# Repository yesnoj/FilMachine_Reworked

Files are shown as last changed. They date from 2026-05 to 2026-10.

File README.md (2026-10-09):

# FilMachine — Automated Film Development Machine

FilMachine is an automated film processing machine designed for photographic film development. It handles the entire process: chemical baths, water rinses, temperature regulation, and motor-driven film agitation — all controlled through a 4.3" color touchscreen display.

The project includes a **desktop simulator** (SDL2 + LVGL) that reproduces the full touchscreen UI on macOS/Linux (a Windows build is produced by CI), enabling rapid development and testing without physical hardware, plus an **automated test suite** (19 suites). A **Flutter companion app** connects via WebSocket and provides full remote control from any mobile device on the same network.

The interface is **bilingual (English / Italiano)** — selectable from Settings, applied with an automatic reboot — and every boot writes a **diagnostic log to the SD card** (`/log/boot_NNNN.txt`), including the crash summary of the previous run when the firmware panicked.

The repository also holds the mechanical side of the project: the 3D-printed **film reel auto-loader** (bench prototype v1, for 135 and 120 film) — see [Film Reel Auto-Loader](#film-reel-auto-loader-3d-printed-prototype).

---

## Table of Contents

1. [What is FilMachine?](#what-is-filmachine)
2. [Project Architecture](#project-architecture)
3. [Directory Structure](#directory-structure)
4. [Building the Project](#building-the-project)
5. [Running the Simulator](#running-the-simulator)
6. [Running the Tests](#running-the-tests)
7. [WebSocket Server & Remote Control](#websocket-server--remote-control)
8. [Flutter Companion App](#flutter-companion-app)
9. [User Interface Guide](#user-interface-guide)
10. [Firmware Update (OTA)](#firmware-update-ota)
11. [Hardware Specifications](#hardware-specifications)
12. [Bill of Materials (Components)](#bill-of-materials-components)
13. [Film Reel Auto-Loader (3D-Printed Prototype)](#film-reel-auto-loader-3d-printed-prototype)
14. [Diagnostics & Bring-up Page](#diagnostics--bring-up-page)
15. [Build-time Switches](#build-time-switches)
16. [Configuration & Persistence](#configuration--persistence)
17. [Language / Localization](#language--localization)
18. [SD Boot & Crash Log](#sd-boot--crash-log)
19. [Typical Workflows](#typical-workflows)
20. [Developer Quick Reference](#developer-quick-reference)
21. [Authors](#authors)

---

## What is FilMachine?

FilMachine takes the guesswork out of developing photographic film at home or in a small lab. Instead of manually timing each step, pouring chemicals by hand, and constantly checking the thermometer, FilMachine automates everything. You load your film in the developing tank, select a process, and press Start. The machine takes care of the rest: filling the right chemical at the right time, keeping the temperature stable, rotating the film at the correct speed, rinsing between steps, and alerting you when the process is complete.

It supports both **color negative** (C41, E6) and **black & white** film development workflows, with full customization of every parameter.

---

## Project Architecture

The project has a **dual-target build system** that produces ESP32-P4 firmware or a native desktop application from the same codebase. The only supported hardware board is the **Guition JC4880P433** (ESP32-P4).

### Technology Stack

| Layer | Firmware (ESP32-P4) | Simulator (macOS/Linux) |
|---|---|---|
| **UI Library** | LVGL 9.5.0 | LVGL 9.5.0 (identical) |
| **Display** | ST7701S 480×800 MIPI-DSI → landscape 800×480 via PPA | SDL2 window (800×480) |
| **Touch Input** | GT911 (physical 480×800 → remapped to 800×480) | SDL2 mouse events |
| **Storage** | FatFS on MicroSD (SDMMC 4-bit, ~40 MB/s) | POSIX file I/O (sd/ directory) |
| **RTOS** | FreeRTOS (ESP-IDF) | Stub (queues work, tasks are no-ops) |
| **2D Acceleration** | PPA hardware engine (rotate, scale, blend, fill) | — |
| **Audio** | ES8311 codec via I2S + power amplifier | — |
| **Temp Sensors** | DS18B20 OneWire | Simulated (20°C ambient, heater model) |
| **Motor/Pump** | DBH-12V dual H-bridge (motor ch.A + pump ch.B) + MCP23017 solenoid driver | printf stubs |
| **OTA Updates** | esp_ota_ops + esp_http_server | Simulated (progress timer) |
| **Build Tool** | ESP-IDF (`idf.py`) | CMake + Make |
| **Sensors** | Flow meter, water level, hall effect | Simulated |
| **Compiler** | riscv32-esp-elf-gcc | Native cc/gcc/clang |

### How the Simulator Works

The simulator replaces all hardware-specific code with a **stub layer** that provides compatible implementations:

- **FatFS stubs** map firmware paths (e.g., `/FilMachine.json`) to files inside an `sd/` subdirectory of the directory the simulator is launched from, so read/write operations work transparently.
- **FreeRTOS stubs** provide working queue implementations (xQueueCreate, xQueueSend, xQueueReceive) using simple circular buffers. Task creation is a no-op since there are no real threads — instead, the main loop drains the system queue every frame.
- **Hardware stubs** (GPIO, I2C, SPI, solenoid driver, motor, temperature) are either no-ops or printf-based logging functions. Temperature readings come from a simple thermal model that simulates heating/cooling.
- **OTA stubs** simulate the firmware update flow with a progress timer (0→100%) and fake IP address, allowing full UI testing without real hardware.
- **LVGL's SDL2 driver** provides the display backend and mouse input, which simulates the capacitive touchscreen.

The key architectural principle is that **all UI code is shared 1:1** between firmware and simulator. Pages, elements, event handlers, and business logic are identical — only the hardware abstraction layer changes.

---

## Directory Structure

```
FilMachine_Reworked/
│
├── main/                          # Core source (shared with ESP32 firmware)
│   ├── include/
│   │   └── FilMachine.h           #   Main header — all structs, enums, constants, prototypes
│   ├── FilMachine.c               #   ESP32 entry point — board-conditional display/touch init
│   ├── accessories.c              #   Utilities — linked lists, deep copy, config I/O, keyboard
│   ├── lang.c                     #   EN/IT string table (generated by scripts/gen_lang.py)
│   ├── sd_log.c                   #   Boot/crash logger on SD (/log/boot_NNNN.txt, firmware only)
│   ├── mini_json.c                #   Dependency-free JSON parser for the config file
│   ├── ota_update.c               #   OTA firmware update (SD card + Wi-Fi web server)
│   ├── ws_server.c                #   WebSocket server for Flutter companion app
│   ├── film_loader.c              #   Film loading cycle (wind, stall detect, cut, tail) — Tools → Load film
│   └── ui_profile.c               #   Centralized UI layout constants (800×480)
│
├── c_pages/                       # UI pages (screens)
│   ├── page_splash.c              #   Splash screen — standard, random, and custom modes with
│   │                              #     10 palettes, 6 shape styles, 9 title fonts, PRNG engine
│   ├── page_menu.c                #   Tab bar navigation (Processes / Settings / Tools)
│   ├── page_processes.c           #   Process list with filtering
│   ├── page_processDetail.c       #   Process creation & editing
│   ├── page_stepDetail.c          #   Step creation & editing with validation
│   ├── page_settings.c            #   Machine settings, grouped in sections (process, rotation, liquids, display, system)
│   ├── page_tools.c               #   Maintenance tools, import/export, statistics, OTA
│   ├── page_checkup.c             #   Process execution — the most complex page
│   └── page_debug.c               #   Hidden diagnostics / bring-up page (live sensors, output tests)
│
├── c_elements/                    # Reusable UI components
│   ├── element_process.c          #   Process list item (drag, delete, duplicate)
│   ├── element_step.c             #   Step list item (swipe gestures, edit/delete)
│   ├── element_filterPopup.c      #   Filter dialog (name, type, preferred)
│   ├── element_messagePopup.c     #   Generic confirmation/alert popups
│   ├── element_rollerPopup.c      #   Numeric selector (roller) widget
│   ├── element_calibPopup.c       #   Dual temperature calibration popup (bath + chemistry offsets)
│   ├── element_speedPopup.c       #   Pump / motor speed tuning popup with live test
│   ├── element_fillPopup.c        #   Maintenance "Fill bath" popup (auto-stop on level, flow or timeout)
│   ├── element_loadPopup.c        #   Film loading popup (135/120, progress, Cut now, blade test)
│   ├── element_cleanPopup.c       #   Cleaning process UI with timer
│   ├── element_drainPopup.c       #   Drain process UI with animated tank bars
│   ├── element_splashPopup.c      #   Splash screen config popup with live preview
│   ├── element_selfcheckPopup.c   #   Self-check diagnostic wizard (8-phase hardware test)
│   ├── element_otaWifiPopup.c     #   Wi-Fi OTA update popup (IP + PIN + progress)
│   └── element_wifiPopup.c       #   Wi-Fi connection popup (scan, connect, status)
│
├── c_fonts/                       # Custom icon fonts (7 sizes: 15/20/30/40/50/60/100px)
│   │                              #   + 8 custom splash title fonts (48px) + Montserrat 64
├── drivers/                       # Custom peripheral drivers (ESP-IDF compatible)
│   ├── include/                   #   Driver headers (mcp23017.h, ds18b20.h, sensors.h, audio.h, servo.h)
│   ├── mcp23017.c                 #   I2C 16-bit I/O expander (Adafruit solenoid driver)
│   ├── ds18b20.c                  #   OneWire temperature sensor (shared bus)
│   ├── audio.c                    #   ES8311 codec bring-up + tone/volume (board only)
│   ├── servo.c                    #   Cutter servo, LEDC 50 Hz PWM on GPIO 28 (board only)
│   └── sensors.c                  #   Flow meter, water level, hall effect sensors (+ reel pulse counter)
│
├── components/                    # ESP32-P4 specific hardware drivers
│   ├── st7701_lcd/                #   ST7701S MIPI-DSI LCD driver (480×800)
│   ├── ppa_engine/                #   PPA hardware 2D accelerator (rotate, scale, fill, blend)
│   ├── driver/                    #   ESP-IDF driver compatibility shims
│   └── espressif__esp_lcd_touch/  #   Touch panel abstraction layer
│
├── src/
│   └── main.c                     # Simulator entry point (SDL2 display, main loop,
│                                  #   demo data generator, system queue drain)
│
├── stub/                          # Hardware abstraction for simulator
│   ├── esp_stubs.h/c              #   ESP32 GPIO, timer, heap stubs
│   ├── fatfs_stubs.h/c            #   FatFS → POSIX filesystem mapping
│   ├── freertos_stubs.h/c         #   Queue stubs (circular buffer), task stubs (no-op)
│   ├── driver/                    #   GPIO, I2C, LEDC, SDMMC driver stubs
│   └── (redirect headers)         #   Thin #include wrappers for ESP-IDF compatibility
│
├── tests/                         # Automated test suite
│   ├── test_runner.h/c            #   Test framework & entry point
│   ├── test_helpers.c             #   Touch input simulation
│   ├── test_navigation.c          #   Splash, menu, tab switching
│   ├── test_processes.c           #   Process list display & creation
│   ├── test_process_crud.c        #   Process create/read/update/delete
│   ├── test_steps.c               #   Step creation, swipe, deletion
│   ├── test_step_crud.c           #   Step lifecycle
│   ├── test_execution.c           #   Process checkup execution flow
│   ├── test_persistence.c         #   Config save/load/restore
│   ├── test_settings.c            #   Settings UI & validation
│   ├── test_filter.c              #   Filter logic
│   ├── test_tools.c               #   Maintenance tools
│   ├── test_edge_cases.c          #   Boundary conditions & error paths
│   ├── test_utilities.c           #   Helper function tests
│   ├── test_ota.c                 #   OTA update UI & Wi-Fi popup tests
│   ├── test_websocket.c           #   WebSocket command tests
│   ├── test_new_settings.c        #   Extended settings tests
│   ├── test_selfcheck.c           #   Self-check wizard tests
│   ├── test_live_sync.c           #   Live sync integration tests
│   ├── test_ui_profile.c          #   UI profile validation & sensor stubs
│   ├── test_film_loader.c         #   Film loader state machine, safety checks, popup
│   ├── test_maintenance_remote.c  #   Drain / Clean / Export driven by WebSocket commands
│   └── test_destroy_and_lifecycle.c # Memory cleanup & object destruction
│
├── lvgl/                          # LVGL 9.5.0 library (auto-cloned on first build, gitignored)
├── lvgl_config/
│   └── lv_conf.h                  # LVGL configuration (RGB565, C-library malloc as on the board, dark theme)
│
├── boards/                        # Board-specific hardware definitions
│   ├── board.h                    #   Board selector (includes correct board header)
│   ├── board_jc4880p433.h         #   JC4880P433 pin assignments, peripherals, H-bridge config
│   └── board_simulator.h          #   Simulator stubs (matching pin constants)
│
├── scripts/
│   ├── genFilMachineCFG.py        # SD config generator (FilMachine.json with realistic film recipes)
│   ├── gen_lang.py                # EN/IT string table generator (holds the Italian dictionary)
│   └── bump_version.sh            # Increments the BUILD field of version.txt
│
├── hardware/
│   └── FilMachine_Breakout_v1/    # KiCad project + BOM: breakout board for the Expand IO header
│
├── 3D_Models/
│   └── FilMachine_caricatore_v1/  # 3D-printed film reel auto-loader: STEP, STL, previews,
│                                  #   CadQuery source and its own README (in Italian)
│
├── docs/
│   └── hardware_architecture.svg  # System architecture diagram (shown under Hardware Specifications)
├── tools/
│   └── lvgl_splash_generator.jsx  # Splash-screen generator (React component that emits LVGL C code)
├── data/                          # Sample SD config files (FilMachine.json + legacy .cfg), not used by the build
├── .github/workflows/
│   └── windows-sim.yml            # CI: builds the simulator for Windows (MSYS2/MinGW)
│
├── CMakeLists.txt                 # Dual-target build (ESP-IDF P4 + simulator/tests)
├── version.txt                    # Firmware version, MAJOR.MINOR.PATCH.BUILD (single source of truth)
├── partitions.csv                 # Custom OTA partition table (16 MB flash)
├── sdkconfig.defaults             # ESP-IDF shared defaults
├── sdkconfig.defaults.esp32p4     # ESP-IDF defaults for ESP32-P4 target
├── flash_p4.sh                    # All-in-one build + flash + monitor for the ESP32-P4 board (macOS)
├── ui_debug_registry.inc          # Widget-name registry for the simulator's F2 debug overlay
├── COMMANDS.md                    # Quick command reference (in Italian)
├── AUDIT_REPORT.md                # Firmware/app audit of 6 July 2026 (firmware v0.0.0.50)
├── FilMachine_Custom_PCB_BOM.xlsx # Design worksheet for a custom PCB: BOM, pin maps, power budget (in Italian)
├── DistintaComponenti.xlsx        # Parts list with specs, quantities, prices and links (in Italian)
├── MDC_db.csv                     # Film/developer development-time table (9,142 rows; not read by the firmware yet)
├── setup.sh                       # Legacy: one-off script that built the old Simulator_v2 folder (not needed)
└── flash.sh                       # Legacy: ESP32-S3 flash through the old FilMachine_Pete repo (not for the P4)
```

---

## Building the Project

### Prerequisites

**macOS:**
```bash
brew install cmake sdl2 pkg-config
```

**Ubuntu / Debian:**
```bash
sudo apt install cmake libsdl2-dev pkg-config build-essential
```

LVGL v9.5.0 is automatically cloned from GitHub on the first build if not present (the firmware pulls the same version through the ESP-IDF component manager, `lvgl/lvgl ~9.5.0`).

**Windows:** there is no local recipe; the GitHub Actions workflow `.github/workflows/windows-sim.yml` builds `filmachine_sim.exe` with MSYS2/MinGW on every push to `main` that changes more than the documentation (or on demand from the Actions tab) and uploads it — with its runtime DLLs and a freshly generated `sd/` config — as the `filmachine-sim-windows` artifact.

### Build the Simulator

```bash
mkdir -p build800 && cd build800
cmake ..
make filmachine_sim
```

The simulator opens an 800×480 window matching the JC4880P433 physical panel in landscape orientation.

### Build the Tests

```bash
mkdir -p build800 && cd build800
cmake ..
make filmachine_test
./filmachine_test
```

### Build the Firmware

Requires the [ESP-IDF](https://docs.espressif.com/projects/esp-idf/en/latest/) toolchain (**v5.5.x** or later) installed and configured.

**Important:** run `idf.py` from the **project root**, not from `build800/`.

```bash
cd FilMachine_Reworked
. $HOME/esp/esp-idf-v5.5/export.sh     # Must be ESP-IDF 5.5.x or later

# First-time setup: set target to esp32p4 (creates sdkconfig from defaults)
idf.py set-target esp32p4

# Build — board is auto-detected from IDF_TARGET
idf.py build
```

The `main/CMakeLists.txt` automatically sets `-DBOARD_JC4880P433`. No manual `-DCMAKE_C_FLAGS` flag is needed (passing `-D CMAKE_C_FLAGS="-DBOARD_JC4880P433"` is harmless but redundant).

> **See [`COMMANDS.md`](COMMANDS.md)** for the canonical quick reference: simulator + board build, flash/monitor, generating and copying the SD config, version bumping and cleanup.

#### Flash and monitor

The firmware binary is produced at `build/FilMachine.bin`. To flash it directly to a connected board:

```bash
idf.py flash
```

Or use the all-in-one helper (written for macOS), which sets the target if needed, patches `sdkconfig` for the P4 board, increments the build number in `version.txt`, builds, looks for the serial port, flashes and opens the monitor:
```bash
./flash_p4.sh
```

> `flash.sh` and `setup.sh` are leftovers of the earlier ESP32-S3 workflow (they copy sources between the old `FilMachine_Simulator_v2` folder and the `FilMachine_Pete` repository). They are not used for the ESP32-P4 and can be ignored.

**P4 note:** the bootloader offset on ESP32-P4 is `0x2000` (different from ESP32-S3's `0x0`). This is handled automatically by `idf.py` when the target is set correctly.

To check the firmware size (useful for verifying OTA partition fit):
```bash
idf.py size
```

---

## Running the Simulator

### Simulator UI debug overlay

The simulator includes a built-in UI inspection mode to speed up layout tuning.

- Press **F2** to enable or disable the overlay.
- When enabled, moving the mouse over the UI shows:
  - the resolved component name when available (for example `gui.page.processes.newProcessButton`)
  - the object position (`x`, `y`)
  - the object size (`w`, `h`)
- While the overlay is enabled, **right click** dumps the hovered object to the terminal/console.

This is especially useful when adjusting coordinates inside `ui_profile.c`, because you can identify the exact widget and immediately see its current geometry in the simulator.

```bash
cd build800
./filmachine_sim
```

The simulator opens an 800×480 window that reproduces the exact touchscreen interface. Use the mouse to simulate touch input (click = tap, click-drag = swipe/scroll).

### What works in the simulator

- Full UI navigation (all pages, popups, dialogs)
- Splash screen with live preview popup, 10 palettes, 6 shape styles, 9 custom fonts
- Process creation, editing, duplication, deletion
- Step management with swipe gestures
- Settings with slider/switch/radio controls
- Filter and search functionality
- Configuration save/load (reads/writes `sd/FilMachine.json`)
- Export/Import (backup to `sd/FilMachine_Backup.json`)
- Drain machine with animated tank-level bars and relay management
- Clean machine with per-container rinse cycles and arc progress
- Self-check diagnostic wizard with 8-phase hardware test simulation (temp sensors, pump, heater, valves, containers, motor)
- OTA update UI (SD card check + Wi-Fi popup with simulated IP/PIN/progress)
- Simulated temperature readings with heater model and calibration offset
- Persistent alarm sound (SDL audio 880Hz beep, repeats every 10s until dismissed)
- Drain/fill overlap processing (adjusts step timing based on overlap percentage)
- Machine statistics persistence (saved in config file, survives restart)
- Temperature sensor calibration (Tune button calculates and applies offset)
- Console logging of all system actions (`[SIM] sysAction: ...`)
- WebSocket server on port 81 for Flutter companion app remote control
- Full remote process start, stop, and checkup advance via WebSocket
- Remote CRUD for processes and steps (create, edit, delete from Flutter)

### What is simulated (no real hardware)

- Temperature sensors return simulated values (20°C ambient, gradual heating/cooling)
- Motor control outputs to console only
- Relay switching outputs to console only
- OTA writes to a fake partition (progress simulated, no actual flash)
- Wi-Fi connection is simulated (fake IP 192.168.1.42, no real server)
- Reboot is a no-op (prints message)

### Generating sample data

To generate realistic film development recipes:

```bash
python3 scripts/genFilMachineCFG.py --realistic --output build800/sd/
```

This creates config files with authentic C41, E6, and B&W development processes.

---

## Running the Tests

```bash
cd build800
./filmachine_test
```

Results are displayed in the terminal and saved to `test_results/test_results_YYYYMMDD_HHMMSS.txt`.

### Test Suites

| Suite | Description |
|---|---|
| **Navigation** | Splash screen, menu display, tab switching |
| **Processes** | Process list rendering, creation UI |
| **Process CRUD** | Full create/read/update/delete lifecycle |
| **Steps** | Step creation, swipe gestures, deletion |
| **Step CRUD** | Step lifecycle with validation |
| **Execution** | Process checkup and execution flow |
| **Persistence** | Config save → reload → verify all fields, stats persistence, calibration offset |
| **Settings** | Settings UI, default values, slider/switch behavior, calibration, alarm |
| **Filter** | Filter by name, film type, preferred flag |
| **Tools** | Cleaning, draining, statistics display, timer pause/resume, alarm functions |
| **Edge Cases** | Boundary conditions, max limits, error recovery |
| **Utilities** | Helper functions, linked list operations, drain/fill overlap calculation |
| **UI Profile & Sensors** | Profile values match original, popup dimensions, font pointers, sensor stubs, board constants |
| **OTA** | OTA update UI, Wi-Fi popup PIN generation, progress popup |
| **WebSocket** | WebSocket command handling, async LVGL dispatch |
| **New Settings** | Extended settings validation |
| **Self-check** | Self-check diagnostic wizard phases |
| **LiveSync** | Live sync between WebSocket state and LVGL UI |
| **Destroy & Lifecycle** | Memory cleanup, object destruction |
| **Film loader** | Loading cycle 135/120, early stall / no spin / too long errors, Cut now, Stop, blade test, popup from the app |
| **Maintenance from the app** | Drain and Clean started, stopped and closed by WebSocket commands (popups on the display, state fields), only the selected containers cleaned, one tool at a time, no process while one runs, Export queued with its result in the state |

The persistence tests verify that every field (process name, temperature, tolerance, film type, preferred flag, step names, durations, types, sources, discard flags) survives a full save-and-reload cycle.

**Repeatable runs.** Every run starts from the same data: the runner generates three test processes with the default settings and rewrites `sd/FilMachine.json` in the run directory, so a run never depends on what the previous one saved (steps used to pile up on the first process until the 30-step limit made the step tests fail). `FM_TEST_ONLY=<suite>,<suite>` runs only some suites (names after `test_suite_`, e.g. `FM_TEST_ONLY=navigation,tools`).

**Timers run on real time.** The SDL display makes LVGL read the real clock, so `test_pump()` processes events but does not advance LVGL timers; tests that wait for a 1 s timer sleep (see `pump_real()` in `test_maintenance_remote.c`).

**Memory.** The simulator and the tests use the C-library `malloc` for LVGL, like the board. With LVGL's own 256 KB pool the heap fragmented after a few suites, an allocation failed and LVGL's malloc assert spun forever, which looked like random hangs in the step tests. To check memory errors, build the runner with `-fsanitize=address`: AddressSanitizer then sees LVGL's allocations too.

---

## WebSocket Server & Remote Control

The simulator and firmware include a built-in WebSocket server (`ws_server.c`) that enables remote control from the Flutter companion app or any WebSocket client. The server starts automatically and listens on **port 81** at path `/ws`.

### Supported Commands

All commands use JSON format: `{"cmd":"command_name", ...params}`.

| Command | Parameters | Description |
|---|---|---|
| `get_state` | — | Returns full machine state (settings, runtime, temperatures, progress, alarms, maintenance fill, film loader, drain, clean and export status) |
| `get_processes` | — | Returns complete process list with steps, indexed for remote referencing |
| `start_process` | `index` | Start a process by list index; initializes checkup and begins execution |
| `checkup_advance` | — | Advance to next checkup phase (Setup → Fill → Temp → Check → Processing) |
| `stop_now` | — | Immediately halt the running process and drain |
| `stop_after` | — | Stop after the current step completes |
| `close_process` | — | Close a finished/stopped process and free checkup resources |
| `create_process` | `name, temp, tolerance, filmType, tempControlled, preferred` | Create a new process |
| `edit_process` | `index, name, temp, tolerance, filmType, tempControlled, preferred` | Edit an existing process |
| `delete_process` | `index` | Delete a process |
| `add_step` | `processIndex, name, mins, secs, type, source, discard` | Add a step to a process |
| `edit_step` | `processIndex, stepIndex, name, mins, secs, type, source, discard` | Edit a step |
| `delete_step` | `processIndex, stepIndex` | Delete a step |
| `reorder_step` | `processIndex, from, to` | Move a step within a process |
| `set_setting` | `key, value` | Update a machine setting (see key list below) |
| `reset_defaults` | — | Restore all settings to factory defaults |
| `wifi_scan` | — | Scan for Wi-Fi networks; results arrive via a `wifi_scan_results` event |
| `fill_start` / `fill_stop` | `target` (0 = water bath, 1 = chemistry) | Maintenance fill (self-calibrates the fill time; refused with `fill_rejected` while a process runs) |
| `tune_test` / `tune_set` / `tune_cancel` | `kind` (0 pump, 1 motor, 2 volume), `percent`, `on` | Live test, store or cancel a Tune value |
| `drain_start` / `drain_stop` / `drain_close` | — | Drain machine: start (no confirm page, the app asks), Stop, Close after the end (alarm off, popup closed). Refused with `drain_rejected` while a process or another maintenance tool runs |
| `clean_start` | `mask` (bit0 C1, bit1 C2, bit2 C3), `cycles` (1–5), `drainWb` | Clean machine with these choices (shown on the display popup). Refused with `clean_rejected` (`processing`, `busy`, `no_container`) |
| `clean_stop` / `clean_close` | — | Clean: Stop (the container is pumped back first) / Close after the end |
| `export_config` | — | Export configuration and processes to the backup file on the SD card; the result arrives as `exportSeq` / `exportOk` in the state |
| `load_start` | `format` (0 = 135, 1 = 120) | Start loading the film onto the reel (refused with a `load_rejected` event while a process runs or a load is in progress) |
| `load_stop` | — | Stop the loading (motor off, blade back to rest) |
| `load_cut` | — | Cut now, without waiting for the reel to stop |
| `cutter_test` | `angle` (0–180) | Hold the cutter servo at that angle for a few seconds (setup) |
| `cutter_cycle` | — | One blade up/down cycle, motor off |

The `cleanTool*` state fields include `cleanToolProcessArc`, `cleanToolCycleArc` and `cleanToolPumpArc`: the values of the three arcs exactly as drawn on the display's Clean popup, so the app draws the same picture.

**`set_setting` keys** — `tempUnit`, `waterInlet`, `tempCalibOffset`, `chemCalibOffset`, `filmRotationSpeed`, `rotationInterval`, `random`, `persistentAlarm`, `autostart`, `drainFillOverlap`, `multiRinseTime`, `lineRinseEnabled`, `lineRinseTime`, `tankSize`, `pumpSpeed`, `chemCalibFillSecs`, `wbCalibFillSecs`, `chemistryVolume`, `invertPump`, `brightness`, `volume`, `splashDefault`, `splashRandom`, `splashPalette`, `splashShapeStyle`, `splashComplexity`, `language` (0=EN, 1=IT — applied at next boot), `screenOffMins` (5/10/30, 0=never), `wifiEnabled`, `loadSpeed` (reel motor % while loading), `cutterRestUs` / `cutterCutUs` (servo pulse in µs at rest and at the top of the cut). All of these are also included in the broadcast state JSON.

### Implementation Details

The server uses simple `strstr()` JSON parsing with no external library (no cJSON, no heap allocation for parsing). All commands that modify LVGL state are dispatched via `lv_async_call()` to ensure thread-safe UI updates. State changes are automatically broadcast to all connected clients.

---

## Flutter Companion App

The companion app is a Flutter application that provides full remote control of FilMachine from any mobile device or desktop on the same network. It lives in its own repository, [FilMachine_App](https://github.com/yesnoj/FilMachine_App) (private); see its README for detailed documentation.

**Keeping the two in step.** The app mirrors the protocol implemented in `main/ws_server.c`. Whenever a field is added to `build_state_json()` or a key to `set_setting`, the app needs the same addition in its `MachineState` model, in `MachineService._readSetting` and in its Settings screen. The app release synced with firmware v0.0.0.54 parses all 71 state fields and sends all 17 commands; the only `set_setting` keys it never sends are the fill calibrations (read-only in the app) and `wifiEnabled`.

### Key Features

- **Device Discovery**: Automatic mDNS discovery of FilMachine devices on the local network (`_filmachine._tcp`), plus manual IP/port entry
- **Process Management**: Create, edit, duplicate, and delete processes and steps — all changes sync to the machine in real-time
- **Live Execution Monitoring**: Real-time dashboard showing current step, progress bars, temperatures, tank fill status, and elapsed/remaining time
- **Process Control**: Start processes, advance through checkup phases, Stop Now / Stop After with confirmation dialogs
- **Filtering**: Client-side filtering by name, film type (B&W / Color), and preferred flag
- **Statistics**: View completed processes, stopped processes, total development time, cleaning cycles
- **Settings**: Full access to the machine settings, with the same sections as the display (Process, Film rotation, Pump and liquids, Display and sound, System) plus the app's own options
- **Tools**: A Tools tab laid out like the display's: Maintenance (Clean machine, Drain machine, Fill bath, Fill chem, Load film), Utilities (Export) and Software (Credits). Self-check, Import (it reboots the machine) and the firmware updates (the Wi-Fi one shows a PIN on the display on purpose) stay on the display; statistics, version and serial number are on the app's Dashboard
- **Theme**: Dark/light theme toggle with custom FilMachine color palette
- **Persistent Connection**: Remembers last successful connection for quick reconnect

### Architecture

The app uses **Provider** for state management. A central `MachineService` (ChangeNotifier) maintains the WebSocket connection and holds the current `MachineState` — a data class with one field per key of the JSON state broadcast. All screens rebuild reactively when state changes.

---

## User Interface Guide

### The Processes Tab

This is where you manage your film development recipes. Each process is a sequence of steps the machine executes in order. The list shows each process with its name, total time, film type icon, and a star if marked as preferred.

- **Process count:** The section header dynamically shows the number of processes (e.g., "8 Processes"). The "+" button stays positioned right after the label text regardless of the count.
- **Create:** Tap "+" to add a new process
- **Edit:** Tap a process to open its detail view
- **Duplicate:** Swipe left to reveal the duplicate button
- **Delete:** Open the detail, tap the trash icon
- **Filter:** Tap the filter icon to search by name, film type, or preferred status. The filter icon turns green when a filter is active, and returns to white when reset.

### Working with Steps

Each process contains steps. A step represents one phase: "Developer", "Stop Bath", "Fixer", "Wash", etc.

For each step you configure: name, duration (minimum 30 seconds), chemical type (Chemistry / Rinse / Multi-Rinse), source container (C1, C2, C3, or WB), and whether to discard the chemical after use.

The three step types behave differently during execution: a **Chemistry** step fills once from a container and soaks for the whole step time (liquid recovered or discarded per the flag). A **Rinse** step fills once (from any source), soaks, and always discards to waste at the end. A **Multi-Rinse** step is not a single soak: the tank is repeatedly filled with fresh water (always from the water bath), agitated for one *cycle* — the "Multi-rinse cycle time" setting — then fully drained to waste, over and over until the step's total duration elapses. If the total time isn't an exact multiple of the cycle time, the last cycle runs longer so the step still ends exactly on time. This matches the Adeo dev.a behaviour and is ideal for final washes where the water must be changed frequently.

- **Add:** Tap "+" below the step list
- **Edit:** Tap a step to modify it
- **Duplicate:** Swipe left on a step
- **Delete:** Swipe left to reveal the delete button
- **Reorder:** Long-press and drag

### Running a Process (Checkup)

Open a process and tap Play. The machine walks through pre-flight checks, then executes each step automatically.

**Pre-flight checks:** tank size selection, water bath fill, tank presence verification, motor check, and temperature stabilization (for temperature-controlled processes).

**During execution:** the screen shows the current step name and remaining time, chemical source, current/target temperature, and upcoming steps.

**Stopping:** "Stop now!" halts immediately (potentially unsafe). "Stop after!" waits for the current step to finish — the safer choice.

### Splash Screen

The splash screen appears at boot and supports three modes, configured via Settings → Splash Screen:

**Use Default** — The built-in "Deep Ocean" splash: a hand-tuned composition with a teal-to-navy gradient, geometric shapes, and the "FILMACHINE" title in Montserrat 48. This is the factory default.

**Random next boot** — Each boot generates a completely new splash from scratch using a tick-derived seed. The PRNG (xorshift32) deterministically selects a palette, shape style, complexity, title position, and title font — producing a unique visual identity every time the machine starts.

**Custom** — Fine-tune the splash parameters manually: Palette (10 options), Shape Style (6 options), and Complexity (20–100 in steps of 20). The popup shows a live preview of the current configuration as the background behind its own controls, with a dark overlay for readability. Press the Random button to regenerate all parameters at once; if you like the result, it will be applied at next boot. The preview shows only the shape background (no title or play button) so you can evaluate the pattern clearly.

**Title fonts** — In Random and Custom modes, the title "FILMACHINE" is rendered with one of 9 fonts selected by the PRNG:

| Index | Font Name | Style |
|---|---|---|
| 0 | Montserrat 48 | Default sans-serif (same as Deep Ocean) |
| 1 | Air Americana | Bold italic display |
| 2 | Decaying Felt Pen | Hand-drawn brush effect |
| 3 | DS Digital | LED/LCD digital display |
| 4 | Evanescent | Ethereal and elegant |
| 5 | Nerdropol Lattice | Geometric/tech |
| 6 | Retrolight | Retro/vintage |
| 7 | Tropical Leaves | Decorative botanical |
| 8 | Wishful Melisande | Calligraphic script |

All fonts are converted from TTF/OTF to LVGL `.c` bitmap arrays using `lv_font_conv` with `--no-compress --bpp 4 --range 0x20-0x7F` (ASCII only, ~20–40KB each in flash).

**Palettes** — Cyberpunk, Aurora, Lava, Deep Ocean, Forest, Sunset, Machinery, Arctic, Neon, Pastel. Each defines a top/bottom gradient, 3 shape accent colors, and text/accent colors for the title.

**Shape Styles** — Overlapping Rects, Circles & Arcs, Mixed Shapes, Diagonal Bands, Grid Blocks, Radial Arcs.

### The Settings Tab

The settings are grouped in sections, like the Tools tab; the whole page scrolls with its section titles. The app's Settings screen uses the same groups and the same wording.

| Section | Setting | Description | Range |
|---|---|---|---|
| Process | Process autostart | Auto-start when temperature reached | On/Off |
| Process | Persistent alarm | Alarm sounds until acknowledged | On/Off |
| Process | Temperature unit | °C or °F | — |
| Process | Temp sensor calibration | Calibrate against a reference thermometer. Short-press Tune to set ambient temp, long-press to reset. | Tune button |
| Film rotation | Rotation speed | Film agitation motor RPM | 10–100% |
| Film rotation | Inversion interval | Seconds between motor direction changes | 10–60s |
| Film rotation | Randomness | Random variation on inversion interval | 0–100% |
| Pump and liquids | Tank size | Default developing tank size | S (500ml) / M (700ml) / L (1000ml) |
| Pump and liquids | Chemistry volume | Amount of chemistry used per step | Low / High |
| Pump and liquids | Pump speed | Water pump speed percentage | 10–100% |
| Pump and liquids | Invert pump | Invert H-bridge direction to compensate for pump physical switch position | On/Off |
| Pump and liquids | Water inlet | Automatic water fill if connected | On/Off |
| Pump and liquids | Drain/fill overlap | How much of fill/drain time counts as processing time (100% recommended) | 0–100% |
| Pump and liquids | Multi-rinse cycle time | Duration of each rinse in multi-rinse steps | 60–180s |
| Pump and liquids | Line rinse | Flush the shared pump line with water after each chemistry step | On/Off |
| Pump and liquids | Line rinse time | Duration of the line-rinse flush | 5–60s |
| Display and sound | Brightness | LCD backlight brightness (auto-dim after inactivity; board only) | 10–100% |
| Display and sound | Volume | Speaker volume | 0–100% |
| Display and sound | Screen off timeout | Minutes after the last touch before the screen turns off (dims in two steps first; disabled while a process runs) | 5 / 10 / 30 min / Never |
| Display and sound | Language | Interface language — the machine saves and reboots automatically to apply it | English / Italiano |
| System | Splash Screen | Opens a popup to configure the boot splash (see above) | Default / Random / Custom |
| System | Wi-Fi | Opens the Wi-Fi popup: scan, connect, status (used for OTA updates and the app) | — |
| System | Reset to Defaults | Restores every setting to its factory value | — |

The fill times are not settings any more: they are measured by the Maintenance fills in the Tools tab. The film loader's motor speed and cutter servo pulses (`loadSpeed`, `cutterRestUs`, `cutterCutUs`) are stored with the settings but are not shown on this page; they are set from the app's Load film screen (or in `FilMachine.json`).

All settings are saved automatically to the SD card when changed. Slider values are saved only when you release the slider (not during dragging) to reduce SD card wear.

### The Tools Tab

- **Clean machine** — Automated cleaning cycle: select which containers to clean (C1, C2, C3), set the number of rinse cycles (1–5), and optionally drain the water bath when done. Only the selected containers are cleaned, in order: each cycle fills the container with water from the water bath and then pumps it back, with real-time progress shown via arc animations and remaining-time countdown. Stop pumps the water still in the current container back to the bath before ending. It can also be started, stopped and closed from the app (the popup shows the app's choices).
- **Drain machine** — Drains all containers (C1, C2, C3, WB) to waste sequentially. A confirmation screen lists the affected containers; once started, four colored tank bars animate from full to empty in real time, showing which container is currently draining, a ">> WASTE <<" indicator, and a countdown timer. The drain can be stopped at any time via the Stop button. It can also be started, stopped and closed from the app.
- **Self-check** — Guided hardware diagnostic wizard that tests all machine components in 8 phases: temperature sensors (5s), water pump (10s), heater (30s), valves (10s), the three containers C1/C2/C3 (10s each), and agitation motor (10s). The UI is split in two panels: a task list on the left showing icons per phase (check for done, dot for pending/skipped/stopped) and a detail panel on the right with phase description, real-time sensor data, countdown timer, and a progress bar. Three buttons control the flow: Stop (halts current phase), Start/Re-run (begins or repeats a phase), and Next (skips to the next phase). Each phase's state (done, skipped, stopped) is saved and visible when revisiting. When all phases complete successfully the title shows "Self-check complete!" in green; if any were skipped or stopped it shows "Self-check finished" in orange.
- **Load film** — Loads the film onto the reel with the built-in loader: choose 135 or 120 and press Start. The reel motor winds the film while the Hall sensor counts the turns; when the reel stops at the end of the film, the servo raises the blade and cuts, then half a turn pulls the tail inside and a beep says the tank is ready. *Cut now* cuts at once (e.g. when the 120 tape shows), *Stop* halts everything, and with the machine idle a *Test blade* button runs one blade cycle. The cut is refused if the reel stops too early (clip not hooked) or turns too long, and the motor is checked for rotation right after the start. The same cycle can be started from the app; a process cannot start while a film is loading.
- **Import/Export** — Backup and restore configuration to SD card (Export can also be run from the app; Import reboots the machine and stays on the display)
- **Statistics** — Completed processes, total time, cleaning cycles, stopped processes
- **Software info** — Firmware version (read from the running binary, also shown on the splash screen) and serial number
- **Update from SD** — Firmware OTA update from a `.bin` file on the SD card. The system reads the firmware version from the binary header, asks for confirmation, then writes it to the secondary OTA partition. After completion, a reboot applies the new firmware. If the update fails, the bootloader automatically rolls back to the previous version.
- **Wi-Fi update** — Starts a local web server on the board. A popup shows the board's IP address (e.g. `http://192.168.1.42`) and a randomly generated 8-digit PIN for security. The user opens the URL in any browser on the same network and sees a drag-and-drop upload page styled with the FilMachine branding. After uploading the `.bin` firmware file, it is streamed directly to the OTA partition. The board reboots automatically when complete. Wi-Fi credentials (SSID/password) are configured in the Settings tab.

---

## Firmware Update (OTA)

The board supports two methods for over-the-air firmware updates. Both use the ESP-IDF dual-partition OTA mechanism: the new firmware is written to a secondary partition while the current one keeps running, and the bootloader swaps at reboot. If the new firmware fails to boot, automatic rollback restores the previous version.

### Method 1: SD Card

1. Build the firmware: `idf.py build`
2. Copy `build/FilMachine.bin` to the SD card root, renamed as `FilMachine_fw.bin`
3. Insert the SD card into the machine
4. Go to Tools → "Update from SD" and press the play button
5. Confirm the version shown in the popup
6. Wait for the progress to reach 100%, then reboot

### Method 2: Wi-Fi (Web Upload)

1. Configure Wi-Fi SSID and password in Settings
2. Go to Tools → "Wi-Fi update" and press the play button
3. The popup shows the board's local IP and a 8-digit PIN
4. On any device on the same network, open `http://<board-ip>` in a browser
5. You'll see a drag-and-drop page — drop the `.bin` file or click to select it
6. The firmware uploads in streaming and the board reboots automatically

### Firmware File Format

The `.bin` file is produced by `idf.py build` at `build/FilMachine.bin`. It contains an ESP32 application image with an `esp_app_desc_t` header that stores the firmware version, build date, and SHA-256 hash for integrity verification.

### Partition Table

The project uses a custom partition table (`partitions.csv`) optimized for the 16MB flash chip. Each OTA slot is 6MB, giving ~59% free space with the current firmware size (~2.5MB, measured on a clean build of v0.0.0.54 with the repository defaults).

```
# Name      Type  SubType   Offset      Size
nvs         data  nvs       0x9000      24KB     NVS key-value storage
otadata     data  ota       0xF000       8KB     OTA boot flag (which slot to boot)
phy_init    data  phy       0x11000      4KB     Wi-Fi PHY calibration data
ota_0       app   ota_0     0x20000      6MB     Firmware slot A (active)
ota_1       app   ota_1     0x620000     6MB     Firmware slot B (updated via OTA)
coredump    data  coredump  0xC20000    64KB     Crash snapshot (read into the SD boot log)
(free)      —     —         0xC30000    ~4MB     Unallocated
```

> Note: after adding the `coredump` partition, regenerate the sdkconfig once
> (`rm sdkconfig && idf.py build`) so the `CONFIG_ESP_COREDUMP_*` defaults are
> picked up, then flash normally (`idf.py flash` also rewrites the partition table).

The bootloader alternates between `ota_0` and `ota_1`: the new firmware is written to the inactive slot, and at reboot the bootloader swaps. If the new firmware crashes at startup, automatic rollback restores the previous working version.

### Setting the Firmware Version

The single source of truth is **`version.txt`** in the project root, in the form `MAJOR.MINOR.PATCH.BUILD` (e.g. `0.0.0.54`). ESP-IDF uses it as the application version, so the value shown on the splash and in Tools → Software version is read at runtime from the running binary via `esp_app_get_description()->version`; the simulator gets the same string from `CMakeLists.txt`, which injects it as `FW_VERSION_STR`.

`./flash_p4.sh` increments the BUILD field before every build. To do it by hand:

```bash
./scripts/bump_version.sh          # 0.0.0.54 -> 0.0.0.55
./scripts/bump_version.sh --show   # print the current version without changing it
```

For a real release, edit `version.txt` directly (e.g. `0.1.0.0`).

---

## Hardware Specifications

### System Architecture

<p align="center">
  FilMachine Hardware Architecture
</p>

### Target Board

**Guition JC4880P433** (`-DBOARD_JC4880P433`) — the only supported hardware board.

| Spec | Detail |
|---|---|
| **MCU** | ESP32-P4 (RISC-V dual-core @ 400 MHz) |
| **Flash / PSRAM** | 16 MB / 32 MB |
| **Display** | ST7701S 4.3" IPS, 480×800, MIPI-DSI (2-lane) |
| **LVGL resolution** | 800×480 (landscape, PPA-rotated) |
| **Touch** | GT911 capacitive (I2C) |
| **SD card** | SDMMC 4-bit (~40 MB/s) |
| **Audio** | ES8311 codec + power amplifier |
| **2D accelerator** | PPA (rotate, scale, blend, fill) |
| **Sensors** | Flow meter, water-bath level (min/max), 6× chemical level (3 containers × min/max), Hall effect, 2× DS18B20, chip internal temp |
| **Wi-Fi / BLE** | ESP32-C6 companion chip over SDIO (ESP-Hosted) |
| **ESP-IDF version** | 5.5.x+ |

### Landscape Mode

The JC4880P433's physical display is 480×800 in portrait orientation. FilMachine uses it in **landscape mode at 800×480**. The display pipeline works as follows:

1. LVGL renders the UI into an 800×480 framebuffer
2. The PPA hardware engine rotates the buffer 90° to fill the 480×800 physical panel

Touch coordinates from the GT911 (which reports in 480×800 portrait) are inverse-mapped back to 800×480 LVGL coordinates. All of this is transparent to the UI code.

### Expand IO Header (JP1) — JC4880P433 Pin Assignments

All external peripherals connect through the board's 2×13 Expand IO header (JP1):

| JP1 Pin | GPIO | Function |
|---|---|---|
| 1, 3 | — | VCC 3.3V output (2 pins) — (power) |
| 2, 4 | — | VCC 5V output (2 pins) — (power) |
| 5, 6, 16 | — | GND (3 pins) — (power) |
| 7 | 52 | Flow meter (YF-S201) — (used in code) |
| 8 | 33 | Motor IN1, H-bridge ch.A direction A — (used in code) |
| 9 | 51 | Pump ENA, LEDC PWM speed — (used in code) |
| 10 | 31 | Hall sensor (KY-003), reel turn counter for Load film — (used in code) |
| 11 | 50 | Pump IN2, H-bridge ch.B direction B — (used in code) |
| 12 | 30 | Water level max — (used in code) |
| 13 | 49 | Pump IN1, H-bridge ch.B direction A — (used in code) |
| 14 | 29 | Water level min (XKC-Y21) — (used in code) |
| 15 | 35 | DS18B20 OneWire, 2 sensors on shared bus — (used in code) |
| 17 | 34 | Motor IN2, H-bridge ch.A direction B — (used in code) |
| 18 | — | ESP_3V3 — (power, not used in code) |
| 19 | 32 | Motor ENA, LEDC PWM speed — (used in code) |
| 20 | — | C6_U0RXD (ESP32-C6) — (not used in code) |
| 21 | 28 | Cutter servo (MG90S), 50 Hz PWM — (used in code) |
| 22 | — | C6_U0TXD (ESP32-C6) — (not used in code) |
| 23 | 7 | I2C SDA, shared bus: touch + MCP23017 — (used in code) |
| 24 | — | C6_IO9 (ESP32-C6) — (not used in code) |
| 25 | 8 | I2C SCL, shared bus: touch + MCP23017 — (used in code) |
| 26 | — | C6_CHIP_PU (ESP32-C6) — (not used in code) |

All 12 P4 GPIO pins on JP1 are allocated — GPIO 28, the last spare, now drives the film loader's cutter servo.

### Breakout Board (KiCad)

`hardware/FilMachine_Breakout_v1/` holds a KiCad project (schematic, PCB, the Python script that generates them, an HTML preview) and a BOM for a 70×50 mm two-layer breakout board. It plugs onto the Expand IO header (called J9 in its files) and brings the signals out to 5.08 mm screw terminals — motor, OneWire temperature, flow meter, I2C, water level, Hall sensor and power — plus a 1×8 header for the remaining GPIOs, and it carries the 4.7 kΩ pull-ups for I2C and OneWire. As its `BOM.txt` warns, check the header's power-pin mapping against the actual board with a multimeter before the first power-on.

### Peripheral Drivers

| Component | Detail |
|---|---|
| **Solenoid / IO expander** | Adafruit I2C 8-Ch Solenoid Driver (#6318) — MCP23017 @ 0x20 on the shared I2C bus (GPIO 7/8). Port A drives the valves via on-board MOSFETs; Port B is broken out as raw GPIO and repurposed for level sensors + heater MOSFETs. |
| **Motor Driver** | DBH-12V dual DC motor driver — channel A: agitation motor, channel B: pump |
| **Temperature** | 2× DS18B20 OneWire sensors (water bath + chemical) on one bus (GPIO 35, 4.7 kΩ pull-up) |
| **Pump** | DC pump on DBH-12V ch.B — direction reversal for fill/drain (no pump valves) |
| **Board power** | USB Type-C 5 V (logic) + external 12 V rail for solenoids/motor/pump/heaters (common ground) |

**MCP23017 pin map (I2C `0x20`):**

| Pin | Port | Function |
|-----|---|---|
| 0 | A0 | Valve **C1** |
| 1 | A1 | Valve **C2** |
| 2 | A2 | Valve **C3** |
| 3 | A3 | Valve **WB** (water bath) |
| 4 | A4 | Valve **WASTE** |
| 5–6 | A5–A6 | Spare |
| 7 | A7 | Heater relay (legacy / external relay) |
| 8 | B0 | Chem **C1** level MIN (XKC-Y21) |
| 9 | B1 | Chem **C1** level MAX |
| 10 | B2 | Chem **C2** level MIN |
| 11 | B3 | Chem **C2** level MAX |
| 12 | B4 | Chem **C3** level MIN |
| 13 | B5 | Chem **C3** level MAX |
| 14 | B6 | Heater MOSFET **1** |
| 15 | B7 | Heater MOSFET **2** |

> Port A pins sit behind the #6318 MOSFET drivers (valves). Port B pins are raw push-pull GPIO on the board's bottom edge: **B0–B5** are inputs (pull-up, LOW = water present), **B6–B7** are heater outputs (HIGH = on).

### Chemical Container Layout

| Label | Purpose | Typical Use |
|---|---|---|
| **C1** | Chemical container 1 | Developer |
| **C2** | Chemical container 2 | Bleach / Stop bath |
| **C3** | Chemical container 3 | Fixer |
| **WB** | Water bath | Rinse water (temperature-controlled) |
| **WASTE** | Waste drain | Discarded chemicals |

### Constraints

| Parameter | Limit |
|---|---|
| Max processes | 50 |
| Max steps per process | 30 |
| Process/step name length | 20 characters |
| Minimum step duration | 30 seconds |

---

## Bill of Materials (Components)

Everything the firmware currently expects, for costing a build or a custom board. Quantities are for the standard 3-chemistry layout; prices are intentionally omitted (they move — estimate locally).

Two spreadsheets in the repository root complement this list (both in Italian): `DistintaComponenti.xlsx`, a parts list with specs, quantities, prices and links, and `FilMachine_Custom_PCB_BOM.xlsx`, the design worksheet for a future custom PCB (BOM, JP1 pin map, MCP23017 map, power budget). The MCP23017 map in that worksheet belongs to the custom-board design; the mapping the firmware uses today is the one in [Peripheral Drivers](#peripheral-drivers).

**Controller & storage**

| # | Component | Qty | Role / notes |
|---|---|-----|---|
| 1 | Guition **JC4880P433** board | 1 | ESP32-P4 + 4.3" ST7701S 480×800 display + GT911 touch + ES8311 audio + SDMMC + ESP32-C6 (Wi-Fi/BLE). Main controller + UI. |
| 2 | microSD card | 1 | Config/process storage (`FilMachine.json`). Any small card. |

**Actuation & power drivers**

| # | Component | Qty | Role / notes |
|---|---|-----|---|
| 3 | Adafruit **#6318** I2C 8-ch solenoid driver (MCP23017 @0x20) | 1 | Port A → valves (MOSFET); Port B → level sensors + heater MOSFETs. |
| 4 | Solenoid valve, 12 V | 5 | C1, C2, C3, WB, WASTE. |
| 5 | **DBH-12V** dual DC motor driver (H-bridge) | 1 | Ch. A = agitation motor, ch. B = pump. |
| 6 | DC gear motor, 12 V | 1 | Tank agitation / rotation. |
| 7 | DC pump, 12 V (diaphragm/peristaltic, reversible) | 1 | Fill/drain by direction reversal. |
| 8 | Heater MOSFET module | 2 | Driven from MCP Port B (B6/B7). |
| 9 | Heating element / immersion heater, 12 V | 1–2 | Water-bath heating (thermostat control). |

**Sensors**

| # | Component | Qty | Role / notes |
|---|---|-----|---|
| 10 | **DS18B20** waterproof probe (+ 4.7 kΩ pull-up) | 2 | Water bath + chemical temperature (one OneWire bus). |
| 11 | **XKC-Y21** non-contact level sensor | 8 | WB min+max (2) + 3 chem containers × min/max (6). Need 5 V + signal pulled to 3.3 V. |
| 12 | **Hall** sensor (KY-003 / A3144) | 1 | Tank in-position / rotation; counts the reel turns while loading film. |
| 13 | **YF-S201** flow meter | 1 | Water-bath inlet flow. |

**Power & misc**

| # | Component | Qty | Role / notes |
|---|---|-----|---|
| 14 | 12 V PSU | 1 | Sized for valves + motor + pump + heaters (shared 12 V rail, common GND). |
| 15 | USB-C 5 V | 1 | Board logic power. |
| 16 | Resistors / level-shift, wiring, connectors | — | 4.7 kΩ (DS18B20), pull-ups for XKC-Y21, common ground. |
| 17 | Chemical containers + water bath + waste, tubing, enclosure | — | Mechanical build. |

**Future / diagnostics-ready (optional)**

| # | Component | Qty | Role / notes |
|---|---|-----|---|
| 18 | Resistor dividers 12V/5V/3.3V → ADC1 | 3 | Enables live rail voltages in the diagnostics page (`HAS_RAIL_MONITOR`). |
| 19 | INA219 current sensor (I2C) | 1+ | Current draw per rail/load (not yet wired in firmware). |

---

## Film Reel Auto-Loader (3D-Printed Prototype)

*Bench prototype v1 — files in [`3D_Models/FilMachine_caricatore_v1/`](3D_Models/FilMachine_caricatore_v1/). The original notes, in Italian, are in that folder's [README](3D_Models/FilMachine_caricatore_v1/README.md).*

The loader winds the film onto the reel **from the centre outwards**, like the Rondinax: a motor turns the reel, a leader strip with a clip pulls the film out of the cassette, a guide arm bows it and lays it onto the ribs, and a cutter trims it when the winding is done. Formats: **135 and 120** on the same reel.

<p align="center">
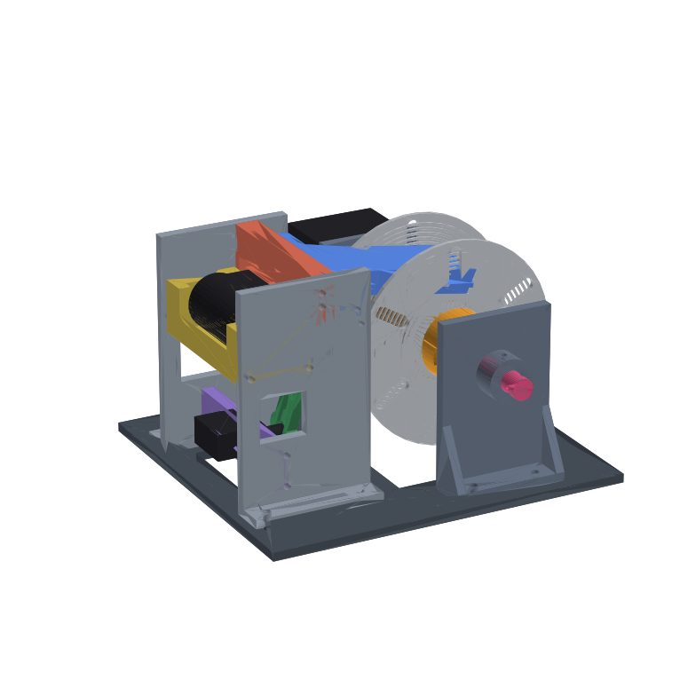
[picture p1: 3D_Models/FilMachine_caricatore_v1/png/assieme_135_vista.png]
Reel auto-loader, assembly for 135 film
  
</p>

> **What it is and what it is not.** It is an *open* test bench for validating the mechanics in daylight with scrap film. It is not yet light-tight or liquid-tight: that is the next phase, to be designed around mechanics that work.

> **Firmware status.** This v1 bench (stepper + pendulum cutter) is not driven by the firmware. The firmware drives the loader built into the machine (v5): Tools → **Load film** (`main/film_loader.c`) winds with the agitation motor, counts the reel turns with the Hall sensor, and cuts with a servo on GPIO 28 — see [The Tools Tab](#the-tools-tab). The sequence in [Planned firmware sequence](#planned-firmware-sequence-starting-values) is kept as the reference for the bench.

### Contents

| Folder | What's inside |
|---|---|
| `step/` | 21 parts as STEP, already in print orientation, plus the assemblies `ASSIEME_135.step` and `ASSIEME_120.step` |
| `stl/` | the same 21 parts as STL |
| `png/` | previews and section views |
| `src/` | parametric model (Python + CadQuery): `python3 build_all.py` regenerates everything |
| `verifiche.txt` | outcome of the geometric checks from the last generation |

Each assembly contains 23 named, coloured bodies: the 19 parts used for that format plus the `REF_` reference shapes (NEMA17 motor, servo, blade, 135 cassette or 120 spool). In Shapr3D every body can be hidden. All part faces are planes, cylinders and cones, so they can be edited directly.

### How It Works

1. **Adjustable reel (parts 01–04).** Same principle as the OpenReel/Paterson reel, adapted to centre-out loading: a central tube with bayonet tracks, two flanges that slide on and lock with a 30° twist in **two positions (35 mm and 120)**, and a central drum with the leader-strip anchor and the clip pocket. The flanges move symmetrically, so the film stays centred in both formats. Outer Ø 93.5 mm and tube bore Ø 26.3 mm, as measured on the OpenReel STEP files. The ribs have no outer lead-in and no ratchet: the film, under tension, rests with its edges on the back of the ribs (0.9 mm per side) and the emulsion touches nothing.
2. **Guide arm (05 for 135, 06 for 120).** It pivots on two screws. Its converging walls squeeze the edges and bow the film into an arc (6.5 mm deep on 135, 8.7 mm on 120): that way it passes between the rib tips and, as soon as it leaves the tip of the arm, it flattens out again and settles on the right turn. The sole rests on the previous turn, so the arm rises by itself as the reel fills. With the reel empty, a stop screw on the cheek plate holds it.
3. **Turret (07–14).** Two cheek plates, the bridge with the film slot and the blade slot, and the cradle for the 135 cassette or the one for the 120 roll (same four screws).
4. **Pendulum cutter (10–12).** A micro servo swings an arm that carries an ordinary **9 mm snap-off cutter blade**: the tip crosses the slot from one side to the other and cuts the film against the ceiling of the bridge, like a sliding trimmer. It cuts the full width, 120 included.
5. **Drive (15–19).** NEMA17 on one upright, a single drive coupling for both formats (a spigot in the tube bore plus two teeth), a plug-type idler pin on the other upright, and the base.
6. **Clip (20–21).** A wedge jaw with a tooth, closed by a slider; it stays in the drum pocket.

<p align="center">
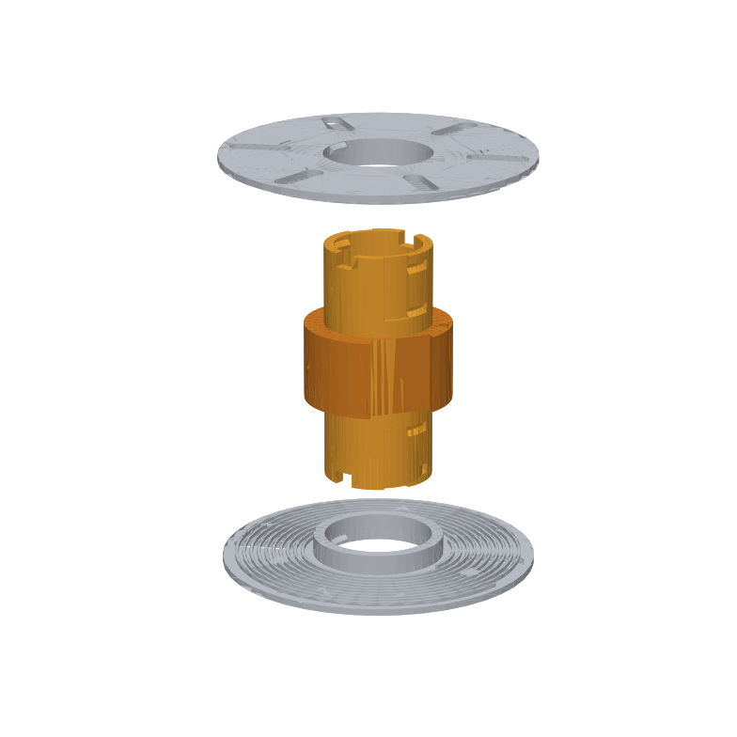
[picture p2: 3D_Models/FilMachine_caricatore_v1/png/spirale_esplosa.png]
Adjustable reel, exploded view
  
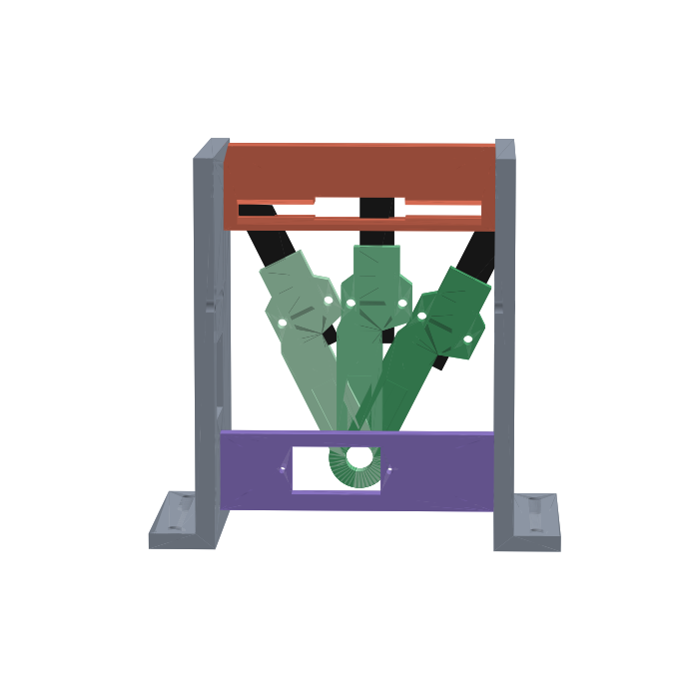
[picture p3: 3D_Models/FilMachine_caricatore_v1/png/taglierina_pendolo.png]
Pendulum cutter at three positions of its sweep
  
</p>

*Left: the adjustable reel, exploded (flanges, bayonet tube with the drum). Right: the pendulum cutter at three positions of its sweep.*

### Printing

PETG, 0.4 mm nozzle. No supports: every part is already oriented.

| Parts | Notes |
|---|---|
| 01, 02 flanges | 0.12–0.16 mm layers; the ribs bridge across the windows (6 mm) |
| 03 tube | upright; the bayonet V-grooves are at 45°, 0.12–0.16 mm layers |
| 05, 06 guide arms | upside down (roof on the bed); 0.6 mm walls at the tip: enable thin walls / Arachne |
| 09 bridge | standing on its short side, with a brim |
| 20 clip jaw | on its side, 0.12 mm layers; it is the finest part |
| all the others | 0.2 mm layers, 3 perimeters, 15–20 % infill |

Fit clearance used everywhere: 0.15 mm (`FIT` in `src/common.py`). If your printer prints tight or loose, change that value and regenerate.

### Parts to Source

- **NEMA17** stepper motor (Ø5 × 24 mm shaft) + **TMC2209** driver
- **MG90S** micro servo (or SG90) with the single-arm horn
- **9 mm snap-off cutter blade** (0.4 mm), a piece at least 45 mm long
- M3 screws: 12 × M3×12 (bridge, cradle, servo mount), 9 × M3×10 (turret feet, upright feet, idler-pin retainer), 10 × M3×8 (motor, guide-arm pivot and stop, blade clamp), 1 × M3×6 grub screw + 1 M3 nut
- 1.75 mm filament: it serves as the leader-strip pin (drum and clip) and as the drum-to-tube dowel (2 pieces of 6 mm)
- **Leader strip**: a 16 × ~135 mm strip of scrap film or 0.15–0.2 mm PET (115 mm usable)

The holes marked "self-tapping" are Ø2.6: the M3 screw cuts its own thread in the PETG.

### Assembly

1. Tube + drum: slide the drum to the middle of the tube and fix it with the two filament dowels.
2. Leader strip: one end around a piece of filament pushed into the hole of the drum, the other end in the head of the clip.
3. Flanges: slide them onto the tube with the teeth in the channels, push to the wanted position (35 or 120), then twist 30° up to the stop. Flange A goes on the motor side.
4. Turret: screw the bridge, the cradle and the servo mount between the two cheek plates, then fit the guide arm with its two pivot screws (they must leave it free to swing) and the stop screw.
5. Cutter: glue the servo horn into its seat in the blade arm, then mount the blade with the edge towards the cutting side and the tip **75 mm from the servo axis** (19 mm beyond the head of the arm).
6. Uprights and base; drive coupling on the motor shaft, held by the grub screw.

### Use

**135** — Cassette in the cradle with the lips up, towards the bridge; leader trimmed square. Arm raised. Bring the clip to the cassette, passing under the arm and through the central passage of the bridge, clip it onto the film (1 cm sticking out is enough), lower the arm. Start: the motor winds, stops at the end of the film, the blade cuts, and the motor takes up the tail.

**120** — Flanges in the 120 position, arm 06, cradle 14. Roll in the cradle; unroll the backing paper until the film appears, then clip onto the film. While the motor winds, guide the paper up and back (as on the Rondinax 60). When the adhesive tape arrives: stop, advance 20 mm, cut.

### Planned Firmware Sequence (Starting Values)

Reel turns: 0.83 of leader strip, then **8.2 turns for a 36-exposure 135** (5.9 for 24 exposures) and **4.6 turns for a 120**. Length wound after θ radians: `L = 23·θ + 0.175·θ²` mm.

1. Servo parked (−26.8° from vertical).
2. Wind at 15–20 rpm, clockwise as seen from the idler-pin side.
3. End of film on 135: motor stall (StallGuard) at low current, or a maximum number of turns.
4. Cut: servo from −26.8° to +26.5° and back.
5. Take up the tail: another 0.6 turns.

Motor current, stall threshold and servo pulse widths have to be tuned on the bench: they have not been measured.

### Checks Done on the Model

See `verifiche.txt` for the full output.

- All 21 parts are valid, single solids; neither assembly has any pair of interfering bodies.
- Bayonet: free insertion along the channel, free rotation up to the stop, locked beyond the stop and against pull-out, in both positions.
- Guide arm: no interference with the reel at three winding radii, 0.2 mm clearance per side.
- Cutter: sweep free of interference in 7 positions; the tip passes the ceiling of the slot by 1.1 mm at the edges of the 120; when parked, the blade stays 0.9 mm from the 120 film zone and 12.8 mm from the 135 one.
- Reel capacity: 1.83 m of film.

### To Be Validated on the Bench

These are not guaranteed by CAD alone.

1. **Forming the arc and laying the film on the ribs**: this is the heart of the system. Parameters to retouch if needed: `RIB_H`, `TIP_CLEAR`, `WALL_TIP`, `H_EDGE`.
2. **Clip grip** under tension. For the first trials a piece of adhesive tape works too.
3. **Bayonet without a detent**: while winding, friction keeps it against the stop; for agitation with reversals a positive lock will be needed (a key in the channel).
4. **Cutting force**: estimated, not measured. If the MG90S is not enough, the mount has to be adapted to a larger servo.
5. **End of film**: stall detection to be tuned on 135; on 120 it is manual in this version, like pulling out the backing paper.
6. **Fit in the developing tank**: the tube is 71 mm long even in the 35 mm configuration.

### Modifying the Model

All dimensions are in `src/common.py`. After a change, run `cd src && python3 build_all.py` (needs `pip install cadquery`): it re-exports parts and assemblies and re-runs all the checks.

---

## Diagnostics & Bring-up Page

A hidden factory/bring-up screen for validating hardware (especially a custom board).

**How to open:**
- **Board:** on the splash, hold **2 fingers** still for **3 seconds**. Touch *after* the splash appears — a capacitive GT911 calibrates out fingers already on the panel at power-on.
- **Simulator:** press the small **DBG** button (top-left of the splash) — the mouse can't do multi-touch.

**Live monitor (grouped panels, refresh ~3×/s):** bath/chem temperatures, water-bath level (min/max), 3× chemical level (min/max), Hall magnet, flow (L/min + pulses), MCP23017 / SD / Wi-Fi status, and a **System** panel with ESP32-P4 **internal chip temperature**, free PSRAM, **last reset reason**, and uptime. A **Power rails** panel shows 12V/5V/3.3V (`n/a` until dividers + `HAS_RAIL_MONITOR` are provided).

**Output controls (to test the board):** toggle each valve (C1/C2/C3/WB/Waste), run pump FW/RV/Stop, motor FW/RV/Stop, toggle heaters H1/H2, play an audio test tone. **Close** turns every output off and returns to the splash.

---

## Build-time Switches

Compile-time flags (in `main/include/FilMachine.h` and the board header) that change behaviour without touching logic:

| Flag | Default | Effect |
|---|---|---|
| `ENABLE_BOOT_ERRORS` | 0 | 1 → show a blocking SD/I2C error screen at boot (tap to reboot). At 0 the errors are still detected + logged. |
| `VALVE_SELFTEST_ON_BOOT` | 1 | Cycle the valves once at boot (runs in the background so the display isn't delayed). |
| `HAS_DUAL_HEATER` | 1 | Two heater MOSFETs on MCP B6/B7 (vs a single Port-A relay). |
| `HAS_CHEM_LEVEL_SENSORS` | 1 | 6 chemical-level sensors on MCP Port B (B0–B5). |
| `HAS_RAIL_MONITOR` | 0 | 1 → read 12V/5V/3.3V rails via ADC in the diagnostics page (needs dividers + channel/ratio defines). |
| `MOTOR_MIN_ANALOG_VAL` / `PUMP_MIN_ANALOG_VAL` | 90 / 150 | Duty at the 10% slider position — raise if the motor/pump stalls at low speed. |

---

## Configuration & Persistence

All data is stored on the SD card as a single **JSON** file, `FilMachine.json` (the old binary `.cfg` was replaced — JSON is human-readable, hand-editable and version-tolerant). Parsing/serialisation uses a small dependency-free parser (`main/mini_json.c`) that builds on both the board and the simulator (no cJSON). Writes are crash-safe (`.tmp` + atomic rename).

**Schema:**

```json
{
  "settingsParams": {
    "tempUnit": 0, "waterInlet": 1,
    "filmRotationSpeedSetpoint": 50, "rotationIntervalSetpoint": 10, "randomSetpoint": 20,
    "isPersistentAlarm": 1, "isProcessAutostart": 0, "drainFillOverlapSetpoint": 100,
    "multiRinseTime": 60, "lineRinseEnabled": 0, "lineRinseTime": 10,
    "tankSize": 2, "pumpSpeed": 30,
    "chemCalibFillSecs": 0, "wbCalibFillSecs": 0, "chemistryVolume": 2,
    "tempCalibOffset": 0, "chemCalibOffset": 0,
    "splashRandom": 0, "splashPalette": 3, "splashShapeStyle": 0,
    "splashComplexity": 40, "splashSeed": 0, "splashDefault": 1,
    "wifiEnabled": 0, "wifiSSID": "", "wifiPassword": "",
    "brightness": 100, "volume": 60, "invertPump": 0,
    "language": 0, "screenOffMins": 10
  },
  "processes": [
    { "name": "C41 Color Std", "temp": 38, "tempTolerance": 0.3,
      "isTempControlled": 1, "isPreferred": 1, "filmType": 1,
      "timeMins": 23, "timeSecs": 15,
      "steps": [
        { "stepNameString": "Developer", "timeMins": 3, "timeSecs": 15,
          "type": 0, "source": 0, "discardAfterProc": 0 }
      ] }
  ],
  "machineStats": { "completed": 0, "totalMins": 0, "totalSecs": 0, "stopped": 0, "clean": 0 }
}
```

Notes on a few fields: `tempCalibOffset`/`chemCalibOffset` are in **tenths of a degree** (int16, clamped ±30 °C); `chemCalibFillSecs`/`wbCalibFillSecs` are the **measured** MIN→MAX fill times in seconds (0 = uncalibrated, capacity used as fallback); step `type` 0=Chemistry/1=Rinse/2=MultiRinse; step `source` 0=C1,1=C2,2=C3,3=WB. `lineRinseEnabled` (0/1) turns on a **line rinse after each chemistry step**: after draining a chemistry step, the shared pump line is flushed with clean water from the water bath, discarded to waste, for `lineRinseTime` seconds (5–60 s) before the next liquid is drawn — clearing chemistry residue from the common tubing to avoid cross-contamination. Opt-in (default off); uses extra water, so watch the bath level when the water inlet isn't connected.

**Auto-save triggers:** creating/editing/deleting a process, changing any setting, toggling preferred, duplicating processes or steps, and recording a fill calibration.

**Export** writes a backup copy (`FilMachine_Backup.json`); **Import** restores from it and reboots. Generate a fresh SD file with `scripts/genFilMachineCFG.py --realistic --output sd/` (see COMMANDS.md).

In the simulator these files live in an `sd/` subdirectory of the directory the simulator is launched from (e.g. `sd/FilMachine.json`); the folder is created on first run if missing.

---

## Language / Localization

The UI is fully bilingual: **English** (default) and **Italiano**. The language is selected in Settings → Language via a roller; on confirmation the machine saves the config and **reboots automatically** to rebuild the UI in the new language (the on-device UI is built once at boot).

Implementation: all ~350 UI strings live in a runtime lookup table (`main/lang.c` + `main/include/lang.h`) resolved through `tr()`. The `xxx_text` macros in `FilMachine.h` are untouched at call sites — they now expand to `tr(STR_xxx)`. The table is generated/maintained by `scripts/gen_lang.py`, which holds the Italian dictionary; translations use ASCII apostrophes (`Velocita'`) because the LVGL fonts are converted with `--range 0x20-0x7F`. The setting is persisted as `"language"` (0=EN, 1=IT) in `FilMachine.json`, exposed over WebSocket (`set_setting`, applied at next boot), and included in `genFilMachineCFG.py`.

To add or fix translations, edit the `IT` dict in `scripts/gen_lang.py` and mirror the change in `main/lang.c` (or regenerate). Adding a third language means extending `lang_pair_t` and the `languageList` roller options.

---

## SD Boot & Crash Log

Every boot the firmware creates **`/log/boot_NNNN.txt`** on the SD card (the 20 most recent files are kept, older ones are pruned automatically). The file starts with a header — firmware version, build date, **reset reason** — and then captures in background all `ESP_LOGx` and `LV_LOG` lines (RAM-buffered, flushed to the card every 2 s so the UI is never blocked).

If the previous run **crashed** (panic or watchdog), the header also contains a `PREVIOUS RUN CRASHED` block with the offending task and program counter, read back from the **core dump** that the ESP32 saves to the dedicated 64KB `coredump` flash partition at panic time. The full dump stays in flash and can be decoded with `idf.py coredump-info`. This is the "black box": if the machine reboots on its own while no serial console is attached, pull the SD card and read the latest `boot_NNNN.txt`.

Not captured by design: bootloader output, the very first lines before the SD is mounted, raw `printf` calls, and the last ≲2 s before a hard crash (covered by the core dump summary instead). Module: `main/sd_log.c` (firmware only; the simulator links weak no-op stubs).

---

## Typical Workflows

### C41 Color Negative (38°C)

A standard C41 process: Pre-wash with water (1:00), Developer from C1 (3:15), Bleach from C2 (6:30), Wash (3:00), Fixer from C3 (6:30), Final Wash (3:00). Temperature control is critical — the machine maintains 38°C ± 0.3°C throughout.

### Black & White (20°C)

B&W processes are more flexible: Developer from C1 (8:00), Stop Bath from C2 (1:00), Fixer from C3 (5:00), Wash (5:00). Temperature control can be disabled for ambient-temperature development, or set to 20°C ± 0.5°C for consistency.

### E6 Slide Film (38°C)

E6 requires precise timing and temperature: First Developer (6:00), Wash (2:00), Color Developer (6:00), Wash (2:00), Bleach (6:00), Fixer (4:00), Final Wash (4:00). All at 38°C with tight ±0.3°C tolerance.

---

## Developer Quick Reference

### Build Commands

```bash
# ── Simulator (macOS/Linux) ──────────────────────────────
mkdir -p build800 && cd build800
cmake ..                                   # Configure (first time only)
make -j$(sysctl -n hw.ncpu) filmachine_sim # Build simulator (parallel)
./filmachine_sim                           # Run simulator (800×480 window)

# ── Tests ────────────────────────────────────────────────
make -j$(sysctl -n hw.ncpu) filmachine_test  # Build tests (parallel)
./filmachine_test                            # Run all 19 test suites

# ── Firmware (ESP32-P4) ──────────────────────────────────
cd ~/Documents/GitHub/FilMachine_Reworked       # Must be in project root!
. $HOME/esp/esp-idf-v5.5/export.sh        # Load ESP-IDF environment
idf.py set-target esp32p4                  # First time: set RISC-V target
idf.py build                               # Build firmware
idf.py flash monitor                       # Flash + open serial monitor
idf.py flash                               # Flash only (no monitor)
idf.py monitor                             # Serial monitor only (Ctrl+] to exit)
idf.py size                                # Show firmware size breakdown
```

### Rebuilding After Code Changes

```bash
# Simulator: just run make again (incremental, from build800/)
cd build800 && make -j$(sysctl -n hw.ncpu) filmachine_sim

# If you added new .c files to CMakeLists.txt, re-run cmake first:
cd build800 && cmake .. && make -j$(sysctl -n hw.ncpu) filmachine_sim

# Build + run tests in one shot:
cd build800 && cmake .. && make -j$(sysctl -n hw.ncpu) filmachine_test && ./filmachine_test

# Firmware: idf.py handles incremental builds automatically
idf.py build

# Flash immediately after build:
idf.py build && idf.py flash monitor
```

### Clean Rebuild

```bash
# Simulator: wipe build directory and reconfigure
rm -rf build800 && mkdir build800 && cd build800 && cmake ..
make -j$(sysctl -n hw.ncpu) filmachine_sim

# Firmware: full clean (also needed if sdkconfig changes)
idf.py fullclean
idf.py build
```

### Generating a Firmware Update File

```bash
idf.py build
# The .bin file is at: build/FilMachine.bin
# For SD card update, rename and copy:
cp build/FilMachine.bin /Volumes/SDCARD/FilMachine_fw.bin
```

### Generating Sample Data

```bash
python3 scripts/genFilMachineCFG.py --realistic --output build800/sd/
```

### Common Troubleshooting

```bash
# "CMakeLists.txt not found" when running idf.py
# → You're in the wrong directory. Run from the project root, not build800/

# Simulator won't compile after adding a new .c file
# → Re-run cmake: cd build800 && cmake ..

# LVGL not found
# → CMake clones it on the first configure. To do it by hand, from the project root:
#   git clone --depth 1 --branch v9.5.0 https://github.com/lvgl/lvgl.git

# Serial monitor garbled output
# → Check baud rate: idf.py monitor -b 115200

# ESP-IDF not found / idf.py command not found
# → Source the environment: . $HOME/esp/esp-idf-v5.5/export.sh

# CMake: 'The "path" field in the manifest file ".../components/espressif__esp_lcd_touch/idf_component.yml"
#         does not point to a directory'
# → dependencies.lock stores the absolute path of that local component on the machine that
#   generated it. After moving or renaming the project folder (or on another computer), edit the
#   "path:" under espressif/esp_lcd_touch in dependencies.lock to the new location. Deleting the
#   lock file makes the component manager regenerate it, but with newer versions of the unpinned
#   dependencies (mdns, esp_lcd_touch_gt911 and two transitive ones), which are untested here.

# CMake generator mismatch (Unix Makefiles vs Ninja)
# → idf.py uses Ninja, simulator uses Make. If switching, do a clean rebuild:
#   rm -rf build800 && mkdir build800 && cd build800 && cmake ..

# Display doesn't turn on after flashing
# → Check that IDF_TARGET is esp32p4: idf.py set-target esp32p4
# → If you deleted the build/ folder, re-run: idf.py set-target esp32p4 && idf.py build
```

---

## License

Private project. All rights reserved.

## Authors

**PeterB** — Hardware design & firmware
**FrankP** — Software development & testing

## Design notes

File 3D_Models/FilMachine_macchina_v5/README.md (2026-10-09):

# FilMachine – macchina completa (rilascio 5)

Progetto meccanico di tutta la macchina: tank a tenuta di luce con caricatore integrato per **135 e 120**, bagno
termostatico con tre vaschette estraibili, idraulica, cavalletto con pompa, vano elettronica con display.
Usa i componenti già acquistati e i collegamenti già previsti dal firmware `FilMachine_Reworked`.

**È un progetto, non una macchina provata.** Tutto quello che segue è verificato sul modello 3D (interferenze, movimenti,
volumi); niente è stato stampato né misurato. I punti da provare a banco sono elencati in fondo.

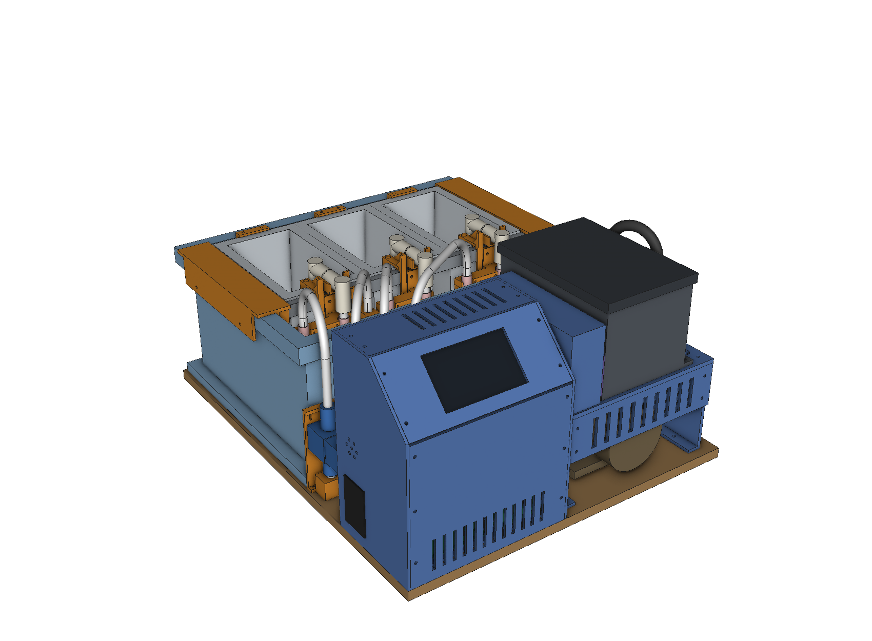
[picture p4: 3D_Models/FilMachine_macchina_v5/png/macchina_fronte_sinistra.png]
vista


## Cosa c'è nel pacchetto

| Cartella / file | Contenuto |
|---|---|
| `docs/FilMachine_3D.pdf` | **Assieme 3D navigabile** (Adobe Acrobat Reader): 164 corpi con nome, da accendere e spegnere uno a uno o a gruppi, 10 viste pronte. `docs/FilMachine.u3d` è lo stesso modello da solo |
| `step/ASSIEME_FilMachine.step` | Lo stesso assieme per il CAD (un solo assieme: 135 e 120 usano gli stessi pezzi) |
| `step/`, `stl/` | 62 pezzi diversi, **già nell'orientamento di stampa** (94 da stampare contando le quantità; A06 è una variante facoltativa) |
| `docs/NuovaDistinta.xlsx` | Nuova distinta: da acquistare, già acquistati e loro uso, pezzi stampati, viteria |
| `docs/schema_idraulico.pdf`, `docs/schema_elettrico.pdf` | Schemi |
| `docs/dima_base.pdf` (+ `_fori.csv`) | Dima 1:1 della base con i 32 fori |
| `docs/note_firmware.md` | Cosa funziona col firmware di oggi, cosa no, modifica minima |
| `verifiche.txt` | Tutti i controlli eseguiti sul modello: stampabilità, movimenti, volumi, viti, tagli dei tubi |
| `png/` | Viste e sezioni |
| `src/` | Sorgenti parametrici (CadQuery): le misure stanno in `common.py` e `machine.py` |

## La macchina in breve

Ingombro circa **42 × 51 × 26 cm**: 420 × 505 mm in pianta, 246 mm sopra la tavola di multistrato da 12 mm che fa da base
(il punto più alto è la curva del tubo in silicone della tank; il vano elettronica arriva a 226 mm).

- **Davanti a sinistra**: vano elettronica con il display su plancia a 45°.
- **Davanti a destra**: tank con caricatore, su un cavalletto; sotto c'è la pompa.
- **Tra elettronica e bagno**: le cinque elettrovalvole in fila sul collettore (da sinistra: C1, WB, C2, C3, scarico).
- **Dietro**: il bagno (contenitore Euro 400 × 300 × 170) con le tre vaschette GN 1/9 da 1 litro e, davanti a loro,
  una fascia libera per innesti, riscaldatori, sonde e per versare l'acqua.

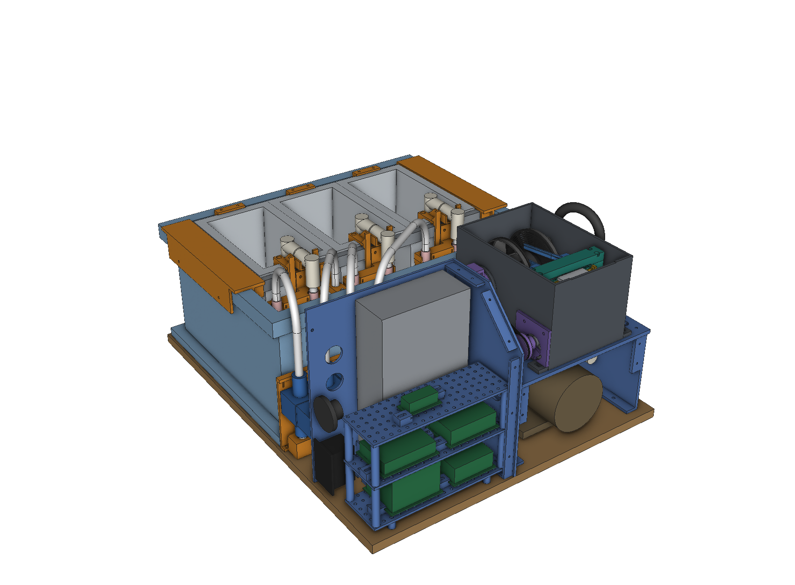
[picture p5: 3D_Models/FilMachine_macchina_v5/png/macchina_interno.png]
interno


## Cosa cambia rispetto al caricatore v4

- **Culla unica per 135 e 120** (B12). Il rullo 120 appoggia nella sede larga sulle flange del rocchetto; il caricatore
  135 scende nella sede centrale, 4 mm più profonda. Tra i due formati non si cambia nessun pezzo.
- **Guida a due slitte tipo Lab-Box** (B13–B15). Le stesse due slitte servono per 135 e 120: scorrono su una barra
  quadra e scattano in due posizioni. Tengono la pellicola per i bordi, con la gobba verso l'alto: il centro non tocca nulla.
- **Taglierina dal basso** (B07–B11) al posto del «tergicristallo»: due spezzoni di lama da cutter a Λ su un portalama
  che sale di 12,8 mm, mosso da un micro-servo con biella e manovella. Taglia tutta la larghezza, anche il 120.
- **Flange che si chiudono in versi opposti**: una in senso orario, l'altra antiorario, con un solo gesto.
- **Baionetta a tre denti** invece di due, con un dente più largo che fa da chiave (la flangia entra in una sola
  posizione) e una linguetta che scatta a fine corsa.
- **Tutto il resto della macchina**: bagno, vaschette, idraulica, struttura, elettronica, schemi, distinta.

## Come funziona

### Spirale (serie A)

Carico dal centro verso l'esterno: una fascetta con clip tira la pellicola sul tamburo. Le due flange si infilano
sul tubo a baionetta e si bloccano con 30° di rotazione; due anelli con alette muovono il liquido. Prima di tutto
stampare il **provino A09**: ha tre giochi (0,10 / 0,06 / 0,02 mm) per scegliere quello giusto per la propria stampante.

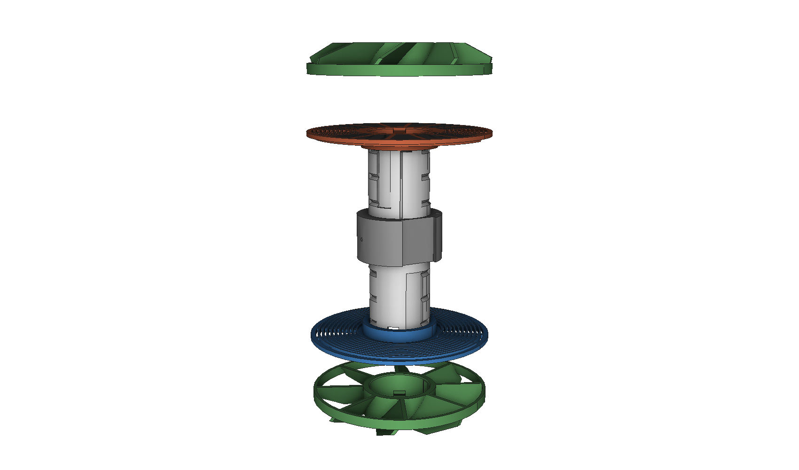
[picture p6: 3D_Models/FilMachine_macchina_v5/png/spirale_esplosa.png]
spirale


### Tank con caricatore (serie B)

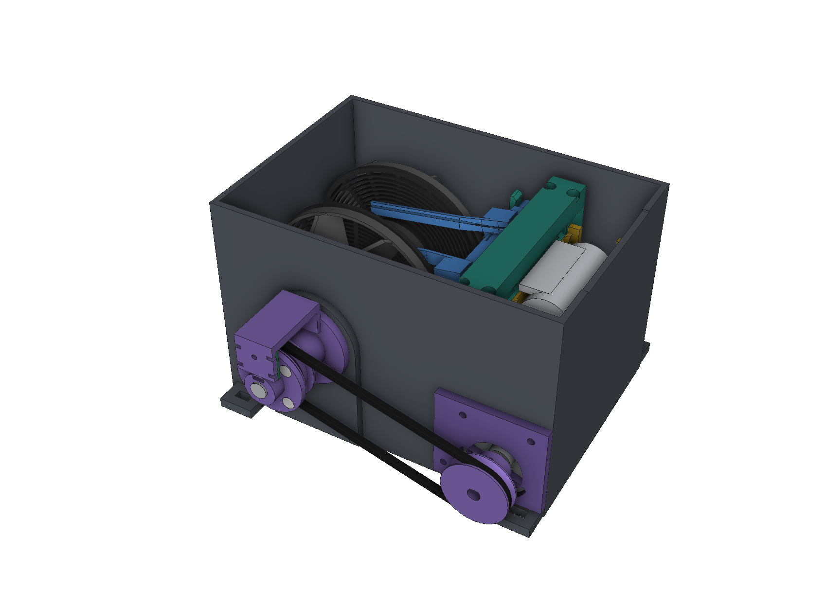
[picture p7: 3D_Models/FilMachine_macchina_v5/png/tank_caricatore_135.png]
tank


Corpo in un pezzo solo, stampato in piedi senza supporti. Dentro: la vasca della spirale e, separato da un divisorio,
il ripiano asciutto con culla, ponte, taglierina e guida. Sotto il ripiano la galleria del motoriduttore e il vano del servo.

- **Trasmissione**: motoriduttore 20 giri/min → cinghia tonda (un O-ring 80 × 3) → albero inox Ø8 su due cuscinetti con
  paraolio. La cinghia fa anche da limitatore di coppia: quando la pellicola finisce slitta. Si tende ruotando il motore
  nella sua piastra (l'albero è eccentrico).
- **Sensore Hall**: quattro magneti sulla puleggia della spirale.
- **Spirale**: da un lato il trascinatore a tre denti, dall'altro un perno folle a molla. Per toglierla si spinge di
  5,5 mm contro la molla e si solleva; prima va sganciata la barra della guida dalle sue due selle.
- **Liquido**: entra ed esce da un pescante che sale fino a sopra il livello, quindi non c'è nessun foro sotto il
  liquido. Con 250 ml il livello è a 34 mm dal fondo, con 350 ml a 46 mm; l'asse è a 50 mm. Oltre circa 500 ml il liquido
  esce dal troppopieno.
- **Il troppopieno è piccolo**: con il livello al bordo del divisorio smaltisce circa 0,4 l/min, un quinto della portata
  di riempimento del firmware (250 ml in 8 s). Assorbe un piccolo eccesso, non un riempimento sbagliato: con 550 ml o
  più il liquido passa nel vano del caricatore. Per questo si usano solo 250 e 350 ml.
- **Luce**: coperchio a labirinto; sul lato del caricatore una feritoia lascia uscire la carta del 120.

### Bagno e vaschette (serie C)

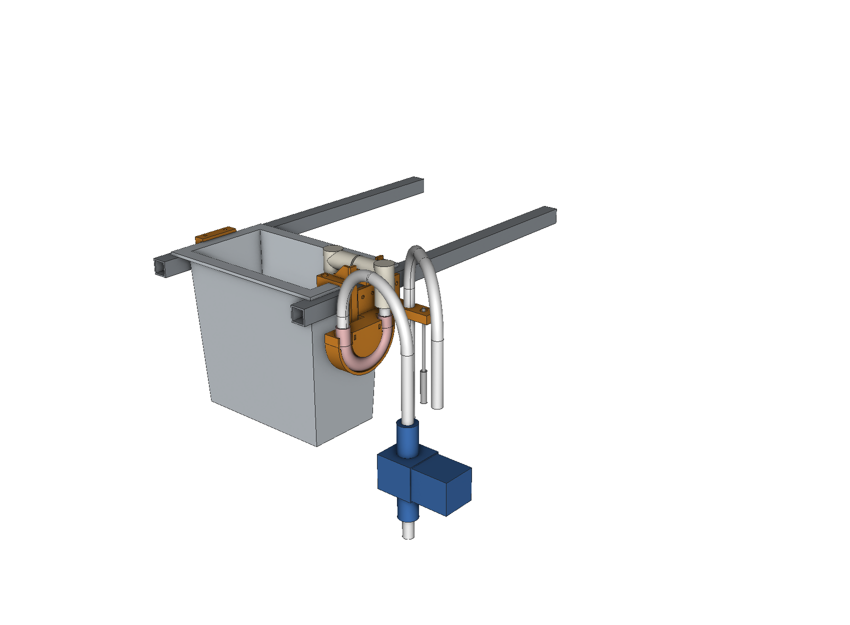
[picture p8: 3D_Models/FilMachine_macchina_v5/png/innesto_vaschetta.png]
innesto


Le vaschette sono normali bacinelle Gastronorm GN 1/9 alte 150 mm, senza fori: si lavano come una pentola. Stanno
appese a due longheroni di alluminio 15 × 15 dentro il bagno.

Ogni vaschetta porta sul bordo anteriore una **testina**: due gomiti a innesto e tre spezzoni di tubo, tenuti da una
sella stampata. Il pescante scende nella vaschetta; il codolo esterno entra nella bocca di un **sifone**, cioè uno
spezzone di tubo in silicone piegato a U nella sua culla. Nessun pezzo stampato tocca la chimica.

- **Mettere una vaschetta**: infilare il bordo posteriore sotto il labbro fisso, abbassare il davanti e premere finché i
  due ganci scattano.
- **Toglierla**: tirare verso di sé le due linguette, alzare il davanti di un paio di centimetri, tirare avanti di 4 mm e
  sollevare. La testina resta sulla vaschetta e si sfila al lavandino.
- **Sonda della chimica**: è infilata in uno dei due fori della sella di C1 e pesca nella vaschetta (una fascetta
  stretta sul cavo fa da fermo); va sfilata prima di togliere C1. La sonda del bagno sta nel portasonde C06, insieme al pescante dell'acqua.
- **Perché i ganci**: una vaschetta vuota immersa galleggia con circa 8 N. Labbro e ganci la tengono giù.

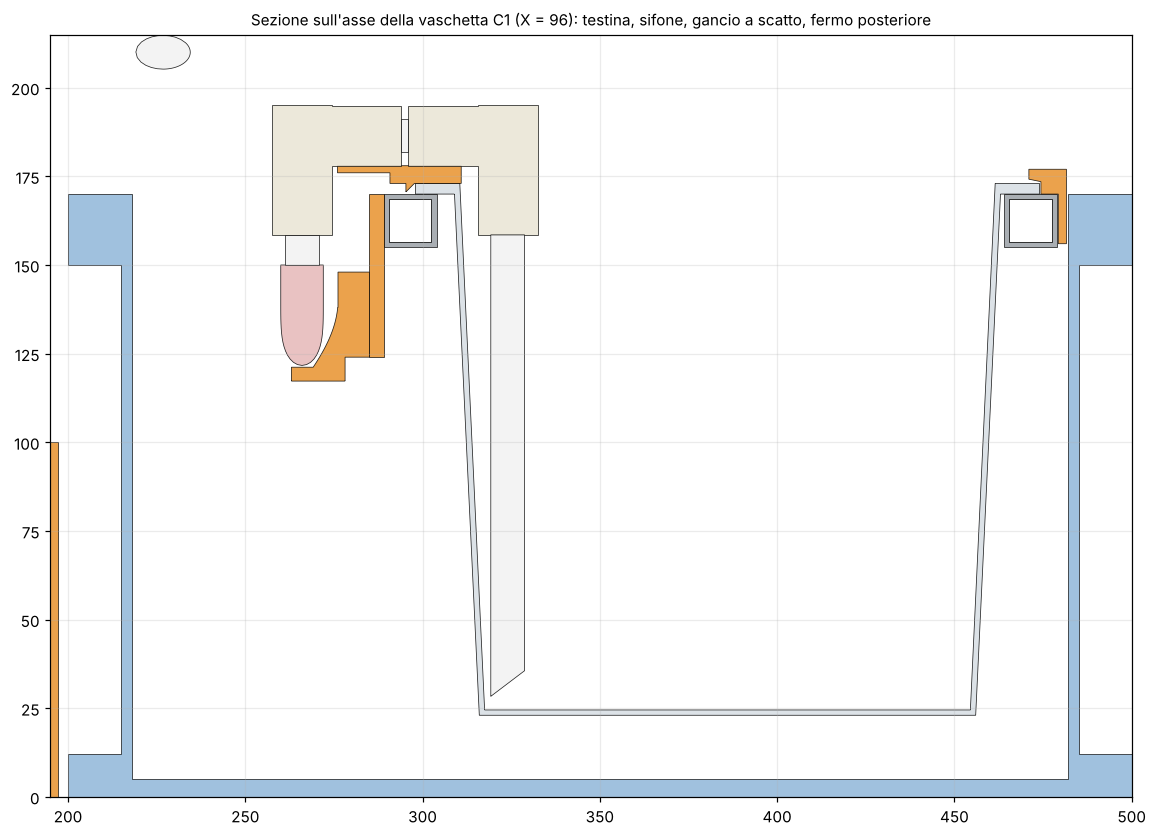
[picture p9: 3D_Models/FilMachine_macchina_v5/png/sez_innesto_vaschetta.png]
sezione


Il bagno contiene circa 7,4 litri al livello di lavoro. Fornisce anche l'acqua dei risciacqui: ogni litro prelevato
abbassa il livello di 17 mm e tra il livello di lavoro e il sensore di minimo ci sono 3,2 litri, cioè 9 riempimenti da
350 ml. Il pescante dell'acqua pesca più in alto dei riscaldatori, quindi la pompa non può scoprirli.

### Idraulica

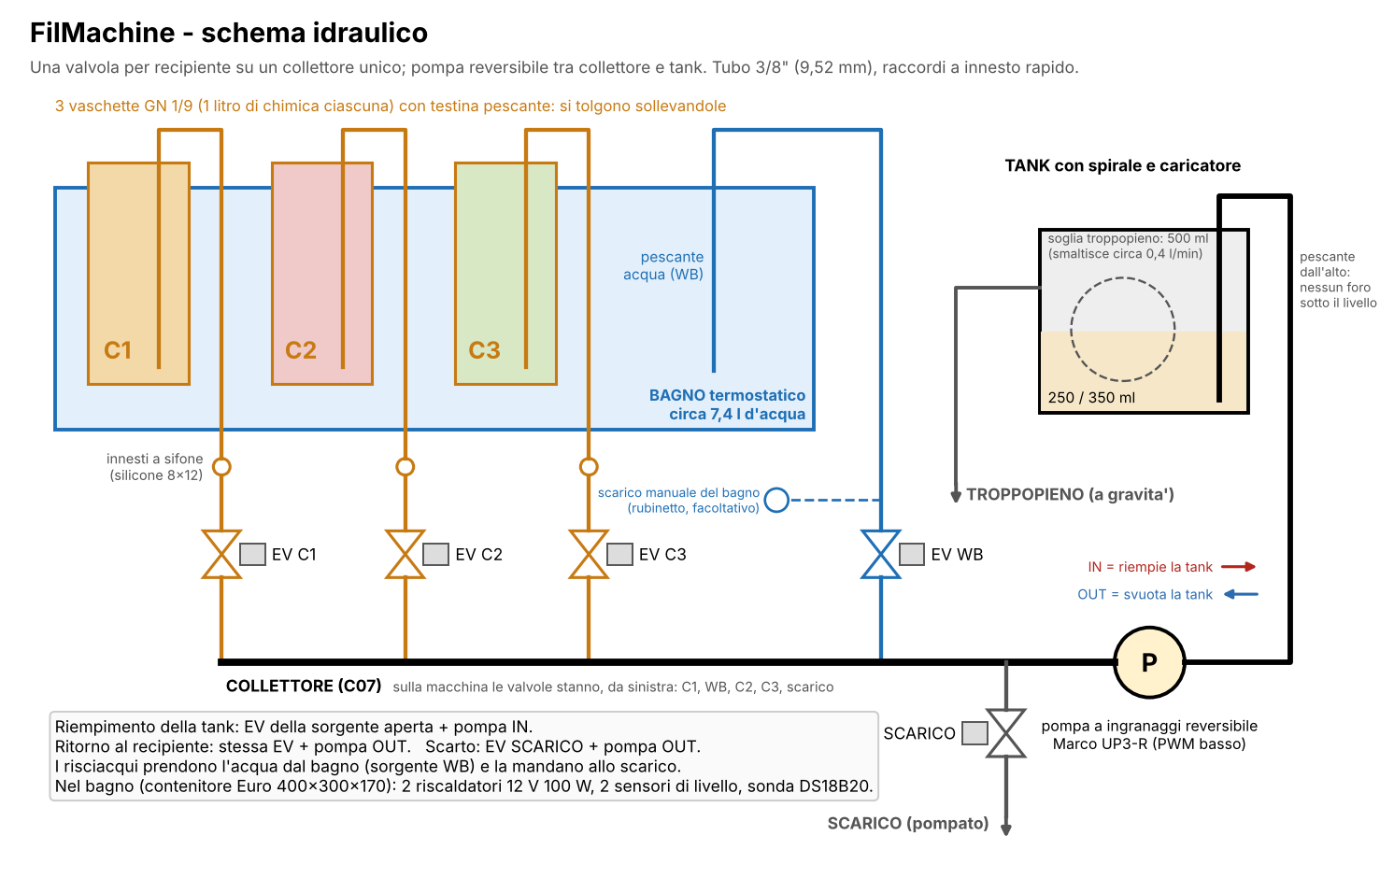
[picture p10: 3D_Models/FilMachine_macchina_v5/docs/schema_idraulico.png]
schema


Una valvola per recipiente, tutte su un collettore; la pompa reversibile sta tra il collettore e la tank. È lo schema
che il firmware usa già per il processo. Due uscite separate sul fianco destro: **SCARICO** (pompato) e **TROPPOPIENO**
(a gravità: la tanica deve stare più in basso della macchina).

Il collettore (C07) è stampato: sei sedi verticali con O-ring 9 × 2 in cui entrano spezzoni di tubo da 3/8". Tutto il
resto è tubo da osmosi con raccordi a innesto, più il silicone 8 × 12.

Come sono posati i tubi (tagli e raccordi in `verifiche.txt`):

- **Dalle valvole al bagno** (C1, C2, C3 e WB): un pezzo solo ciascuno, senza raccordi. Sale dalla valvola, fa un
  ponte sopra il bordo del contenitore con curve di raggio 45 mm e scende nel sifone (o nel bagno, per WB). Il tubo da
  3/8" non va piegato più stretto di 40 mm: si schiaccia. Le valvole sono in quest'ordine proprio perché i quattro
  ponti non si incrocino.
- **Scarico**: un gomito sopra la valvola, girato un po' verso il retro; il tubo corre nella rientranza del
  contenitore fino al passaparete SCARICO sul fianco destro.
- **Collettore → pompa → tank**: tra collettore e pompa non c'è l'altezza per una curva, quindi lì c'è un gomito a
  codolo che entra direttamente nella sede del collettore. Un altro gomito a codolo esce dalla pompa, poi un gomito
  normale e la salita verso la tank, che finisce con una curva larga di silicone nero sul portagomma.
- **Troppopieno**: sotto il piano del cavalletto c'è un innesto orizzontale in cui il silicone entra a pressione; da lì
  il tubo va diritto alla staffa degli scarichi, sempre in discesa, senza curve che possano strozzarlo.

### Elettronica (serie D)

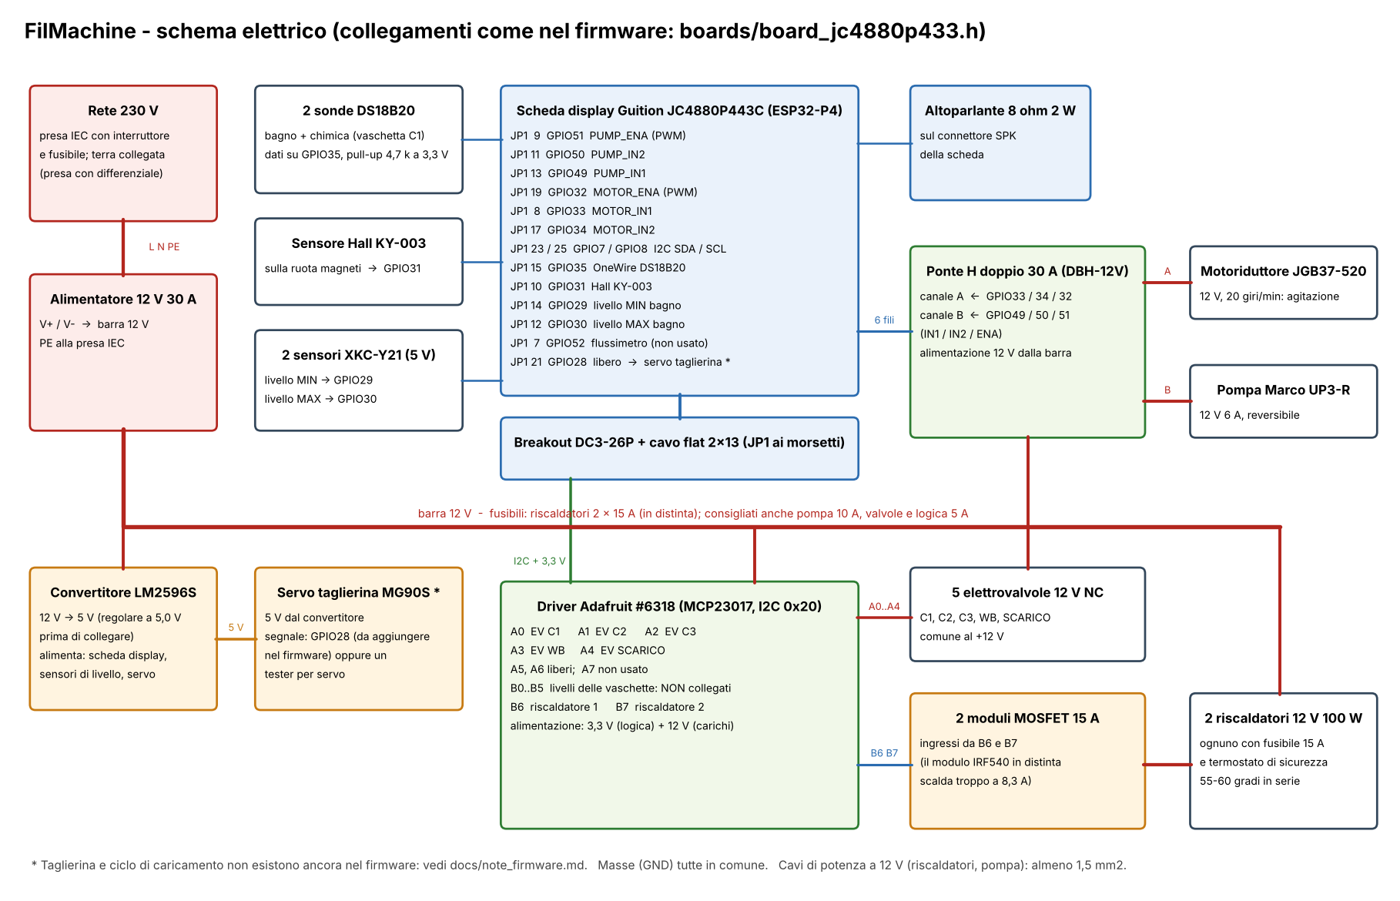
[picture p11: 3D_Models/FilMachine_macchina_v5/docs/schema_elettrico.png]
schema


Alimentatore in piedi contro la paratia, tre ripiani a griglia con le schede tenute da morsetti universali, display
sulla plancia: la scheda entra nella cornice sul retro ed è trattenuta da quattro linguette girevoli (D17), da orientare
dove non ci sono connettori. La paratia separa l'elettronica dalle valvole. I collegamenti sono quelli del firmware:
vedi lo schema.

## Uso

**Caricare un 135**
1. Aprire il coperchio. Slitte nella posizione stretta, appoggiate sul tamburo.
2. Caricatore nella culla; tirare fuori 10 cm di coda, passarla nella fessura del ponte e tra le slitte, agganciarla alla clip.
3. Chiudere il coperchio e avviare il caricamento. A fine rullino la spirale si ferma, la cinghia slitta, la lama taglia.

Il ciclo di caricamento è una funzione da aggiungere al firmware (`docs/note_firmware.md`, punto 5); per le prime prove
bastano la pagina di diagnostica per il motore e un tester per servo per la lama.

**Caricare un 120**
1. Slitte nella posizione larga. Rullo nella culla.
2. Svolgere la carta finché compare la pellicola; agganciare la pellicola alla clip e far uscire la carta dalla feritoia
   tra coperchio e corpo, sul lato del caricatore.
3. Chiudere e avviare, accompagnando la carta con la mano mentre esce. Alla fine la lama taglia la pellicola prima del nastro.

**Sviluppo**: come oggi nel firmware. Usare *Volume chimica = Basso* e tank *Piccola* (250 ml) o *Media* (350 ml).

**Bagno**: versare l'acqua nella fascia libera fino al sensore MAX, meglio già calda. Da 20 a 38 °C i due riscaldatori
impiegano circa un'ora; da 33 °C meno di 20 minuti.

**Fine lavoro**: togliere le vaschette e lavarle; far girare un processo di sola acqua per sciacquare tubi, pompa e tank.

## Stampa

- **Materiale**: PETG. Spirale, tank e coperchio in **nero** (tenuta alla luce); il resto come si vuole.
- Ugello 0,4, strato 0,2, 3–4 perimetri, riempimento 25 %. Il collettore C07 a 4 perimetri e 100 %.
- Tutti i pezzi sono già orientati. **Solo B17** (cartuccia dei cuscinetti) vuole i supporti, sotto la flangia; negli
  altri ci sono solo ponti corti, fino a 20 mm (elenco in `verifiche.txt`).
- Elenco, quantità, ingombri e note pezzo per pezzo: foglio *Pezzi stampati* della distinta. In tutto circa 1,6 kg di filamento.
- **Piatto**: tre pannelli del vano elettronica (D06, D07, D11) sono lunghi 226 mm. Su un piatto da 220 mm non entrano:
  ridurre `EL_Z1` in `machine.py` non basta (l'alimentatore è alto 215 mm), bisogna tagliarli in due nello slicer.
  Il corpo della tank è 183 × 144 × 109 mm.

## Montaggio, in ordine

1. **Base**: tagliare il multistrato 420 × 505, incollare sopra la dima stampata 1:1 (controllare il segmento da
   100 mm) e segnare i fori: preforo Ø2,5 non passante, viti da legno 3,5 × 12. I quattro fori del piede della pompa si
   segnano dalla pompa stessa.
2. **Bagno**: forare il contenitore per i due riscaldatori (Ø16,5, a 20 mm dal fondo interno, a 38 e 64 mm dalla parete
   lunga anteriore, sulla parete corta destra). Montare i riscaldatori con guarnizione dentro e fuori e il dado
   all'interno. Incollare i due sensori di livello all'esterno della parete anteriore.
3. **Telaio delle vaschette**: tagliare due longheroni da 356 mm, infilarli nelle tasche delle due testate C05,
   appoggiare il telaio sul contenitore e stringere le quattro viti M4 sotto la fascia. Avvitare sui longheroni le
   staffe C03 (con la culla C02 già montata), i fermi C04 e il portasonde C06: le posizioni sono in `verifiche.txt`.
   Viti per lamiera 2,9 con preforo da 2,4: lunghe 9,5 per C03 e C06, lunghe 13 per C04.
4. **Valvole**: collettore sulla base, O-ring ingrassati, cinque spezzoni da 33 mm, valvole, pettine C08 e una fascetta
   per valvola. Ordine da sinistra: **C1, WB, C2, C3, scarico** (le uscite del driver restano quelle dello schema:
   conta quale valvola si collega a quale uscita, non la posizione).
5. **Pompa e cavalletto**: pompa con i due raccordi filettati; fianchi, piano e frontale del cavalletto.
6. **Tank**: montare trasmissione, perno folle, servo, ponte, culla e guida; poi la tank sul cavalletto con quattro
   viti. Il coperchietto del vano servo entra nella finestra del piano: chiudere con mastice nero la tacca del cavo.
   Cavi: quello del motore esce dal lato destro della galleria e scende nel foro del piano lì accanto; quello del
   sensore Hall scende nel foro sotto il carter; quello del servo passa dalla finestra del vano servo. Tutti e tre
   arrivano all'elettronica dal passacavo Ø22 nel fianco sinistro del cavalletto.
   La fascetta della clip è una striscia di pellicola o di poliestere da 16 × 115 mm, fermata nel tamburo con uno
   spezzone di filamento da 1,75.
7. **Tubi**: tagliarli secondo la tabella in `verifiche.txt`; i quattro tubi a ponte un po' abbondanti, da rifilare
   sul posto. I due tubi in silicone che arrivano alla tank devono essere **neri**. Appuntire i tre codoli delle
   testine (Ø7,5 in punta, cono lungo 8 mm). Accorciare a 27 mm il codolo del gomito che entra nella pompa.
8. **Elettronica**: zoccolo e alimentatore, colonna dei ripiani, fianchi, paratia, frontale, plancia con il display
   (quattro linguette D17), tetto. Cablare secondo lo schema. Le viti, una per una, sono nel foglio *Viteria* della distinta.

## Misure da controllare sui componenti veri

Alcuni componenti non li ho potuti misurare. Le quote usate sono in `src/machine.py`; se le tue sono diverse basta
cambiarle e rigenerare.

| Componente | Quota assunta | Dove pesa |
|---|---|---|
| Vaschetta GN 1/9 | bordo piano largo 11 mm e spesso 3 mm, parete 1,5 mm, sformo 7 mm | sella C01, labbro C04, altezza dei ganci C03 |
| Contenitore Euro | interno 364 × 264 × 165 mm, fascia di rinforzo alta 20 mm | testate C05, lunghezza dei longheroni |
| Elettrovalvola | 82 mm tra gli attacchi, corpo 33 mm, bobina di lato | passo del collettore (35 mm), pettine C08 |
| Pompa UP3-R | attacchi sui due fianchi della testa, a 41 mm dal piano | altezza del tubo verso il collettore |
| Riscaldatore | filetto M16, esagono 22 | fori nel contenitore, carter C10 |
| Scheda display | 114,4 × 66,8 × 3,2 mm; finestra 96 × 58 centrata sulla scheda (area attiva circa 93,6 × 56,2) | plancia D09, linguette D17 |
| Schede | ingombri indicativi | solo la disposizione sui ripiani |

## Verifiche fatte sul modello

Dettagli e numeri in `verifiche.txt`.

- **Assieme**: 164 corpi, tutti solidi validi, **nessuna interferenza** tra nessuna coppia. Tutti gli STL sono chiusi.
- **Viti** (non sono modellate, quindi hanno un controllo a parte): ogni foro passante ha di fronte, sullo stesso asse,
  il suo foro filettato; attorno ai fori filettati la parete è piena; la lunghezza di ogni vite è confrontata con la
  profondità del foro e con quello che c'è dietro.
- **Spirale**: inserimento, rotazione, battuta e blocco assiale sui due lati e nelle stazioni 135 e 120; una flangia
  ruotata di 120° non entra; il verso sbagliato non si chiude; le due spirali sono in fase.
- **Taglierina**: corsa completa senza urti; a fine corsa il filo supera il cielo della fessura di 3,5 mm sui bordi
  del 135 e di 0,7 mm su quelli del 120.
- **Guida**: nessun urto da spirale vuota a piena, nei due formati; a spirale piena restano 2 mm sotto il coperchio.
- **Culla**: 135 e 120 non interferiscono, sono fermati di lato e verso il ponte, escono liberi verso l'alto.
- **Vaschette**: inserimento a bascula senza urti fino a 6° e percorso di estrazione libero, per tutte e tre.
- **Volumi**: tank, vaschette e bagno come indicato sopra.

## Cosa non è verificato e va provato

1. **Niente è stato costruito.** Forze, attriti e tenute sono stimati.
2. **Tenuta alla luce della tank**: labirinto del coperchio, feritoia della carta, tubi. Da provare con uno spezzone
   di pellicola prima di un rullino vero.
3. **Formazione dell'arco della pellicola** nelle slitte e ingresso tra le costole: è il punto più delicato del caricatore.
4. **Coppia di slittamento della cinghia** e **forza di taglio** (il servo dà circa 28 N sul portalama).
5. **Innesto a sifone**: la tenuta del codolo conico nel silicone e l'eventuale goccia quando si toglie la vaschetta.
   **Collettore stampato**: tenuta degli O-ring e porosità della stampa; l'alternativa è una fila di quattro raccordi a T, lunga 270 mm.
6. **Ganci a scatto**: forza di sgancio calcolata in circa 5 N per braccio, deformazione 1,2 %.
7. **Elettrovalvole**: sono a membrana e qui il liquido le attraversa nei due versi; la tenuta in senso contrario va provata.
   **Curve dei tubi**: il raggio di 45 mm per il tubo da 3/8" e di 30 mm per il silicone libero sono valori prudenti ma
   non provati su questi tubi; se un tubo si schiaccia, allargare la curva.
8. **Pompa**: è circa sette volte più grande del necessario e ha il corpo in ottone nichelato. Usarla a velocità bassa
   e sciacquarla dopo candeggio e fissaggio. Una peristaltica resta l'alternativa.
9. **Firmware**: il processo funziona com'è. Pulizia, svuotamento, autotest dei flussi e risciacquo linea no; il
   caricamento e la taglierina sono da scrivere. Tutto in `docs/note_firmware.md`.
10. **Riscaldatori**: non devono mai lavorare a secco; il modulo IRF540 in distinta va sostituito (vedi distinta).
11. **Il 120 resta semi-manuale**: la carta va accompagnata a mano.
12. **Sensori di livello delle vaschette**: non usati; sei XKC-Y21 e il flussimetro avanzano.
13. **PDF 3D**: si naviga solo con Adobe Acrobat Reader su computer.

## Sicurezza elettrica

La rete a 230 V entra solo nell'alimentatore, dentro il vano chiuso. Collegare la terra, usare una presa protetta da
differenziale e tenere chiuso il vano quando la macchina è alimentata: accanto ci sono acqua e chimica. Tutto il
resto lavora a 12 V. È un progetto amatoriale, non certificato.

## Rigenerare i file

```
cd src
sh all.sh /percorso/IDTFConverter   # tutto in una volta (circa 20 minuti); oppure, un passo alla volta:
python3 build_all.py            # pezzi STEP/STL, verifiche, assieme STEP (circa 12 minuti)
python3 previews.py             # viste e sezioni
python3 schemi.py && python3 dima.py && python3 make_bom.py
python3 make_pdf3d.py /percorso/IDTFConverter
```

Servono Python con CadQuery 2, VTK, matplotlib, openpyxl; per il PDF 3D anche `IDTFConverter`
(github.com/ningfei/u3d) e LaTeX con il pacchetto `media9`.

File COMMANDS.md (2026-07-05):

# FilMachine_Reworked — Comandi utili

Riferimento rapido per build, flash e gestione config.
Tutti i comandi si lanciano dalla root del repo salvo diversa indicazione:

```bash
cd ~/Documents/GitHub/FilMachine_Reworked
```

---

## 1. Simulatore (PC, macOS — SDL2 + LVGL)

Prerequisiti (una tantum):

```bash
brew install sdl2 pkg-config
```

Build ed esecuzione (uso una build dir dedicata per non collidere con la cache ESP-IDF):

```bash
cmake -B build_sim -S .
cmake --build build_sim -j
./build_sim/filmachine_sim
```

- Stop simulatore: **Ctrl+C** nel terminale (oppure chiudi la finestra SDL / `pkill filmachine_sim`).
- `F2` = overlay di debug UI, click destro = dump widget.
- LVGL v9.5 viene clonato in automatico se manca.

---

## 2. Build per la board (ESP32-P4 / JC4880P433)

```bash
source ~/esp/esp-idf-v5.5/export.sh
idf.py set-target esp32p4        # solo la 1ª volta o se cambi target (fa fullclean)
idf.py -D CMAKE_C_FLAGS="-DBOARD_JC4880P433" reconfigure
idf.py -D CMAKE_C_FLAGS="-DBOARD_JC4880P433" build
```

Note:
- Richiede **ESP-IDF 5.5.x** (l'ESP32-P4 non è supportato da versioni precedenti).
- `set-target` serve solo la prima volta o dopo aver cambiato target; le volte successive bastano `reconfigure` + `build`.

---

## 3. Flash e monitor

```bash
idf.py -p /dev/cu.usbmodem101 flash monitor      # flash + seriale (Ctrl+] per uscire dal monitor)
idf.py -p /dev/cu.usbmodem101 flash              # solo flash
idf.py -p /dev/cu.usbmodem101 monitor            # solo monitor
```

Se non conosci la porta:

```bash
ls /dev/cu.usb*
```

### Script all-in-one

`./flash_p4.sh` esegue tutto: set-target (se serve), patch sdkconfig per P4 (flash 16MB, PSRAM 32MB HEX, WebSocket…), build, detect porta, flash e monitor.

```bash
./flash_p4.sh
```

---

## 4. Config / processi (genFilMachineCFG.py)

Genera i file `FilMachine.cfg` + `_Backup.cfg` + `.json` nel formato letto da `readConfigFile`.

```bash
# 8 processi realistici di sviluppo pellicola (C41, D-76, Rodinal, E6, HC110…)
python3 scripts/genFilMachineCFG.py --realistic --output sd/

# realistici + extra per arrivare a N processi
python3 scripts/genFilMachineCFG.py --realistic --processes 12 --output sd/

# dati random (nomi a caratteri casuali)
python3 scripts/genFilMachineCFG.py --output sd/

# import da un JSON esistente
python3 scripts/genFilMachineCFG.py --from-json scripts/FilMachine.json --output sd/
```

Il simulatore legge `sd/FilMachine.cfg` relativo alla dir da cui lo lanci.
Se all'avvio compaiono warning "File may be corrupt", il `.cfg` in `sd/` è di un formato struct vecchio: rigeneralo con lo script.

### Copiare il config sulla microSD della board

Dopo aver rigenerato `sd/FilMachine.json` (config JSON-only), copialo sulla microSD (il nome del volume di default è `NO NAME` — adatta se diverso). **Il `sync` + `eject` sono obbligatori**, altrimenti macOS non flusha la scrittura e la board rilegge il file vecchio:

```bash
cp ~/Documents/GitHub/FilMachine_Reworked/sd/FilMachine.json        "/Volumes/NO NAME/FilMachine.json"
cp ~/Documents/GitHub/FilMachine_Reworked/sd/FilMachine_Backup.json "/Volumes/NO NAME/FilMachine_Backup.json"
sync && diskutil eject "/Volumes/NO NAME"
```

Verifica all'avvio nel monitor: `Config JSON loaded: <N> processes`.
`settingsSize` deve combaciare col firmware e `rawProcessCount` col numero di processi nel file (se leggi un numero enorme, firmware e config non sono allineati → rigenera + rebuild pulito).

---

## 5. Pulizia

```bash
rm -rf build_sim          # cache simulatore
idf.py fullclean          # cache build ESP-IDF
rm -rf build800           # cache vecchia ereditata da Simulator_v2 (rigenerabile)
```

---

## 6. Git

```bash
git status
git add -A && git commit -m "messaggio"
git log --oneline -10
```

---

## Versione firmware

Fonte unica di verità: **`version.txt`** nella root (formato `MAJOR.MINOR.PATCH.BUILD`).
Lo stesso valore viene mostrato identico su **Splash** e su **Tools → Software version**, sia sul board che nel simulatore.

- Sul board: ESP-IDF usa `version.txt` come versione dell'app (`ota_get_running_version()`).
- Nel simulatore: iniettata via `-DFW_VERSION_STR` dal CMakeLists.
- **Auto-incremento**: `./flash_p4.sh` incrementa il campo BUILD a ogni build.

```bash
./scripts/bump_version.sh          # incrementa BUILD (0.0.0.1 -> 0.0.0.2)
./scripts/bump_version.sh --show   # mostra la versione corrente
```

Per un rilascio "vero" (major/minor/patch) modifica a mano `version.txt`, es. `0.1.0.0`.

---

## Costanti di taratura utili (main/include/FilMachine.h)

| Costante | Valore | Effetto |
|---|---|---|
| `MOTOR_MIN_ANALOG_VAL` | 90 | Duty motore allo slider al minimo (10%). Alza se il motore stenta a partire. |
| `MOTOR_MAX_ANALOG_VAL` | 255 | Duty motore al massimo (100%). |
| `PUMP_MIN_ANALOG_VAL` | 120 | Duty pompa allo slider al minimo (10%). Alza se la pompa non parte. |
| `PUMP_MAX_ANALOG_VAL` | 250 | Duty pompa al massimo (100%, limite sicuro DBH-12V). |
| `PUMP_DEFAULT_SPEED` | 200 | Fallback (azioni manuali/checkup). |

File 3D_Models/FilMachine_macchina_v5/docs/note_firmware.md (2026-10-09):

# Note per il firmware (FilMachine_Reworked)

Cosa funziona così com'è con questa macchina, cosa no e qual è la modifica più piccola possibile.
Ho letto il codice del repository (`main/accessories.c`, `c_pages/page_checkup.c`, i popup in `c_elements/`,
`boards/board_jc4880p433.h`); **non ho potuto provarlo su una macchina vera**.

## 1. Collegamenti

I pin sono quelli di `boards/board_jc4880p433.h`; l'unico cambiamento è GPIO28, ora dedicato al servo della taglierina. Lo schema è in `schema_elettrico.pdf`.

| Funzione | Pin | Dove va |
|---|---|---|
| Motore spirale: ENA / IN1 / IN2 | GPIO32 / 33 / 34 (JP1 19 / 8 / 17) | ponte H, canale A |
| Pompa: ENA / IN1 / IN2 | GPIO51 / 49 / 50 (JP1 9 / 13 / 11) | ponte H, canale B |
| I2C SDA / SCL | GPIO7 / 8 (JP1 23 / 25) | driver Adafruit #6318 (MCP23017, 0x20) |
| Elettrovalvole C1, C2, C3, WB, scarico | MCP23017 A0…A4 | uscite MOSFET del driver (sul collettore le valvole stanno nell'ordine C1, WB, C2, C3, scarico: conta il collegamento, non la posizione) |
| Riscaldatori 1 e 2 | MCP23017 B6, B7 | due moduli MOSFET |
| Sonde DS18B20 (0 = bagno, 1 = chimica) | GPIO35 (JP1 15) | bus OneWire |
| Livello bagno MIN / MAX | GPIO29 / 30 (JP1 14 / 12) | due XKC-Y21 sulla parete del bagno |
| Sensore Hall | GPIO31 (JP1 10) | KY-003 sulla ruota magneti (4 magneti) |
| Servo della taglierina | GPIO28 (JP1 21, ora `CUTTER_SERVO_PIN`) | MG90S, LEDC timer 3 / canale 3 a 50 Hz; alimentazione 5 V dal convertitore, massa comune, 10 kΩ verso massa sul segnale |

Non collegati su questa macchina: i sei ingressi B0…B5 (livelli delle vaschette) e il flussimetro (GPIO52).
Con il servo su GPIO28 non resta nessun pin libero su JP1; se servisse, GPIO52 si libera solo cambiando il codice del riempimento.

## 2. Cosa funziona senza toccare il codice

- **Tutto il processo di sviluppo**: riempimento e svuotamento della tank (`sendValueToRelay()` apre una valvola e
  fa girare la pompa in un verso), ritorno della chimica nella sua vaschetta, scarto, agitazione, controllo della
  temperatura con i due riscaldatori, consenso del sensore Hall alla partenza.
- **Risciacqui con l'acqua del bagno** (passi con sorgente `WB`, sempre scartati).
- **Riempimento manuale del bagno**: impostazione *Ingresso acqua* spenta.
- **Volumi**: usare *Volume chimica = Basso* con *Tank = Piccola* (250 ml) o *Media* (350 ml). Con 250 ml il
  liquido arriva a 34 mm dal fondo, con 350 ml a 46 mm; l'asse della spirale è a 50 mm, il troppopieno a circa 500 ml.
  **Non usare 550 ml né il volume Alto.** Il troppopieno smaltisce circa 0,4 l/min, mentre il riempimento ne porta
  quasi 2 (250 ml in 8 s): l'eccesso non farebbe in tempo a uscire e passerebbe nel vano del caricatore. Conviene
  togliere dal menu, o bloccare, le combinazioni oltre 350 ml.
- **Tempi di riempimento**: rifare la taratura dei tempi (chimica e WB) con la velocità pompa scelta. Tenere la
  pompa bassa: è molto più grande di quanto serve.

## 3. Cosa non funziona con una pompa e un collettore unico

Il codice usa due primitive. `sendValueToRelay(valvola, verso)` apre **una** valvola: funziona, perché la pompa sta tra
il collettore e la tank. `cleanRelayManager(da, a, verso)` apre **due** valvole insieme e fa girare la pompa: i due
recipienti sono però dalla stessa parte della pompa, quindi il liquido non va dall'uno all'altro ma finisce (o viene
preso) nella tank. Il commento in `handleLineRinse()` lo anticipa: la combinazione valvole/pompa «dipende
dall'impianto reale».

| Funzione | Cosa fa il codice | Cosa succede qui | Cosa fare |
|---|---|---|---|
| Risciacquo linea (`lineRinseEnabled`) | WB aperta + pompa OUT | spinge verso il bagno quello che resta nel tubo della tank | spegnerla; mettere nel processo un passo WB breve dopo ogni chimica (stesso effetto) |
| Pulizia (popup) | WB + scarico aperte, pompa IN | riempie la tank senza fermarsi: il troppopieno non basta, il liquido passa nel vano del caricatore | **non avviarla**; non serve: le vaschette si lavano al lavandino; per tubi e tank creare un processo «Pulizia» con 2–3 passi WB |
| Svuota contenitori (popup) | Cx + scarico aperte, pompa IN | manda la chimica nella tank, che ne tiene mezzo litro | **non avviarla**; non serve: le vaschette si sollevano e si versano; il bagno si svuota dal rubinetto manuale |
| Autotest, fasi di flusso (WB→Cx, Cx→WB, WB→scarico) | due valvole + pompa | flussi diversi da quelli attesi | saltare queste fasi oppure applicare la modifica del punto 4 |
| Riempimento vaschetta da WB | WB + C1, pompa IN, sensori di livello | non riempie la vaschetta: riempie la tank, e senza sensori non si ferma | **non avviarlo**; non serve: le vaschette si riempiono a mano |
| Riempimento macchina con flussimetro | apre WB senza pompa (acqua in pressione) | non c'è ingresso in pressione | lasciare *Ingresso acqua* spento |

I sensori di livello delle vaschette (`chemLevelMinDetected()` / `chemLevelMaxDetected()`) sono letti solo da queste
funzioni di manutenzione e dalla pagina di diagnostica: senza sensori il processo non cambia, restano grigi i sei
pallini nella diagnostica.

## 4. Modifica minima consigliata: trasferire passando per la tank

Se si vogliono tenere pulizia, svuotamento e autotest, basta cambiare **solo** `cleanRelayManager()`: invece di aprire
due valvole insieme, alterna «riempi la tank dalla sorgente» e «svuota la tank nella destinazione» finché viene
fermata. La tank fa da misurino (250–350 ml per ciclo). Tutto il resto del codice (popup, tempi, interfaccia) resta com'è.

Traccia **non provata**, da adattare ai nomi reali:

```c
/* accessories.c - trasferimento a due tempi attraverso la tank */
#define XFER_FILL_S   8      /* secondi di riempimento della tank (taratura a 250 ml) */
#define XFER_DRAIN_S  10     /* secondi di svuotamento, un po' piu' lungo del riempimento */

static lv_timer_t *s_xferTimer = NULL;
static uint8_t s_xferFrom, s_xferTo, s_xferPhase;   /* fase 0 = riempie, 1 = svuota */
static uint16_t s_xferSecs;

static void xfer_timer_cb(lv_timer_t *t) {
    if (++s_xferSecs < (s_xferPhase == 0 ? XFER_FILL_S : XFER_DRAIN_S)) return;
    s_xferSecs = 0;
    pump_stop();
    mcp23017_digitalWrite(&mcp, s_xferPhase == 0 ? s_xferFrom : s_xferTo, 0);
    s_xferPhase ^= 1;
    mcp23017_digitalWrite(&mcp, s_xferPhase == 0 ? s_xferFrom : s_xferTo, 1);
    pump_run(s_xferPhase == 0, pumpSpeedToDuty());      /* true = IN (riempie), false = OUT (svuota) */
}

void cleanRelayManager(uint8_t pumpFrom, uint8_t pumpTo, uint8_t pumpDir, bool activePump) {
    (void)pumpDir;                                       /* il verso lo decide la fase */
    if (s_xferTimer) { lv_timer_delete(s_xferTimer); s_xferTimer = NULL; }
    pump_stop();
    for (uint8_t i = 0; i < RELAY_NUMBER; i++) mcp23017_digitalWrite(&mcp, i, 0);
    if (!activePump) {
        /* alla fine la tank puo' essere piena: svuotarla con sendValueToRelay(pumpTo, PUMP_OUT_RLY, ...) */
        return;
    }
    s_xferFrom = pumpFrom; s_xferTo = pumpTo; s_xferPhase = 0; s_xferSecs = 0;
    mcp23017_digitalWrite(&mcp, pumpFrom, 1);
    pump_run(true, pumpSpeedToDuty());
    s_xferTimer = lv_timer_create(xfer_timer_cb, 1000, NULL);
}
```

Da decidere a banco: i due tempi, e uno svuotamento finale della tank quando il trasferimento viene fermato a metà.
Per il risciacquo linea, la stessa idea in `handleLineRinse()`: `sendValueToRelay(WB, PUMP_IN)` per qualche secondo,
poi `sendValueToRelay(WASTE, PUMP_OUT)`.

## 5. Caricamento della pellicola e taglierina: implementato (da provare sulla macchina)

Il caricamento c'è nel firmware e nell'app. Le modifiche sono nei due repository locali, **non ancora committate**.
Il firmware compila per ESP32-P4 (ESP-IDF 5.5.1) senza avvisi nei file toccati; la logica è provata solo nel
simulatore e nei test automatici, non sulla scheda.

### Come funziona

| Fase | Cosa fa | Come finisce |
|---|---|---|
| Avvolgimento | motore della spirale avanti alla *velocità di caricamento* (40 % di default); conta gli impulsi Hall (4 per giro) | la spirale si ferma, oppure *Taglia ora*, oppure un errore |
| Taglio | servo da riposo a fine taglio in 0,9 s, fermo 0,3 s, ritorno in 0,6 s, poi il segnale si spegne | fine del movimento |
| Coda | mezzo giro (2 impulsi) per tirare dentro la coda | 2 impulsi oppure 4 s |
| Fatto | motore fermo, un bip sul display | — |

- **Fine del rullino**: la spirale è considerata ferma se non arriva un impulso per 3 volte l'intervallo medio degli
  ultimi impulsi, mai meno di 2,5 s. Funziona a qualunque velocità.
- **Taglio automatico**: il motore resta acceso, la cinghia slitta e tiene tesa la pellicola sulla lama.
  **Taglia ora** (per esempio quando nel 120 compare il nastro): la pellicola si sta ancora muovendo, quindi il motore
  si ferma per il taglio e riparte per la coda.
- **Protezioni** (motore fermo, lama a riposo, pellicola **non** tagliata):

| Errore | Quando | Valori di partenza |
|---|---|---|
| La spirale non gira | nessun impulso dopo l'avvio | 5 s |
| Ferma troppo presto | stallo prima dei giri minimi: clip sganciata o pellicola incastrata | 135: 4 giri, 120: 2 giri |
| Troppi giri | la fine della pellicola non è trattenuta | 135: 15 giri, 120: 9 giri |
| Troppo lungo | tempo massimo dell'avvolgimento | 180 s |

  Giri attesi, per la barra: 9 per il 135 × 36, 5 per il 120. Tutte le soglie sono in testa a `main/film_loader.c`.
- **Blocchi**: il caricamento non parte durante un processo; durante il caricamento vengono rifiutati l'avvio di un
  processo (`start_rejected`) e il test del motore da Tune.
- **Registro**: ogni caricamento scrive nel log (e quindi nel file di avvio sulla SD) formato, impulsi e giri:
  dopo qualche rullino vero si correggono le soglie.

### File

| File | Cosa contiene |
|---|---|
| `main/film_loader.c` | macchina a stati, sequenza del servo, task da 20 ms; nel simulatore un modello di spirale/Hall/servo |
| `drivers/servo.c`, `drivers/include/servo.h` | PWM a 50 Hz su LEDC timer 3 / canale 3 |
| `drivers/sensors.c` | contatore di impulsi Hall in interrupt (fronte di discesa, antirimbalzo 30 ms); `sensors_hall_magnet_detected()` resta com'era |
| `c_elements/element_loadPopup.c` | popup *Carica pellicola*: 135/120, stato, barra dei giri, Chiudi/Annulla · Prova lama/Taglia ora · Avvia/Stop |
| `c_pages/page_tools.c`, `main/ui_profile_800x480.inc` | nuova riga in Manutenzione; le sezioni sotto scendono di 57 px |
| `main/ws_server.c` | comandi e campi di stato (sotto) |
| `main/accessories.c`, `c_pages/page_settings.c` | tre impostazioni nuove salvate nel config; GPIO28 tenuto basso all'avvio |
| `boards/board_jc4880p433.h` | `TEST_PIN` → `CUTTER_SERVO_PIN` |
| `main/lang.c`, `lang.h`, `FilMachine.h`, `scripts/gen_lang.py` | 15 testi EN/IT |
| `tests/test_film_loader.c` | 11 test; il runner accetta `FM_TEST_ONLY=film_loader` (o una lista separata da virgole) |

### Impostazioni (config JSON, `set_setting`, *Ripristina predefiniti*)

| Chiave | Default | Limiti |
|---|---|---|
| `loadSpeed` | 40 % | 10–100 |
| `cutterRestUs` | 500 µs (manovella 0°) | 400–2600 |
| `cutterCutUs` | 2400 µs (manovella 180°) | 400–2600 |

### Protocollo WebSocket

```
{"cmd":"load_start","format":0|1}     0 = 135, 1 = 120; apre lo stesso popup sul display
{"cmd":"load_stop"}                    motore fermo, lama a riposo
{"cmd":"load_cut"}                     taglia ora (solo durante l'avvolgimento)
{"cmd":"cutter_test","angle":0..180}   tiene la manovella in posizione per 4 s (taratura)
{"cmd":"cutter_cycle"}                 prova lama: su e giù, motore fermo
```
Stato: `loadToolState` (0 fermo, 1 avvolgimento, 2 taglio, 3 coda, 4 fatto, 5 interrotto, 6–9 errori),
`loadToolFormat`, `loadToolPulses`, `loadToolExpected`, `loadToolServo`, più `loadSpeed`, `cutterRestUs`,
`cutterCutUs`. Eventi: `load_rejected` (`processing` o `busy`), `start_rejected` (`loading`).

### App

Strumenti → *Caricatore pellicola* apre la schermata *Caricamento pellicola*: scelta 135/120, istruzioni del formato,
stato con le stesse frasi del display, barra dei giri, e in *Taratura* la velocità di caricamento e i due fine corsa
del servo con il pulsante *Prova*. I pulsanti in basso sono gli stessi del display; uscire durante il caricamento
equivale ad Annulla. Testi del firmware rigenerati con `scripts/gen_app_strings.py`.

### Verifiche fatte

- Firmware: build ESP-IDF 5.5.1 per esp32p4 riuscita; simulatore e runner compilati; 11 test nuovi passati;
  131 test delle altre suite uguali a prima (le due suite che già fallivano, *Settings* e *Board constants*,
  falliscono allo stesso modo anche senza le modifiche).
- Popup provato nel simulatore in inglese e in italiano, compreso l'errore più lungo su tre righe.
- App: `flutter analyze` con gli stessi 18 avvisi di prima, nessuno nei file nuovi; 259 test passati (11 nuovi).

### Ordine di prova a banco

1. Flash, poi Strumenti → Carica pellicola → *Prova lama* senza servo collegato: nel log compare il movimento.
2. Servo collegato, senza lama: dall'app tarare `cutterRestUs` (lama sotto la fessura) e `cutterCutUs` (filo oltre il
   cielo della fessura sui due bordi) con *Prova*.
3. Conteggio Hall: avviare un caricamento a vuoto e far girare la spirale; i giri devono salire di 1 ogni 4 magneti.
4. Stallo: frenare la spirale con la mano dopo 5 giri → deve tagliare; dopo 2 giri → *Ferma troppo presto*.
5. Spezzone di pellicola di scarto agganciato a un rocchetto, poi un rullino vero; leggere nel log i giri e
   correggere le soglie.

## 6. Riscaldatori: una cosa da cambiare nell'hardware

Ogni riscaldatore assorbe 8,3 A. Il modulo IRF540 in distinta, pilotato così, dissipa circa 5 W per canale e senza
dissipatore si surriscalda. Nella nuova distinta ci sono due moduli MOSFET da 15 A a bassa resistenza: stessi
segnali (B6 e B7 alti = acceso), nessuna modifica al codice.

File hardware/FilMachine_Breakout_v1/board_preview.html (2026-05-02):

# FilMachine Breakout Board v1.0

JC4880P433 — J9 Expand IO Breakout — 70mm × 50mm, 2-layer FR4

IMPORTANTE: I pin di alimentazione del J9 (pin 1, 2, 14, 18, 20, 22, 24, 26) sono basati sulla convenzione tipica dei connettori Guition. VERIFICA con un multimetro prima del primo collegamento che 3V3, 5V e GND siano sui pin corretti!

### Specifiche PCB

Dimensioni | 70mm × 50mm
Layer | 2 (F.Cu + B.Cu)
Spessore | 1.6mm FR4
Finitura | HASL (lead-free)
Solder mask | Verde
Fori di fissaggio | 4× M2 (angoli)

### Connettore J9 → Gruppi funzionali

J2 MOTOR | ENA (PWM), IN1, IN2
J3 TEMP | DS18B20 DATA + power
J4 FLOW | YF-S201 SIG + power
J5 I2C | SDA, SCL, 3V3, GND (MCP23017 + PCA9685)
J6 WATER | XKC-Y21 MIN/MAX + power
J7 HALL | KY-003 SIG + power
J8 SPARE | 8 GPIO liberi (header)
J10 PWR | 5V, 3V3, GND, GND extra

### Componenti passivi integrati

R1 | 4.7kΩ — I2C SDA pull-up a 3V3
R2 | 4.7kΩ — I2C SCL pull-up a 3V3
R3 | 4.7kΩ — OneWire pull-up a 3V3
C1 | 100nF — I2C bus decoupling
C2 | 100nF — Power rail decoupling

### Costi stimati

PCB (5 pz, JLCPCB) | ~$2-5
Componenti (1 board) | ~$2-3
Spedizione | $8-20
Totale primo lotto | ~$15-25

### Bill of Materials

Ref | Qty | Valore | Package | Descrizione | ~Costo
J1 | 1 | 2×13 F | 2.54mm TH | Female pin header per innesto su J9 | $0.30
J2 | 1 | 3P | KF301 5.08mm | MOTOR: ENA / IN1 / IN2 | $0.20
J3 | 1 | 3P | KF301 5.08mm | TEMP: DATA / 3V3 / GND | $0.20
J4 | 1 | 3P | KF301 5.08mm | FLOW: SIG / 3V3 / GND | $0.20
J5 | 1 | 4P | KF301 5.08mm | I2C: SDA / SCL / 3V3 / GND | $0.25
J6 | 1 | 4P | KF301 5.08mm | WATER: MIN / MAX / 3V3 / GND | $0.25
J7 | 1 | 3P | KF301 5.08mm | HALL: SIG / 3V3 / GND | $0.20
J8 | 1 | 1×8 M | 2.54mm TH | Spare GPIO header | $0.10
J10 | 1 | 4P | KF301 5.08mm | POWER: 5V / 3V3 / GND / GND | $0.25
R1 | 1 | 4.7kΩ | 0805 SMD | I2C SDA pull-up | $0.01
R2 | 1 | 4.7kΩ | 0805 SMD | I2C SCL pull-up | $0.01
R3 | 1 | 4.7kΩ | 0805 SMD | OneWire pull-up | $0.01
C1 | 1 | 100nF | 0805 SMD | I2C decoupling | $0.01
C2 | 1 | 100nF | 0805 SMD | Power decoupling | $0.01
MH1-4 | 4 | M2 | 2.2mm hole | Fori di fissaggio | —

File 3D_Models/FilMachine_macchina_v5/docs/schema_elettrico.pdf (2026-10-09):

# FilMachine - schema elettrico (collegamenti come nel firmware: boards/board_jc4880p433.h)

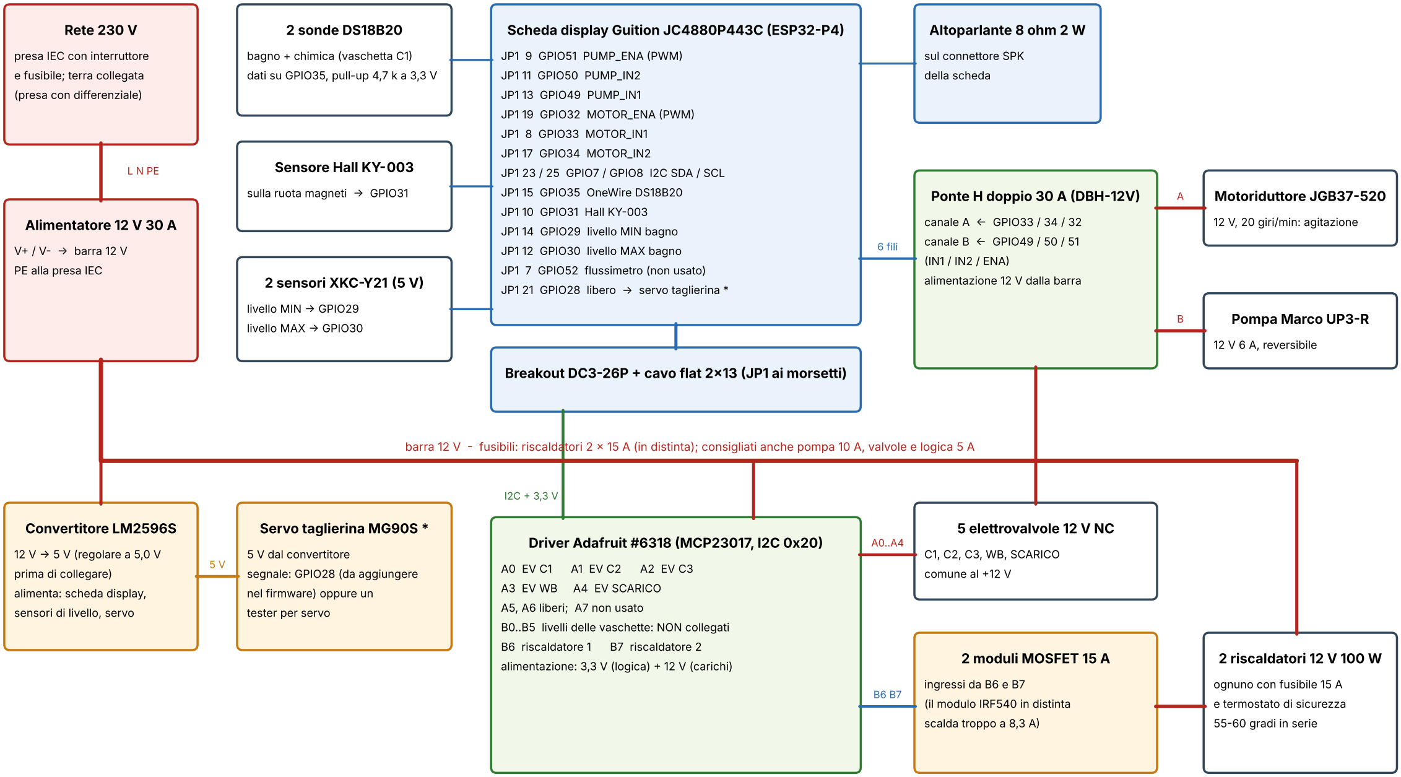
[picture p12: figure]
Rete 230 V; presa IEC con interruttore; e fusibile; terra collegata; (presa con differenziale); Alimentatore 12 V 30 A; V+ / V- -> barra 12 V; PE alla presa IEC; Convertitore LM2596S; 12 V -> 5 V (regolare a 5,0 V; prima di collegare); alimenta: scheda display,; sensori di livello, servo; 2 sonde DS18B20; bagno + chimica (vaschetta C1); dati su GPIO35, pull-up 4,7 k a 3,3 V; Sensore Hall KY-003; sulla ruota magneti -> GPIO31; 2 sensori XKC-Y21 (5 V); livello MIN -> GPIO29; livello MAX -> GPIO30; Servo taglierina MG90S *; 5 V dal convertitore; segnale: GPIO28 (da aggiungere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

### Scheda display Guition JC4880P443C (ESP32-P4)

JP1 21 GPIO28 libero -> servo taglierina *

### Breakout DC3-26P + cavo flat 2x13 (JP1 ai morsetti)

### Driver Adafruit #6318 (MCP23017, I2C 0x20)

B0..B5 livelli delle vaschette: NON collegati

alimentazione: 3,3 V (logica) + 12 V (carichi) barra 12 V - fusibili: riscaldatori 2 x 15 A (in distinta); consigliati anche pompa 10 A, valvole e logica 5 A

* Taglierina e ciclo di caricamento non esistono ancora nel firmware: vedi docs/note_firmware.md. Masse (GND) tutte in comune. Cavi di potenza a 12 V (riscaldatori, pompa): almeno 1,5 mm2.

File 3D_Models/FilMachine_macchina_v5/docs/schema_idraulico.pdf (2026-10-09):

## FilMachine - schema idraulico

Una valvola per recipiente su un collettore unico; pompa reversibile tra collettore e tank. Tubo 3/8" (9,52 mm), raccordi a innesto rapido.

BAGNO termostatico
circa 7,4 l d'acqua

C1

EV C1

C2

EV C2

C3

EV C3

3 vaschette GN 1/9 (1 litro di chimica ciascuna) con testina pescante: si tolgono sollevandole

innesti a sifone
(silicone 8x12)

pescante
acqua (WB)

EV WB

COLLETTORE (C07) sulla macchina le valvole stanno, da sinistra: C1, WB, C2, C3, scarico

EV SCARICO

SCARICO (pompato)

P

pompa a ingranaggi reversibile Marco UP3-R (PWM basso)

IN = riempie la tank

OUT = svuota la tank

TANK con spirale e caricatore

pescante
dall'alto:
nessun foro
sotto il livello

TROPPOPIENO (a gravita')

soglia troppopieno: 500 ml (smaltisce circa 0,4 l/min)

250 / 350 ml

scarico manuale del bagno
(rubinetto, facoltativo)

Riempimento della tank: EV della sorgente aperta + pompa IN.
Ritorno al recipiente: stessa EV + pompa OUT. Scarto: EV SCARICO + pompa OUT.
I risciacqui prendono l'acqua dal bagno (sorgente WB) e la mandano allo scarico.
Nel bagno (contenitore Euro 400x300x170): 2 riscaldatori 12 V 100 W, 2 sensori di livello, sonda DS18B20.

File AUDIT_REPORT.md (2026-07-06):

# FilMachine — Audit Report

**Data:** 6 luglio 2026 · **Firmware:** v0.0.0.50 (git clean, HEAD `932eeb8`) · **App Flutter:** filmachine_app

---

## 1. Stato generale

Il progetto è in buona salute: repo git pulito, nessun TODO/FIXME nei sorgenti, ultimo run dei test firmware **180/180 PASS** (03/04/2026) e test Flutter **240/240 PASS**. I problemi trovati sono per lo più pulizia e disallineamento app↔firmware.

## 2. Pendenze e pulizia (firmware)

| # | Gravità | Problema | Dettaglio |
|---|---|---|---|
| 1 | Media | **App Flutter senza repository git** | `filmachine_app` non è versionata: nessun backup/storia. Consigliato `git init` + remote. |
| 2 | Bassa | **README.md cita `pca9685.c` rimosso** | README righe 117 e 119: il driver legacy non esiste più in `drivers/`. Da aggiornare la directory structure. |
| 3 | Bassa | **README incompleto sulle settings WS** | La sezione WebSocket non elenca `lineRinseEnabled`, `lineRinseTime`, `invertPump`, `brightness`, `volume`, splash*. |
| 4 | Bassa | **Clutter locale (già gitignored)** | `build800/` (124 MB, target obsoleto), `sdkconfig.old`, `dependencies.lock.simv2_bak`. Eliminabili senza rischio. |
| 5 | Bassa | **`test_results/` con ~30 file storici** | Solo l'ultimo run è utile; i vecchi (marzo 2026) sono eliminabili. |
| 6 | Info | **`resources/` pesa 791 MB** | Contiene il dump demo del vendor (JC4880P443C). Utile come riferimento ma appesantisce il repo/backup. |

**Falsi allarmi verificati:** `audio.c` è correttamente board-only (escluso dal simulatore by design); `page_splash.c` è dichiarato una sola volta nel CMakeLists; nessun test attualmente fallito.

### 2b. Residui di vecchie implementazioni (scan approfondito)

Nessun TODO/FIXME/HACK nei sorgenti. Residui trovati:

| Elemento | Dove | Stato |
|---|---|---|
| `chemContainerMl*` / `wbContainerMl*` (testi UI, liste roller, 6 puntatori `lv_obj_t`) | `FilMachine.h` righe 320-329 e ~1500-1506 | Vecchia impostazione "container in ml", sostituita da `chemCalibFillSecs`/`wbCalibFillSecs`. Quasi tutti a 0 riferimenti nei .c → **rimovibili** |
| `pump_brake()` | `accessories.c:172` | Definita, `__attribute__((unused))`, mai chiamata → rimovibile |
| `isPumping` | `page_checkup.c:44` | Commentata, "reserved for future" |
| Blocco "Reserved Icons" | `FilMachine.h:228` | Commentato, intenzionale |
| Commento stantio su `random_switch_y` | `ui_profile.h:942` | Dice "unused" ma È usato in `element_splashPopup.c:351` → correggere il commento |

Rinominazioni intenzionali per compatibilità binaria del config (da NON toccare): `volume` (ex `dimTimeout`), `chemCalibFillSecs`/`wbCalibFillSecs` (ex `chemContainerMl`/`wbContainerMl`).

## 3. Gap firmware → app (cose da aggiungere all'app)

Feature presenti nel firmware e già trasmesse via WebSocket, ma **ignorate dall'app**:

| Feature | Firmware | App | Note |
|---|---|-----|---|
| **Line rinse** (`lineRinseEnabled`, `lineRinseTime`) | ✓ inviati nello stato + `set_setting` | ✗ assenti da `MachineState` e UI | È l'ultimo commit del firmware (`932eeb8`) |
| **Calibrazione riempimento** (`chemCalibFillSecs`, `wbCalibFillSecs`) | ✓ inviati nello stato | ✗ non gestiti | Solo visualizzazione/uso, la calibrazione si fa a bordo |
| **`wifi_scan`** | ✓ implementato (ws_server.c ~824) | ✗ mai invocato | L'app mostra l'SSID in sola lettura |

## 4. Gap interni al firmware (settings non esposte via WebSocket)

Presenti in `machineSettings` (FilMachine.h righe 624-643) e usate a bordo, ma **non incluse in `build_state_json()` né gestite da `set_setting`** — quindi impossibili da controllare da app:

- `brightness` (luminosità LCD 10-100%)
- `volume` (audio 0-100%)
- `invertPump` (inversione pompa)
- `chemCalibOffset` (offset sensore temp. chimica)
- Splash screen: `splashRandom`, `splashPalette`, `splashShapeStyle`, `splashComplexity`, `splashSeed`, `splashDefault`

Per esporle all'app serve toccare **anche il firmware** (aggiunta campi in `build_state_json()` + rami in `set_setting`).

## 5. Piano consigliato

1. **App (solo lato app, nessun rischio):** supporto line rinse (state + UI settings), campi calibrazione riempimento, pulsante scan Wi-Fi.
2. **Firmware + app (opzionale):** esporre brightness/volume/invertPump/chemCalibOffset via WS e aggiungere i controlli nell'app; eventualmente anche le impostazioni splash.
3. **Pulizia:** fix README (pca9685 + elenco settings), rimozione `build800/`, `sdkconfig.old`, `*_bak`, vecchi `test_results`.
4. **Versionamento:** `git init` per l'app Flutter.

---

## 6. Interventi eseguiti (6 luglio 2026)

**Firmware (`main/ws_server.c`):** aggiunti a `build_state_json()` e a `set_setting` i campi `invertPump`, `brightness` (con applicazione live `st7701_lcd_set_user_brightness`), `volume` (con `audio_set_volume`), `chemCalibOffset`, `splashDefault`, `splashRandom`, `splashPalette`, `splashShapeStyle`, `splashComplexity` (tutti con clamp dei range). `reset_defaults` ora ripristina anche invertPump/brightness/volume/chemCalibOffset.

**App Flutter:** `MachineState` esteso con tutti i nuovi campi + `lineRinseEnabled/Time` e `chemCalibFillSecs`/`wbCalibFillSecs`; rimossi i campi rotti `calibratedTemp`, `chemContainerMl`, `wbContainerMl` (il firmware li rifiutava come chiavi sconosciute). Settings screen: aggiunti line rinse, invert pump, brightness, volume, sezione splash completa, righe read-only per la calibrazione riempimento e pulsante **Scan Wi-Fi** (nuovo `wifiScan()` nel service con gestione dell'evento `wifi_scan_results`). Tools screen aggiornata. Test del modello aggiornati.

**Residui rimossi:** `chemContainerMl*`/`wbContainerMl*` (testi, liste, puntatori GUI, handler popup, voci in `ui_debug_registry.inc`), `pump_brake()` (entrambe le definizioni), commento stantio su `random_switch_y`. README corretto (pca9685, tabella settings, tabella comandi WS con `reorder_step`/`reset_defaults`/`wifi_scan` e elenco chiavi `set_setting`).

**Verifica:** simulatore + test binary compilano senza errori con tutte le modifiche; suite WebSocket (serializzazione JSON stato) verde. Il run completo della suite non è riproducibile nell'ambiente di verifica usato (segfault del driver video SDL dummy, presente identico anche sul codice originale non modificato) — consigliato un run completo di `filmachine_test` e `flutter test` in locale.
- `main/ws_server.c` — protocollo WS (comandi riga ~678, stato riga ~479)
- `main/include/FilMachine.h` — struct settings (624-643)
- App: `lib/models/machine_state.dart`, `lib/services/machine_service.dart`, `lib/screens/settings_screen.dart`

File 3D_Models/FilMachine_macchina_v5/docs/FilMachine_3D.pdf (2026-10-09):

FilMachine assieme 3D della macchina completa | 164 corpi: 93 stampati, 71 componenti acquistati

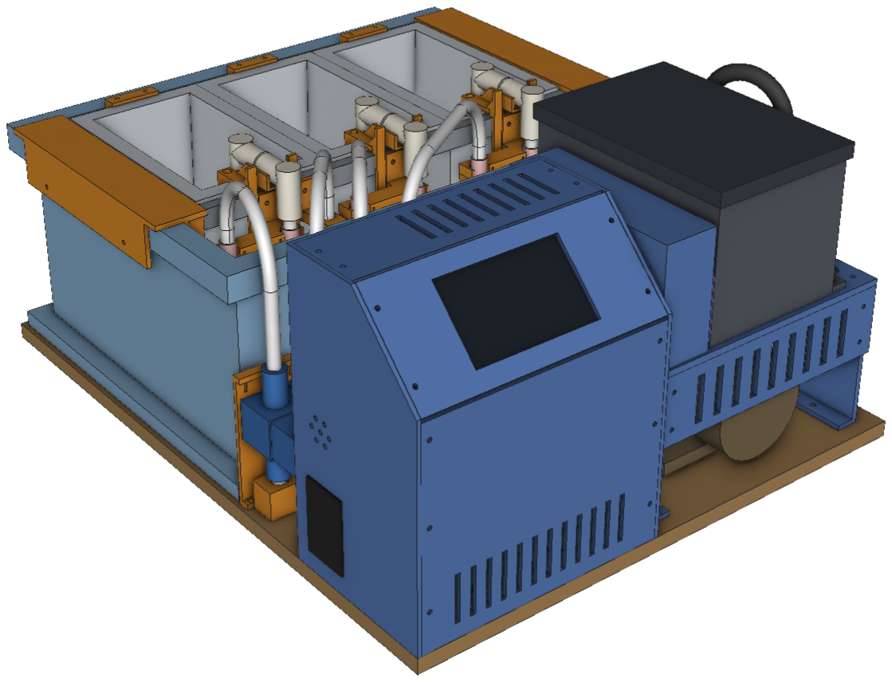
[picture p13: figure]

Si apre con Adobe Acrobat Reader (su computer; gli altri lettori PDF mostrano solo l'immagine ssa). Se compare la barra gialla, scegliere Opzioni → Considera sempre adabile il documento e fare clic sul modello. Ruotare: trascinare col tasto sinistro. Spostare: Ctrl + trascinare. Zoom: rotellina. Mostrare e nascondere i pezzi: nell'albero del modello a sinistra (pulsante nella barra 3D se non è aperto) togliere o mettere la spunta a un pezzo o a un intero gruppo; tasto destro sul pezzo → Isola, Nascondi, Trasparente. Viste pronte (menu Viste nella barra 3D): 01 Vista generale, 02 Fronte destra, 03 Retro, 04 Dall'alto, 05 Interno - senza coperchi e pannelli, 06 Solo bagno e idraulica, 07 Tank e caricatore - 135, 08 Tank e caricatore - 120, 09 Solo pezzi stampati, 10 Solo componenti acquistati.

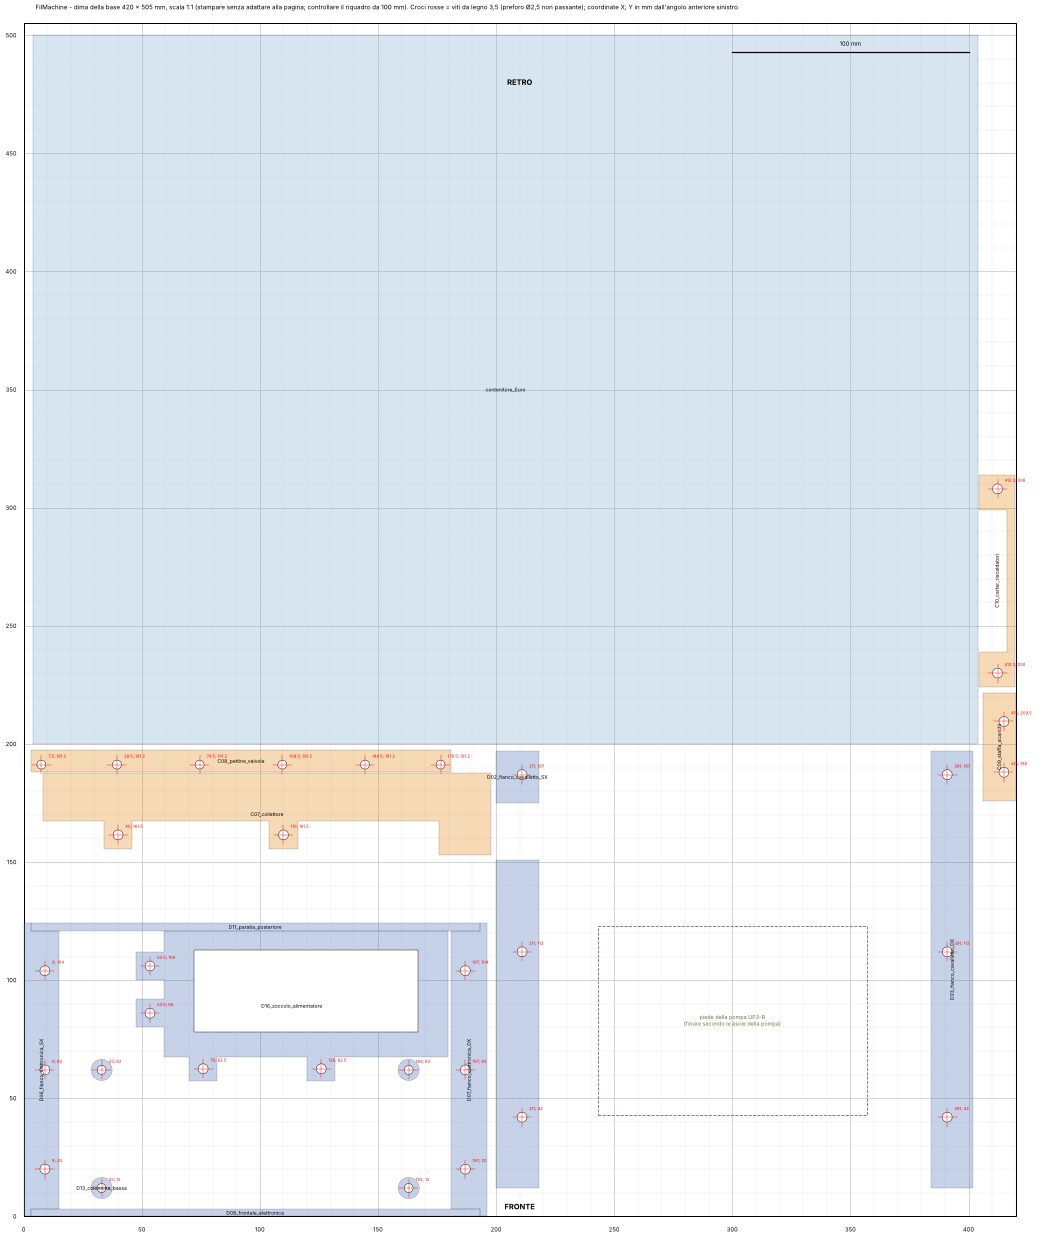
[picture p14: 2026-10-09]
3D_Models/FilMachine_macchina_v5/docs/dima_base.png

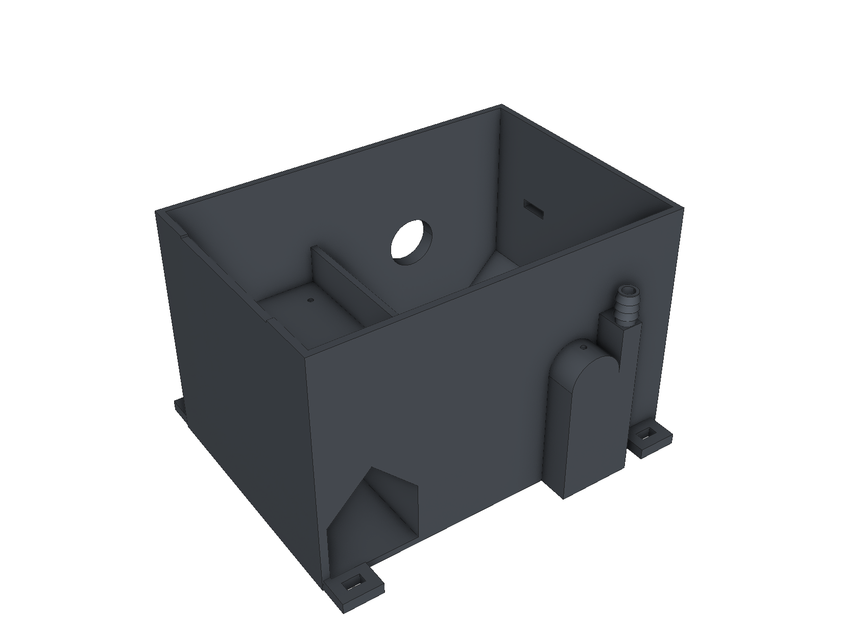
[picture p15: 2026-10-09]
3D_Models/FilMachine_macchina_v5/png/tank_corpo.png

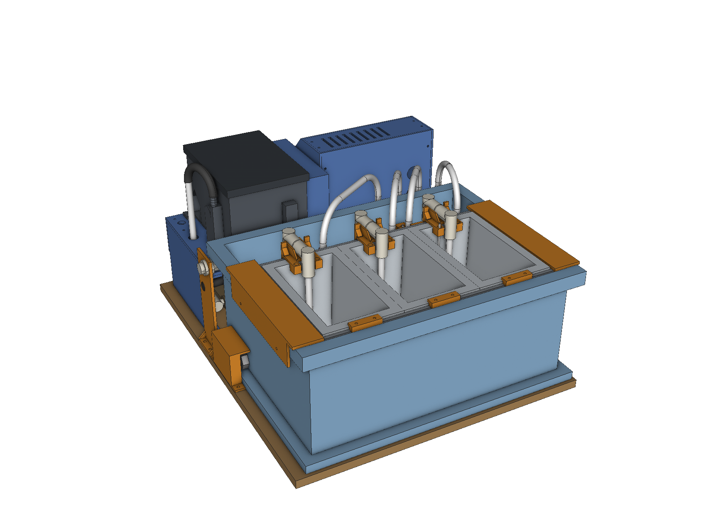
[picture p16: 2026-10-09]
3D_Models/FilMachine_macchina_v5/png/macchina_retro.png

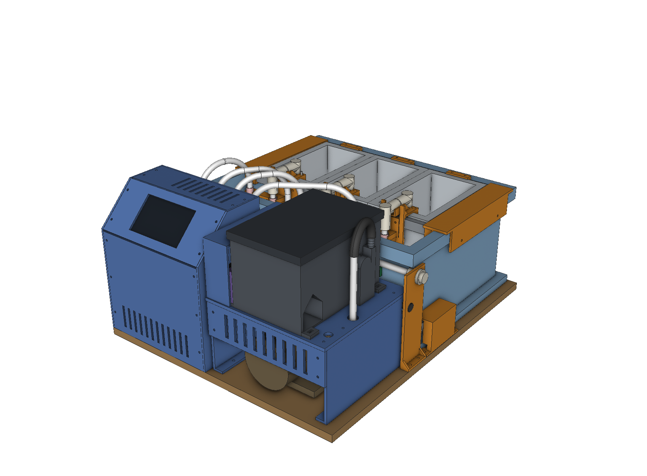
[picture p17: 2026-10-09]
3D_Models/FilMachine_macchina_v5/png/macchina_fronte_destra.png

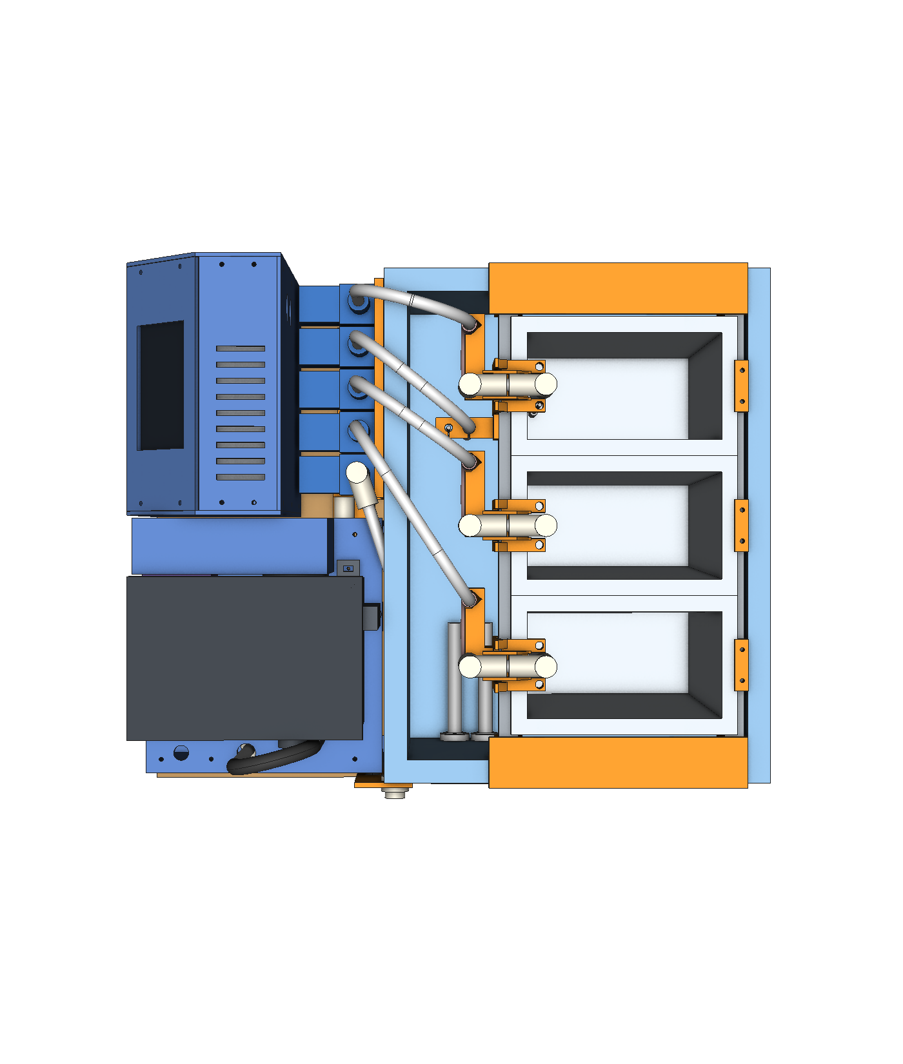
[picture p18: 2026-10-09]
3D_Models/FilMachine_macchina_v5/png/macchina_dall_alto.png

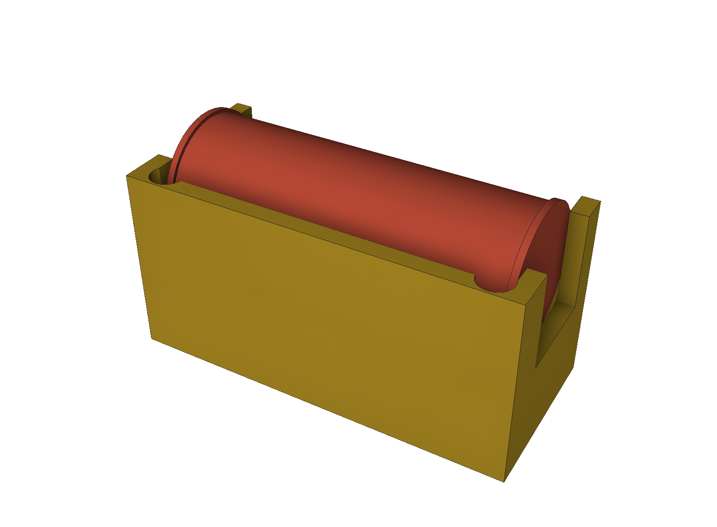
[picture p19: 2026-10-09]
3D_Models/FilMachine_macchina_v5/png/culla_universale_120.png

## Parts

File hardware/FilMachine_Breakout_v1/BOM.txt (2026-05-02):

==========================================================================================
FilMachine Breakout Board v1.0 — Bill of Materials
==========================================================================================
Ref      Qty   Value        Package              Description                         ~Cost
------------------------------------------------------------------------------------------
J1       1     2x13F        2.54mm TH            Female pin header 2×13              $0.30
J2       1     3P 5.08mm    KF301-3P             MOTOR: ENA/IN1/IN2                  $0.20
J3       1     3P 5.08mm    KF301-3P             TEMP: DATA/3V3/GND                  $0.20
J4       1     3P 5.08mm    KF301-3P             FLOW: SIG/3V3/GND                   $0.20
J5       1     4P 5.08mm    KF301-4P             I2C: SDA/SCL/3V3/GND                $0.25
J6       1     4P 5.08mm    KF301-4P             WATER: MIN/MAX/3V3/GND              $0.25
J7       1     3P 5.08mm    KF301-3P             HALL: SIG/3V3/GND                   $0.20
J8       1     1x8M         2.54mm TH            Spare GPIO header 1×8               $0.10
J10      1     4P 5.08mm    KF301-4P             POWER: 5V/3V3/GND/GND               $0.25
R1       1     4.7kΩ        0805 SMD             I2C SDA pull-up to 3V3              $0.01
R2       1     4.7kΩ        0805 SMD             I2C SCL pull-up to 3V3              $0.01
R3       1     4.7kΩ        0805 SMD             OneWire pull-up to 3V3              $0.01
C1       1     100nF        0805 SMD             I2C bus decoupling                  $0.01
C2       1     100nF        0805 SMD             Power rail decoupling               $0.01
MH1-4    4     M2           2.2mm hole           Mounting holes                      —
------------------------------------------------------------------------------------------
TOTAL COMPONENTS: 15                          PCB + components ≈ $2-3 per board

NOTES:
  - PCB: 70×50mm, 2-layer, 1.6mm FR4, HASL finish
  - Screw terminals: KF301 or Phoenix MKDS-1.5 series (5.08mm pitch)
  - SMD passives: 0805 (hand-solderable)
  - J1 MUST be female header to plug onto J9 male pins on the GUITION board
  - VERIFY J9 power pin mapping (1,2,14,18,20,22,24,26) against your board!
    The assumed mapping (3V3/5V/GND) is based on typical convention.
    Measure with a multimeter before first power-on.

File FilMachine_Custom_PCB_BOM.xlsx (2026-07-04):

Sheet: BOM
# | Sezione | Componente | Valore / Part Number | Package | Qty | Descrizione | Note per il progettista
 | Connettori
1 | Connettori | JP1 Header maschio | 2x13 pin 2.54mm | THT | 1 | Connettore verso display JC4880P433 | Deve combaciare con il JP1 femmina del display. Pin-to-pin.
2 | Connettori | Morsettiera alimentazione 12V | 2 pos. 5.08mm | THT | 1 | Ingresso alimentazione 12V/30A | Sezione filo adeguata a 30A. Piste larghe verso fusibile.
3 | Connettori | Morsettiera motore | 2 pos. 5.08mm | THT | 1 | Uscita motore agitazione (Channel A) | Vicino ai BTS7960 del canale A.
4 | Connettori | Morsettiera pompa | 2 pos. 5.08mm | THT | 1 | Uscita pompa (Channel B) | Vicino ai BTS7960 del canale B.
5 | Connettori | Morsettiera solenoidi | 2 pos. 3.5mm | THT | 6 | Uscite valvole solenoide (C1,C2,C3,WB,WASTE + spare) | Un lato a 12V comune, l'altro al drain MOSFET.
6 | Connettori | Morsettiera riscaldatore | 2 pos. 5.08mm | THT | 1 | Uscita riscaldatore (100W @ 12V = 8.3A) | Attraverso relay 12V/10A. Piste adeguate.
7 | Connettori | Header DS18B20 | 3 pin 2.54mm (VCC/DATA/GND) | THT | 2 | Sensori temperatura OneWire | Pull-up 4.7kΩ su DATA vicino al connettore.
8 | Connettori | Header XKC-Y21 | 3 pin 2.54mm (VCC/SIG/GND) | THT | 2 | Sensori livello acqua (MIN + MAX) | Segnale 5V con partitore 3.3V se GPIO non è 5V-tolerant.
9 | Connettori | Header YF-S201 | 3 pin 2.54mm (VCC/SIG/GND) | THT | 1 | Flussometro acqua | Pull-up 10kΩ su segnale.
10 | Connettori | Header Hall KY-003 | 3 pin 2.54mm (VCC/SIG/GND) | THT | 1 | Sensore Hall rotazione tank | Pull-up 10kΩ su segnale.
 | Alimentazione
11 | Alimentazione | Fusibile 12V | 30A blade fuse + holder | THT | 1 | Protezione ingresso 12V | A monte di tutto. Accessibile dall'esterno.
12 | Alimentazione | Diodo protezione inversione | SS54 (5A Schottky) o P-MOSFET | SMD/THT | 1 | Protezione polarità invertita | P-MOSFET (es. FQP27P06) preferibile per minor caduta.
13 | Alimentazione | Buck converter 12V→5V | MP1584EN o LM2596 | SMD/THT | 1 | Alimentazione 5V per sensori (≥2A) | Condensatori I/O: 100µF elettrolitico + 100nF ceramico.
14 | Alimentazione | LDO 5V→3.3V | AMS1117-3.3 | SOT-223 | 1 | Alimentazione 3.3V per logica MCP23017 | Condensatori: 10µF in + 22µF out. Dissipazione ~1.7V×0.1A = ok.
15 | Alimentazione | Condensatore bulk 12V | 470µF 25V elettrolitico | THT | 2 | Stabilizzazione rail 12V | Uno vicino ingresso, uno vicino H-bridge.
16 | Alimentazione | Condensatore decoupling | 100nF ceramico | 0805 | 8 | Bypass su ogni IC e regolatore | Posizionare il più vicino possibile ai pin VDD.
 | I2C Expander
17 | I2C Expander | MCP23017 | MCP23017-E/SO | SOIC-28 | 1 | I2C GPIO expander 16 I/O (addr 0x20) | Port A = solenoidi, Port B = relay board. Addr: A0=A1=A2=GND.
18 | I2C Expander | Resistore addr A0 | 0Ω o solder bridge | 0805 | 3 | Address A0, A1, A2 → GND per 0x20 | Possibilità di cambiare indirizzo con jumper.
19 | I2C Expander | Pull-up I2C SDA | 4.7kΩ | 0805 | 1 | Pull-up bus I2C SDA | Uno solo per bus, condiviso con touch GT911 del display.
20 | I2C Expander | Pull-up I2C SCL | 4.7kΩ | 0805 | 1 | Pull-up bus I2C SCL | Verificare che il display non abbia già pull-up on-board.
21 | I2C Expander | Condensatore MCP23017 | 100nF | 0805 | 1 | Decoupling VDD MCP23017 | Pin 9 (VSS)→GND, Pin 10 (VDD)→3.3V.
22 | I2C Expander | Reset pull-up MCP23017 | 10kΩ | 0805 | 1 | Pull-up su RESET (pin 18) a VDD | Senza reset esterno, tenere RESET alto.
 | Driver solenoidi
23 | Driver solenoidi | MOSFET N-Ch solenoidi | AO3406 (30V, 3.6A) | SOT-23 | 6 | Switch low-side per valvole solenoide | Gate dal MCP23017 port A. Vgs_th ~1.4V, ok con 3.3V.
24 | Driver solenoidi | Diodo flyback solenoidi | SS14 (1A Schottky) | SMA | 6 | Protezione kick-back induttivo solenoidi | Catodo a 12V, anodo al drain MOSFET.
25 | Driver solenoidi | Resistore gate MOSFET | 100Ω | 0805 | 6 | Limitazione corrente gate | Tra MCP23017 output e gate MOSFET.
26 | Driver solenoidi | Resistore pull-down gate | 10kΩ | 0805 | 6 | Pull-down gate per stato definito | Gate→GND, evita attivazione spuria al boot.
27 | Driver solenoidi | LED indicatore solenoide | LED rosso 3mm | 0805 o THT | 6 | Indicazione visiva attivazione valvola | Con resistore 1kΩ in serie (12V / ~10mA).
28 | Driver solenoidi | Resistore LED solenoide | 1kΩ | 0805 | 6 | Limitazione corrente LED indicatore
 | H-Bridge motore
29 | H-Bridge motore | BTS7960 half-bridge | BTS7960B | TO-263-7 | 2 | Driver half-bridge 43A per motore agitazione | 2 IC = 1 full H-bridge. Serve heatsink / area rame.
30 | H-Bridge motore | Condensatore bootstrap | 100nF | 0805 | 2 | Bootstrap per BTS7960 high-side | Secondo datasheet BTS7960.
31 | H-Bridge motore | Condensatore potenza motore | 100µF 25V | THT | 1 | Decoupling locale rail 12V motore | Vicino ai BTS7960 canale A.
32 | H-Bridge motore | Connessione segnali motore | — | — | 3 | ENA(GPIO32), IN1(GPIO33), IN2(GPIO34) | Dal JP1 ai BTS7960 via resistore 100Ω sui gate.
 | H-Bridge pompa
33 | H-Bridge pompa | BTS7960 half-bridge | BTS7960B | TO-263-7 | 2 | Driver half-bridge 43A per pompa | Stessa configurazione del canale motore.
34 | H-Bridge pompa | Condensatore bootstrap | 100nF | 0805 | 2 | Bootstrap per BTS7960 high-side
35 | H-Bridge pompa | Condensatore potenza pompa | 100µF 25V | THT | 1 | Decoupling locale rail 12V pompa
36 | H-Bridge pompa | Connessione segnali pompa | — | — | 3 | ENA(GPIO51), IN1(GPIO49), IN2(GPIO50) | Dal JP1 ai BTS7960 via resistore 100Ω sui gate.
 | Relay riscaldatore
37 | Relay riscaldatore | Relay 12V/10A | SRD-12VDC-SL-C | THT | 1 | Relay per riscaldatore 100W (8.3A) | Contatto NO (normalmente aperto). 1 relay basta.
38 | Relay riscaldatore | Transistor driver relay | 2N2222A o BC337 | TO-92 | 1 | Driver relay da MCP23017 port B pin 8 | Base con resistore 1kΩ da MCP23017.
39 | Relay riscaldatore | Resistore base transistor | 1kΩ | 0805 | 1 | Limitazione corrente base driver relay | 3.3V / 1kΩ = 3.3mA → hFE×3.3mA >> I_bobina.
40 | Relay riscaldatore | Diodo flyback relay | 1N4148 o 1N4001 | THT/SMA | 1 | Protezione kick-back bobina relay | In parallelo alla bobina, catodo a 12V.
41 | Relay riscaldatore | LED indicatore relay | LED rosso 3mm | 0805 o THT | 1 | Indicazione visiva riscaldatore ON | Con resistore 1kΩ.
42 | Relay riscaldatore | Resistore LED relay | 1kΩ | 0805 | 1 | Limitazione corrente LED
 | Relay spare
43 | Relay spare | Relay 12V/10A | SRD-12VDC-SL-C | THT | 3 | Relay spare per espansioni future | Port B pin 9, 10, 11 del MCP23017.
44 | Relay spare | Transistor driver relay | 2N2222A o BC337 | TO-92 | 3 | Driver relay spare
45 | Relay spare | Resistore base transistor | 1kΩ | 0805 | 3 | Limitazione corrente base
46 | Relay spare | Diodo flyback relay | 1N4148 o 1N4001 | THT/SMA | 3 | Protezione kick-back bobina
47 | Relay spare | LED indicatore relay | LED rosso 3mm | 0805 o THT | 3 | Indicazione visiva relay ON
48 | Relay spare | Resistore LED relay | 1kΩ | 0805 | 3 | Limitazione corrente LED
49 | Relay spare | Morsettiera uscita spare | 2 pos. 5.08mm | THT | 3 | Uscite relay spare
 | Sensori temp.
50 | Sensori temp. | Resistore pull-up OneWire | 4.7kΩ | 0805 | 1 | Pull-up bus OneWire DS18B20 | Un solo pull-up per tutto il bus. Tra DATA e 3.3V.
51 | Sensori temp. | Condensatore filtro | 100nF | 0805 | 1 | Filtro rumore linea dati DS18B20 | Opzionale ma consigliato per cavi lunghi.
 | Sensori livello
52 | Sensori livello | Partitore 5V→3.3V (R_alto) | 10kΩ | 0805 | 2 | Partitore tensione uscita XKC-Y21 | Se GPIO ESP32-P4 non è 5V-tolerant. 10k+20k = 3.33V.
53 | Sensori livello | Partitore 5V→3.3V (R_basso) | 20kΩ | 0805 | 2 | Partitore tensione uscita XKC-Y21 | Verificare livello uscita XKC-Y21 effettivo.
 | Flussometro
54 | Flussometro | Resistore pull-up | 10kΩ | 0805 | 1 | Pull-up segnale YF-S201 | Uscita open-collector, pull-up a 3.3V.
 | Sensore Hall
55 | Sensore Hall | Resistore pull-up | 10kΩ | 0805 | 1 | Pull-up segnale Hall KY-003 | Uscita open-collector, pull-up a 3.3V.
 | Buzzer
56 | Buzzer | Buzzer attivo | 5V buzzer attivo | THT | 1 | Allarme acustico processo | Pilotato da GPIO libero o port B MCP23017 spare.
57 | Buzzer | Transistor driver buzzer | 2N2222A | TO-92 | 1 | Driver buzzer | Base con 1kΩ da GPIO/MCP23017.
58 | Buzzer | Resistore base buzzer | 1kΩ | 0805 | 1 | Limitazione corrente base
 | PCB
59 | PCB | PCB custom 2-layer | ~120×80mm (stimato) | — | 1 | PCB principale FilMachine | Min 2oz copper su layer potenza. 4-layer consigliato.
60 | PCB | Distanziali montaggio | M3 × 10mm | — | 4 | Montaggio PCB nel case | Con viti M3 e dadi.
61 | PCB | Heatsink BTS7960 | TO-263 heatsink | — | 4 | Dissipazione calore H-bridge | Oppure area rame esposta come heatsink.

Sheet: Pin Map JP1
JP1 Pin | GPIO | Funzione | Direzione | Destinazione | Note
1 | 3.3V | Alimentazione 3.3V | PWR | Logica MCP23017, sensori | Max ~500mA dal regolatore display
2 | GND | Ground | PWR | Comune
3 | 5V | Alimentazione 5V | PWR | Sensori 5V (XKC-Y21, YF-S201) | Dal regolatore display o buck esterno
4 | GND | Ground | PWR | Comune
7 | G52 | Flussometro | IN | YF-S201 pulse output | Pull-up 10kΩ a 3.3V
8 | G33 | Motor IN1 | OUT | BTS7960 Ch.A IN1 | Direzione motore A
9 | G51 | Pump ENA | OUT (PWM) | BTS7960 Ch.B ENA | LEDC Timer2/Ch2, 16kHz 8-bit
10 | G31 | Hall sensor | IN | KY-003/A3144 signal | Pull-up 10kΩ a 3.3V
11 | G50 | Pump IN2 | OUT | BTS7960 Ch.B IN2 | Direzione pompa B
12 | G30 | Water level MAX | IN | XKC-Y21 #2 signal | Partitore 5V→3.3V se necessario
13 | G49 | Pump IN1 | OUT | BTS7960 Ch.B IN1 | Direzione pompa A
14 | G29 | Water level MIN | IN | XKC-Y21 #1 signal | Partitore 5V→3.3V se necessario
15 | G35 | Temperatura DS18B20 | I/O | Bus OneWire (2 sensori) | Pull-up 4.7kΩ a 3.3V
17 | G34 | Motor IN2 | OUT | BTS7960 Ch.A IN2 | Direzione motore B
19 | G32 | Motor ENA | OUT (PWM) | BTS7960 Ch.A ENA | LEDC Timer0/Ch0, 5kHz 8-bit
21 | G28 | TEST / Spare | I/O | Disponibile | Unico GPIO libero su JP1
23 | G7 | I2C SDA | I/O | MCP23017 + GT911 touch | Pull-up 4.7kΩ (condiviso)
25 | G8 | I2C SCL | OUT | MCP23017 + GT911 touch | Pull-up 4.7kΩ (condiviso)

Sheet: MCP23017 Map
MCP Pin | Port | Funzione | Tipo carico | Corrente max | Note
0 | A0 | Libero (ex-heater) | — | — | Disponibile per espansione
1 | A1 | Valvola C1 | Solenoide via MOSFET | 3.6A max | AO3406 + SS14 flyback
2 | A2 | Valvola C2 | Solenoide via MOSFET | 3.6A max
3 | A3 | Valvola C3 | Solenoide via MOSFET | 3.6A max
4 | A4 | Valvola WB | Solenoide via MOSFET | 3.6A max
5 | A5 | Valvola WASTE | Solenoide via MOSFET | 3.6A max
6 | A6 | Spare solenoide | MOSFET disponibile | 3.6A max | Canale MOSFET pronto all'uso
7 | A7 | Spare solenoide | MOSFET disponibile | 3.6A max
8 | B0 | HEATER (Relay ch.1) | Relay 12V/10A | 10A | Riscaldatore 100W. Relay SRD-12VDC.
9 | B1 | Spare (Relay ch.2) | Relay 12V/10A | 10A | Disponibile per espansione
10 | B2 | Spare (Relay ch.3) | Relay 12V/10A | 10A
11 | B3 | Spare (Relay ch.4) | Relay 12V/10A | 10A
12 | B4 | Spare GPIO | — | 25mA | Port B pin 4-7: GPIO generico
13 | B5 | Spare GPIO | — | 25mA
14 | B6 | Spare GPIO | — | 25mA
15 | B7 | Spare GPIO | — | 25mA

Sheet: Power Budget
Componente | Rail | Corrente tipica | Corrente max | Note
Motore agitazione (BTS7960) | 12V | 2A | 10A | Dipende dal carico meccanico
Pompa (BTS7960) | 12V | 3A | 8A | Dipende dalla prevalenza
Riscaldatore 100W | 12V | 8.3A | 8.3A | Carico costante P=V×I
Valvole solenoidi ×6 | 12V | 3A (0.5A cad.) | 6A | Max tutte aperte contemporaneamente
Relay bobine ×4 | 12V | 0.3A (75mA cad.) | 0.3A | Bobina SRD-12VDC ~75mA
TOTALE 12V | 12V | ~16.6A | ~32.6A | PSU 30A adeguato
MCP23017 + logica | 3.3V | 5mA | 10mA | Consumo IC molto basso
Sensori DS18B20 ×2 | 3.3V | 2mA | 4mA | 1-2mA per sensore
Pull-up resistori | 3.3V | 3mA | 5mA | I2C + OneWire + GPIO
LED indicatori ×10 | 3.3V | 50mA | 100mA | ~10mA per LED
TOTALE 3.3V | 3.3V | ~60mA | ~120mA | AMS1117-3.3 (800mA) ok
Sensori XKC-Y21 ×2 | 5V | 30mA | 40mA | ~15mA per sensore
Flussometro YF-S201 | 5V | 15mA | 15mA
Hall sensor KY-003 | 5V | 5mA | 10mA
Buzzer | 5V | 30mA | 50mA
TOTALE 5V | 5V | ~80mA | ~115mA | Buck 2A abbondantemente ok

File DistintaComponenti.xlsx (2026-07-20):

Componenti | Specifiche | Quantità | Prezzo | Link | Note
Alimentatore 12V 30A |  | 1 | 28.18 | LINK (https://it.aliexpress.com/item/1005011601037869.html?curPageLogUid=nNqQZEym8CZ0) |  | Totale
Display | JC4880P443C | 1 | 25.59 | LINK (https://it.aliexpress.com/item/1005009621821443.html) |  | 438.11
Pompa | Marco UP3-R | 1 | 184.46 | LINK (https://www.magellanostore.it/up3-r-pompa-reversibile-con-interruttore-12v-P19588.htm?mid=19588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)
Elettrovalvola | DC 12V Normally Close | 5 | 7.59 | LINK (https://it.aliexpress.com/item/32642982184.html) | 3 per chimiche, 1 bagno, 1 scarto
Mosfet driver | IRF540 V4.0 | 1 | 5.9 | LINK (https://it.aliexpress.com/item/1005005137191326.html) | Per gestione riscaldatori da 100W 12V
Motor driver | DC5-12V 0A-30A Dual channel H bridge | 1 | 17.29 | LINK (https://it.aliexpress.com/item/1005007267434890.html) | Per gestione agitatore e pompa liquido
Solenoid Driver | MCP23017 GPIO | 1 | 13 | LINK (https://www.adafruit.com/product/6318) | Per gestione elettrovalvole (canale A) e gestione sensori livello e riscaldatori (canale B)
Speaker | Speaker 8ohm 2W | 1 | 1.69 | LINK (https://it.aliexpress.com/item/1005005699690954.html)
Motore agitatore | JGB37-520 12V 20RPM | 1 | 8.34 | LINK (https://it.aliexpress.com/item/1005003286346449.html) | Motore agitazione tank
Portafusibile 15A | Fusibile per riscaldatore | 2 | 5.5 | LINK (https://it.aliexpress.com/item/32813530925.html) | Per protezione sovracorrente riscaldatore
Riscaldatore | 100W 12V | 2 | 10.85 | LINK (https://it.aliexpress.com/item/1005003062546696.html)
Convertitore 12V / 5V | LM2596S | 1 | 4.29 | LINK (https://it.aliexpress.com/item/32785352477.html) | Per fornire una 5V all'occorrenza, e per avere una porta usb disponibile (no data)
Cavo Flat | Cavo flat grigio 2x13 20cm | 1 | 6.75 | LINK (https://it.aliexpress.com/item/1005004762590129.html) | Cavo per connessione display a breakout board con morsetti
Breakout board | DC3 26 p 2x13Pins | 1 | 10.34 | LINK (https://it.aliexpress.com/item/32911488121.html) | Board per esporre i pin del display con morsetti
Sensore hall | KY-003 A3144 | 1 | 4.83 | LINK (https://it.aliexpress.com/item/1005009558535002.html) | Sensore per detect del tank in posizione e rotazione
Sensore flusso | YF-S201 12V | 1 | 5.94 | LINK (https://it.aliexpress.com/item/32824326198.html) | Sensore flusso per detect del water inlet flow
Sensore livello | XKC-Y21 5V | 8 | 5.53 | LINK (https://it.aliexpress.com/item/1005005730406163.html) | Sensore livello min e max per il bagno (1x2) e per i contenitori delle chimiche (3x2)
Sensore temperatura | DS18B20 30mm 1m | 2 | 3.31 | LINK (https://it.aliexpress.com/item/1005005541143230.html) | Sensori di temperatura per check temperatura bagno e chimiche

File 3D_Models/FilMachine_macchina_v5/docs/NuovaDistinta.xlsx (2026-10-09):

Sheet: Da acquistare
FilMachine - nuova distinta: componenti da acquistare
Prezzi unitari in blu: stime indicative (ottobre 2026), da verificare all'acquisto. Controllati sul web solo: contenitore Euro RS PRO 400 x 300 x 170 = 26,13 € IVA inclusa (it.rs-online.com, codice 163-1899; altrove costa meno) e vaschette Araven GN 1/9 150 mm con coperchio, circa 7,50 € l'una (nisbets.com.au, codice T983, confezione da 4).
N. | Gruppo | Componente | Specifiche | Q.tà | Unità | Prezzo unitario indicativo (€) | Totale (€) | Dove si usa | Note
1 | Bagno e vaschette | Contenitore Euro 400 x 300 x 170 mm | polipropilene, pareti e fondo CHIUSI (non forato), maniglie chiuse; interno circa 365 x 265 x 165 | 1 | pz | 15.00 € | 15.00 € | bagno termostatico | regge 70 °C; vanno fatti due fori Ø16,5 per i riscaldatori
2 | Bagno e vaschette | Vaschetta Gastronorm GN 1/9, altezza 150 mm | 176 x 108 mm, 1,5 l, polipropilene, con coperchio | 3 | pz | 8.00 € | 24.00 € | chimiche C1, C2, C3 | il coperchio serve per conservare la chimica fuori dalla macchina
3 | Bagno e vaschette | Tubo quadro di alluminio 15 x 15 x 1,5 mm | barra da 1 m (servono due spezzoni da 356 mm) | 1 | pz | 5.00 € | 5.00 € | longheroni che reggono le vaschette
4 | Bagno e vaschette | Dado basso M16 inox + 2 guarnizioni piane in silicone 16 x 24 x 2 | una serie per riscaldatore | 2 | serie | 3.00 € | 6.00 € | passaggio dei riscaldatori nella parete del bagno | controllare il passo del filetto sul riscaldatore
5 | Bagno e vaschette | Termostato bimetallico KSD301 normalmente chiuso, 60 °C, 10 A |  | 2 | pz | 1.50 € | 3.00 € | sicurezza, in serie a ogni riscaldatore | i riscaldatori non devono mai lavorare a secco
6 | Bagno e vaschette | Nastro biadesivo per esterni (tipo VHB) 19 mm | rotolo corto | 1 | pz | 3.00 € | 3.00 € | sensori di livello XKC-Y21 sulla parete del bagno
7 | Idraulica | Tubo LLDPE 3/8" (9,52 x 6,35 mm) per osmosi inversa | rotolo da 10 m (ne servono circa 3) | 1 | pz | 8.00 € | 8.00 € | tutte le linee
8 | Idraulica | Gomito a innesto rapido 3/8" - 3/8" | per tubo da 9,52 mm | 10 | pz | 0.70 € | 7.00 € | 6 nelle tre testine, 1 sopra la valvola dello scarico, 1 ai piedi della salita verso la tank | 2 di scorta; meglio in polipropilene
9 | Idraulica | Gomito a codolo 3/8" (un lato a innesto, l'altro a codolo liscio da 9,52 mm) | in inglese "stem elbow" | 2 | pz | 1.50 € | 3.00 € | uscita del collettore (il codolo entra nella sede con O-ring) e raccordo destro della pompa | codolo lungo almeno 33 mm dall'angolo sul collettore; sulla pompa va accorciato a 27 mm
10 | Idraulica | Raccordo diritto: filetto maschio 3/8" BSP - tubo 3/8" a innesto |  | 2 | pz | 1.50 € | 3.00 € | attacchi della pompa | con nastro in PTFE
11 | Idraulica | Passaparete a innesto rapido 3/8" - 3/8" | foro Ø16 | 1 | pz | 2.00 € | 2.00 € | attacco SCARICO sulla staffa C09
12 | Idraulica | Raccordo a T 3/8" + rubinetto a sfera 3/8" a innesto |  | 1 | serie | 4.00 € | 4.00 € | scarico manuale del bagno | facoltativo
13 | Idraulica | Tubo in silicone 8 x 12 mm, NERO | 3 m | 1 | pz | 9.00 € | 9.00 € | tre sifoni, tubo della tank, troppopieno, tubi verso le taniche | nero: i due tubi che arrivano alla tank non devono far passare la luce
14 | Idraulica | O-ring 9 x 2 in EPDM |  | 10 | pz | 0.20 € | 2.00 € | sei sedi del collettore C07 | 4 di scorta
15 | Idraulica | Fascette in nylon 2,5 x 100 mm | confezione da 100 | 1 | conf | 3.00 € | 3.00 € | valvole, sifoni, testine, cavi
16 | Idraulica | Grasso al silicone per O-ring | tubetto | 1 | pz | 5.00 € | 5.00 € | O-ring, paraolio, baionetta della spirale
17 | Tank e caricatore | Albero in acciaio inox Ø8 x 61 mm | barra rettificata h6/h7, due spianature per i grani | 1 | pz | 4.00 € | 4.00 € | trasmissione della spirale
18 | Tank e caricatore | Cuscinetto 688-2RS (8 x 16 x 5) | meglio in acciaio inox | 2 | pz | 2.50 € | 5.00 € | cartuccia B17
19 | Tank e caricatore | Paraolio 8 x 16 x 5 | NBR | 1 | pz | 2.00 € | 2.00 € | tenuta dell'albero verso la vasca
20 | Tank e caricatore | Rondella inox M8 (8,4 x 16 x 1,6) |  | 1 | pz | 0.20 € | 0.20 € | reggispinta tra trascinatore e cartuccia
21 | Tank e caricatore | O-ring 24 x 2 |  | 1 | pz | 0.30 € | 0.30 € | tenuta della flangia della cartuccia
22 | Tank e caricatore | O-ring 80 x 3 in EPDM |  | 2 | pz | 1.00 € | 2.00 € | cinghia tonda tra motore e spirale | uno di scorta
23 | Tank e caricatore | Magneti al neodimio Ø6 x 3 | confezione da 10 (ne servono 4) | 1 | conf | 3.00 € | 3.00 € | ruota magneti del sensore Hall
24 | Tank e caricatore | Molla a compressione Ø6 x 22 mm, filo 0,5 |  | 1 | pz | 1.00 € | 1.00 € | perno folle a molla
25 | Tank e caricatore | Micro-servo MG90S | con squadretta a un braccio | 1 | pz | 4.00 € | 4.00 € | taglierina
26 | Tank e caricatore | Lame di ricambio per cutter da 9 mm | confezione da 10 | 1 | conf | 2.00 € | 2.00 € | due spezzoni da 36 mm nella taglierina
27 | Tank e caricatore | Velluto nero adesivo | striscia da 1 m | 1 | pz | 4.00 € | 4.00 € | guarnizione di luce su coperchio e fessura | facoltativo, da decidere dopo la prova di tenuta alla luce
28 | Elettrico | Presa IEC C14 da pannello con interruttore e portafusibile | foro 27,5 x 47,5 mm | 1 | pz | 4.00 € | 4.00 € | fianco sinistro del vano elettronica
29 | Elettrico | Cavo di alimentazione con spina e connettore IEC C13 |  | 1 | pz | 4.00 € | 4.00 €
30 | Elettrico | Modulo MOSFET 15 A (tipo D4184), ingresso 3,3-20 V |  | 2 | pz | 2.50 € | 5.00 € | riscaldatori (uscite B6 e B7) | al posto del modulo IRF540, che a 8,3 A scalda troppo
31 | Elettrico | Portafusibile a lama in linea con fusibile | uno da 10 A, uno da 5 A | 2 | pz | 1.50 € | 3.00 € | pompa; valvole e logica | consigliati
32 | Elettrico | Cavo unipolare 1,5 mm2 rosso e nero | 5 m + 5 m | 1 | serie | 8.00 € | 8.00 € | linee a 12 V di riscaldatori e pompa
33 | Elettrico | Cavetti per segnali, puntalini, connettori | assortimento | 1 | serie | 5.00 € | 5.00 € | sensori, valvole, servo
34 | Elettrico | Passacavo in gomma Ø22 |  | 4 | pz | 0.50 € | 2.00 € | paratia, fianco destro, cavalletto
35 | Elettrico | Resistenza 4,7 kohm |  | 1 | pz | 0.10 € | 0.10 € | pull-up del bus DS18B20 | se non e' gia' sulla scheda
36 | Elettrico | Tester per servo |  | 1 | pz | 3.00 € | 3.00 € | prova della taglierina senza firmware | facoltativo
37 | Struttura e viteria | Multistrato 420 x 505 x 12 mm | tagliato a misura | 1 | pz | 8.00 € | 8.00 € | base della macchina | verniciare o impregnare
38 | Struttura e viteria | Piedini in gomma Ø20 |  | 4 | pz | 0.50 € | 2.00 € | sotto la base
39 | Struttura e viteria | Viti autofilettanti per plastica 3 x 8 | testa cilindrica, confezione da 50 (ne servono 28) | 1 | conf | 4.00 € | 4.00 € | vedi foglio Viteria
40 | Struttura e viteria | Viti autofilettanti per plastica 3 x 10 | testa cilindrica, confezione da 100 (ne servono 30) | 1 | conf | 5.00 € | 5.00 € | vedi foglio Viteria
41 | Struttura e viteria | Viti autofilettanti per plastica 3 x 16 | testa cilindrica, confezione da 50 (ne servono 8) | 1 | conf | 4.00 € | 4.00 € | vedi foglio Viteria
42 | Struttura e viteria | Viti M3 x 16 con dado | 20 pezzi (ne servono 10) | 1 | conf | 3.00 € | 3.00 € | morsetti delle schede | M3 x 12 e' troppo corta: morsetto 8,7 mm + ripiano 3 mm + dado
43 | Struttura e viteria | Minuteria: 3 grani M3 x 6 con dado M3, 4 viti autofilettanti M2 x 6, 1 vite M2,5 x 8, 2 viti M3 x 8, 2 viti M3 x 10, 1 vite M3 x 5 | assortimento | 1 | serie | 4.00 € | 4.00 € | trascinatore, pulegge, morsetti lama, manovella, motoriduttore, perno folle, modulo Hall | una delle M3 x 10 fa da spinotto tra biella e portalama, al posto della spina Ø3 x 8
44 | Struttura e viteria | Viti per lamiera 2,9 x 9,5 (8 pezzi) e 2,9 x 13 (6 pezzi) | testa cilindrica; una confezione piccola per misura | 1 | serie | 3.00 € | 3.00 € | staffe, fermi e portasonde sui longheroni di alluminio | forare l'alluminio a 2,4 mm
45 | Struttura e viteria | Viti M4 x 12 | 4 pezzi | 1 | conf | 1.00 € | 1.00 € | testate del telaio sotto la fascia del contenitore
46 | Struttura e viteria | Viti da legno 3,5 x 12 a testa cilindrica (+ 4 da 3,5 x 20) | confezione da 50 | 1 | conf | 3.00 € | 3.00 € | tutti i pezzi fissati alla base (dima); le 4 lunghe per le colonnine | non piu' lunghe: la base e' spessa 12 mm
47 | Struttura e viteria | Barra filettata M3 x 130 mm con dadi e rondelle | 4 pezzi | 1 | serie | 3.00 € | 3.00 € | colonna dei tre ripiani a griglia
48 | Struttura e viteria | Filamento PETG, bobina da 1 kg |  | 2 | pz | 20.00 € | 40.00 € | tutti i pezzi stampati | stima: vedi foglio Pezzi stampati
 |  | TOTALE da acquistare |  |  |  |  | 243.60 €
 |  | Totale per gruppo
 |  | Bagno e vaschette |  |  |  |  | 56.00 €
 |  | Idraulica |  |  |  |  | 46.00 €
 |  | Tank e caricatore |  |  |  |  | 27.50 €
 |  | Elettrico |  |  |  |  | 34.10 €
 |  | Struttura e viteria |  |  |  |  | 80.00 €
 |  | di cui facoltativi (T e rubinetto, velluto, tester per servo) |  |  |  |  | 11.00 €

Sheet: Già acquistati
Componenti già acquistati (DistintaComponenti.xlsx) e loro uso in questa macchina
Quantità e prezzi sono quelli della distinta originale del progetto.
Componente | Specifiche | Q.tà | Prezzo unitario (€) | Totale (€) | Uso in questa macchina
Alimentatore 12V 30A |  | 1 | 28.18 € | 28.18 € | Usato: in piedi nello zoccolo D16, contro la paratia
Display | JC4880P443C | 1 | 25.59 € | 25.59 € | Usato: sulla plancia inclinata D09
Pompa | Marco UP3-R | 1 | 184.46 € | 184.46 € | Usata: sotto il cavalletto della tank. Tenerla a PWM basso e sciacquarla con acqua a fine lavoro (corpo in ottone nichelato)
Elettrovalvola | DC 12V Normally Close | 5 | 7.59 € | 37.95 € | Usate tutte, in fila sul collettore C07. Da sinistra: C1, WB, C2, C3, scarico (i collegamenti elettrici non cambiano)
Mosfet driver | IRF540 V4.0 | 1 | 5.90 € | 5.90 € | NON usato per i riscaldatori: a 8,3 A per canale scalda troppo. Tenerlo di scorta
Motor driver | DC5-12V 0A-30A Dual channel H bridge | 1 | 17.29 € | 17.29 € | Usato: canale A motore della spirale, canale B pompa
Solenoid Driver | MCP23017 GPIO | 1 | 13.00 € | 13.00 € | Usato: valvole su A0-A4, riscaldatori su B6-B7
Speaker | Speaker 8ohm 2W | 1 | 1.69 € | 1.69 € | Usato: dietro la griglia del fianco sinistro
Motore agitatore | JGB37-520 12V 20RPM | 1 | 8.34 € | 8.34 € | Usato: nella galleria sotto il ripiano della tank, con cinghia tonda
Portafusibile 15A | Fusibile per riscaldatore | 2 | 5.50 € | 11.00 € | Usati: uno per riscaldatore
Riscaldatore | 100W 12V | 2 | 10.85 € | 21.70 € | Usati: nella parete destra del bagno, vicino al fondo
Convertitore 12V / 5V | LM2596S | 1 | 4.29 € | 4.29 € | Usato: scheda display, sensori di livello, servo
Cavo Flat | Cavo flat grigio 2x13 20cm | 1 | 6.75 € | 6.75 € | Usato: dal display alla breakout
Breakout board | DC3 26 p 2x13Pins | 1 | 10.34 € | 10.34 € | Usata: sul secondo ripiano
Sensore hall | KY-003 A3144 | 1 | 4.83 € | 4.83 € | Usato: sulla staffa B25, davanti alla ruota magneti
Sensore flusso | YF-S201 12V | 1 | 5.94 € | 5.94 € | Non usato: serve solo con l'ingresso acqua in pressione
Sensore livello | XKC-Y21 5V | 8 | 5.53 € | 44.24 € | Usati 2 (MIN e MAX del bagno); gli altri 6 restano di scorta: sulle vaschette estraibili non servono
Sensore temperatura | DS18B20 30mm 1m | 2 | 3.31 € | 6.62 € | Usati: uno nel bagno (portasonde C06), uno nella vaschetta C1
TOTALE già speso |  |  |  | 438.11 €

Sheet: Pezzi stampati
Pezzi da stampare (file in stl/ e step/, già nell'orientamento di stampa)
Ipotesi per la stima del filamento (celle in blu, modificabili):
Densità PETG (g/cm3) | 1.27 | Quota di materiale rispetto al pieno (pareti + riempimento 25 %) | 0.5
Pezzo | Q.tà | Volume pieno (cm3) | Volume totale (cm3) | Ingombro X (mm) | Ingombro Y (mm) | Altezza di stampa Z (mm) | Note di stampa
A01_flangia_A | 1 | 11.6 | 11.6 | 93.5 | 93.5 | 8.0
A02_flangia_B | 1 | 11.5 | 11.5 | 93.5 | 93.5 | 8.0
A03_tubo_baionetta | 1 | 22.5 | 22.5 | 32.0 | 32.0 | 97.5
A04_tamburo | 1 | 14.3 | 14.3 | 44.0 | 44.0 | 23.0
A05_anello_alette | 2 | 13.6 | 27.2 | 91.8 | 91.8 | 14.8
A06_anello_alette_variante_B | 0 | 13.6 | 0.0 | 91.8 | 91.8 | 14.8 | facoltativo: alette concordi
A07_clip_ganascia | 1 | 0.9 | 0.9 | 18.4 | 4.4 | 18.0
A08_clip_cursore | 1 | 0.2 | 0.2 | 20.4 | 4.6 | 4.0
A09_provino_accoppiamento | 1 | 10.6 | 10.6 | 123.0 | 39.0 | 8.0 | da stampare per primo: sceglie il gioco della baionetta
B01_corpo_tank | 1 | 570.7 | 570.7 | 182.8 | 144.3 | 109.0 | in piedi, senza supporti
B02_coperchio_tank | 1 | 81.2 | 81.2 | 175.6 | 121.8 | 11.0 | capovolto
B03_coperchietto_vano_servo | 1 | 2.7 | 2.7 | 22.3 | 63.5 | 2.0
B04_blocco_ponte_DX | 1 | 12.2 | 12.2 | 42.0 | 36.1 | 52.0
B05_blocco_ponte_SX | 1 | 12.2 | 12.2 | 42.0 | 36.1 | 52.0
B06_tetto_ponte | 1 | 17.2 | 17.2 | 17.0 | 104.0 | 11.0 | capovolto
B07_portalama | 1 | 4.7 | 4.7 | 25.0 | 80.0 | 14.7
B08_morsetto_lama_DX | 1 | 0.9 | 0.9 | 17.7 | 35.2 | 2.9
B09_morsetto_lama_SX | 1 | 0.9 | 0.9 | 17.7 | 35.2 | 2.9
B10_biella | 1 | 0.5 | 0.5 | 7.0 | 35.0 | 3.0
B11_manovella | 1 | 0.1 | 0.1 | 7.2 | 12.6 | 3.0
B12_culla_universale | 1 | 39.4 | 39.4 | 32.0 | 72.0 | 35.5 | un solo pezzo per caricatore 135 e rullo 120
B13_barra_guida | 1 | 6.1 | 6.1 | 8.5 | 104.0 | 8.0
B14_slitta_DX | 1 | 2.5 | 2.5 | 73.0 | 13.7 | 18.5 | capovolta
B15_slitta_SX | 1 | 2.5 | 2.5 | 73.0 | 13.7 | 18.5 | capovolta
B16_trascinatore | 1 | 5.6 | 5.6 | 31.6 | 31.4 | 13.9
B17_cartuccia_cuscinetti | 1 | 8.3 | 8.3 | 42.0 | 42.0 | 24.5 | supporti solo sotto la flangia
B18_distanziale_paraolio | 1 | 0.4 | 0.4 | 15.8 | 15.8 | 3.7
B19_distanziale_cuscinetti | 1 | 0.6 | 0.6 | 15.8 | 15.8 | 5.0
B20_rasamento_puleggia | 1 | 0.0 | 0.0 | 10.8 | 10.8 | 1.0
B21_puleggia_spirale | 1 | 8.4 | 8.4 | 34.0 | 34.0 | 19.0
B22_puleggia_motore | 1 | 6.5 | 6.5 | 31.6 | 31.6 | 19.0
B23_piastra_motore | 1 | 8.4 | 8.4 | 53.5 | 47.0 | 4.0
B24_perno_folle | 1 | 5.1 | 5.1 | 30.0 | 30.0 | 22.0
B25_staffa_hall | 1 | 3.7 | 3.7 | 18.5 | 35.0 | 19.0
C01_sella_testina | 3 | 7.9 | 23.7 | 40.0 | 23.5 | 48.5 | in piedi sui due blocchetti
C02_culla_sifone | 3 | 26.6 | 79.8 | 67.6 | 41.8 | 22.0 | col davanti sul piatto: la gola ha il cielo a capanna
C03_staffa_ganci | 3 | 7.7 | 23.1 | 40.0 | 68.0 | 10.0 | PETG: i due bracci sono molle
C04_fermo_posteriore | 3 | 3.6 | 10.8 | 40.0 | 21.0 | 10.6
C05_testata_telaio_SX | 1 | 69.2 | 69.2 | 39.5 | 200.6 | 38.0 | capovolta
C05_testata_telaio_DX | 1 | 69.2 | 69.2 | 39.5 | 200.6 | 38.0 | capovolta
C06_portasonde | 1 | 7.1 | 7.1 | 19.0 | 49.0 | 30.0
C07_collettore | 1 | 80.2 | 80.2 | 190.0 | 34.5 | 22.0 | 4 perimetri, riempimento 100 %
C08_pettine_valvole | 1 | 60.1 | 60.1 | 178.0 | 100.0 | 9.1
C09_staffa_scarichi | 1 | 27.9 | 27.9 | 14.0 | 45.5 | 150.0
C10_carter_riscaldatori | 1 | 19.8 | 19.8 | 52.0 | 90.0 | 29.5
D01_piano_cavalletto | 1 | 189.5 | 189.5 | 204.0 | 189.0 | 23.5 | capovolto
D02_fianco_cavalletto_SX | 1 | 98.4 | 98.4 | 113.0 | 185.0 | 18.0
D03_fianco_cavalletto_DX | 1 | 103.8 | 103.8 | 113.0 | 185.0 | 18.0
D04_frontale_cavalletto | 1 | 34.9 | 34.9 | 202.0 | 53.0 | 4.0
D05_carter_trasmissione | 1 | 68.0 | 68.0 | 42.3 | 148.0 | 89.5 | capovolto
D06_fianco_elettronica_SX | 1 | 96.4 | 96.4 | 226.0 | 124.0 | 15.0
D07_fianco_elettronica_DX | 1 | 99.4 | 99.4 | 226.0 | 124.0 | 15.0
D08_frontale_elettronica | 1 | 87.6 | 87.6 | 190.0 | 163.0 | 3.0
D09_plancia_display | 1 | 33.4 | 33.4 | 189.4 | 84.9 | 6.2 | faccia esterna sul piatto
D10_tetto_elettronica | 1 | 29.1 | 29.1 | 190.0 | 58.0 | 3.0
D11_paratia_posteriore | 1 | 126.4 | 126.4 | 190.0 | 226.0 | 3.0
D12_ripiano_griglia | 3 | 28.4 | 85.2 | 180.0 | 58.0 | 3.0
D13_colonnina_bassa | 4 | 0.5 | 2.0 | 9.0 | 9.0 | 10.0
D14_colonnina_alta | 8 | 2.8 | 22.4 | 9.0 | 9.0 | 52.0
D15_morsetto_scheda | 10 | 1.3 | 13.0 | 15.5 | 8.7 | 12.0
D16_zoccolo_alimentatore | 1 | 28.9 | 28.9 | 132.0 | 63.2 | 34.0
D17_linguetta_display | 4 | 0.4 | 1.6 | 17.0 | 8.0 | 3.0 | tengono la scheda display: si possono ruotare
TOTALE | 94 |  | 2490.5
Filamento stimato (kg) |  |  | 1.6
Ingombro massimo sul piatto (mm) |  |  |  | 226.0 | 226.0 | 150.0

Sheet: Viteria
Viteria: dove va ogni vite
Le viti autofilettanti da 3 mm entrano nei fori Ø2,6 dei pezzi stampati; le lunghezze sono verificate sul modello (verifiche.txt, check_screws.py). Le quantità per tipo sono sommate a destra.
Tipo | Q.tà | Dove | Tipo | Totale
Vite autofilettante 3 x 10 | 4 | blocchi ponte sul ripiano della tank | Vite autofilettante 3 x 10 | 30
Vite autofilettante 3 x 16 | 4 | tetto del ponte | Vite autofilettante 3 x 16 | 8
Vite autofilettante 3 x 10 | 4 | culla universale | Vite M2 x 6 autofilettante | 4
Vite M2 x 6 autofilettante | 4 | morsetti delle lame | Vite M2 x 8 (del servo) | 2
Vite M2 x 8 (del servo) | 2 | alette del servo | Vite M2,5 x 8 | 1
Vite M2,5 x 8 | 1 | perno di manovella | Spina Ø3 x 8 (o vite M3 x 10) | 1
Spina Ø3 x 8 (o vite M3 x 10) | 1 | spinotto biella-portalama | Vite autofilettante 3 x 8 | 28
Vite autofilettante 3 x 8 | 2 | coperchietto del vano servo | Vite M3 x 8 | 2
Vite autofilettante 3 x 8 | 2 | flangia della cartuccia | Grano M3 x 6 + dado M3 | 3
Vite autofilettante 3 x 10 | 1 | flangia della cartuccia, nel punto che regge anche la staffa Hall | Vite M3 x 10 | 1
Vite autofilettante 3 x 10 | 3 | piastra del motore | Vite M3 x 5 (o una fascetta) | 1
Vite M3 x 8 | 2 | motoriduttore sulla piastra: nel riduttore entrano 4 mm; se i suoi fori sono meno profondi usare M3 x 6 | Vite per lamiera 2,9 x 9,5 | 8
Grano M3 x 6 + dado M3 | 3 | trascinatore e due pulegge | Vite per lamiera 2,9 x 13 | 6
Vite M3 x 10 | 1 | ritegno del perno folle | Vite M4 x 12 | 4
Vite M3 x 5 (o una fascetta) | 1 | modulo Hall sulla staffa B25: piu' lunga toccherebbe il carter | Vite da legno 3,5 x 12 | 32
Vite autofilettante 3 x 16 | 4 | piedini della tank sul cavalletto | Vite da legno 3,5 x 20 | 4
Vite per lamiera 2,9 x 9,5 | 6 | staffe con ganci C03 sul longherone anteriore | Barra filettata M3 x 130 + 2 dadi | 4
Vite autofilettante 3 x 10 | 6 | culle del sifone C02 sulle staffe C03, da dietro | Vite M3 x 16 + dado | 10
Vite per lamiera 2,9 x 13 | 6 | fermi posteriori C04 (spessi 7 mm) | Totale viti | 149
Vite per lamiera 2,9 x 9,5 | 2 | portasonde C06
Vite M4 x 12 | 4 | testate del telaio C05
Vite da legno 3,5 x 12 | 2 | collettore C07
Vite da legno 3,5 x 12 | 6 | pettine valvole C08
Vite da legno 3,5 x 12 | 2 | staffa scarichi C09
Vite da legno 3,5 x 12 | 2 | carter riscaldatori C10
Vite da legno 3,5 x 12 | 6 | fianchi del cavalletto
Vite da legno 3,5 x 12 | 4 | piede della pompa: scegliere la lunghezza secondo i piedini, senza passare la base da 12 mm
Vite autofilettante 3 x 10 | 6 | piano del cavalletto sui fianchi
Vite autofilettante 3 x 10 | 4 | frontale del cavalletto
Vite autofilettante 3 x 10 | 2 | carter della trasmissione
Vite da legno 3,5 x 12 | 6 | fianchi del vano elettronica
Vite autofilettante 3 x 8 | 6 | frontale del vano elettronica
Vite autofilettante 3 x 8 | 6 | paratia posteriore
Vite autofilettante 3 x 8 | 4 | tetto
Vite autofilettante 3 x 8 | 4 | plancia del display
Vite autofilettante 3 x 8 | 4 | linguette D17 che tengono la scheda display
Vite da legno 3,5 x 20 | 4 | colonnine basse (ripiano inferiore)
Vite da legno 3,5 x 12 | 4 | zoccolo dell'alimentatore
Barra filettata M3 x 130 + 2 dadi | 4 | colonna dei ripiani
Vite M3 x 16 + dado | 10 | morsetti delle schede

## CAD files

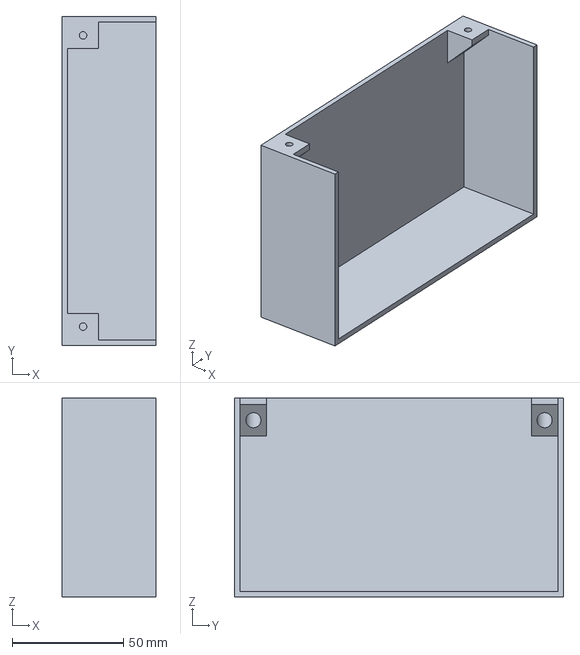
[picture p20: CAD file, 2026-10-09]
3D_Models/FilMachine_macchina_v5/step/D05_carter_trasmissione.step
42.4 x 148.0 x 89.5 mm

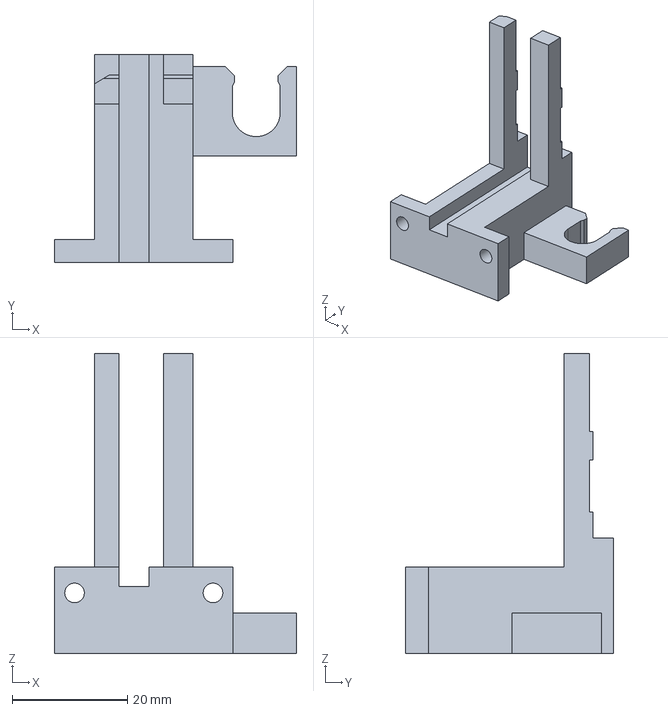
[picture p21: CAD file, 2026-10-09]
3D_Models/FilMachine_macchina_v5/step/B04_blocco_ponte_DX.step
42.0 x 36.1 x 52.0 mm

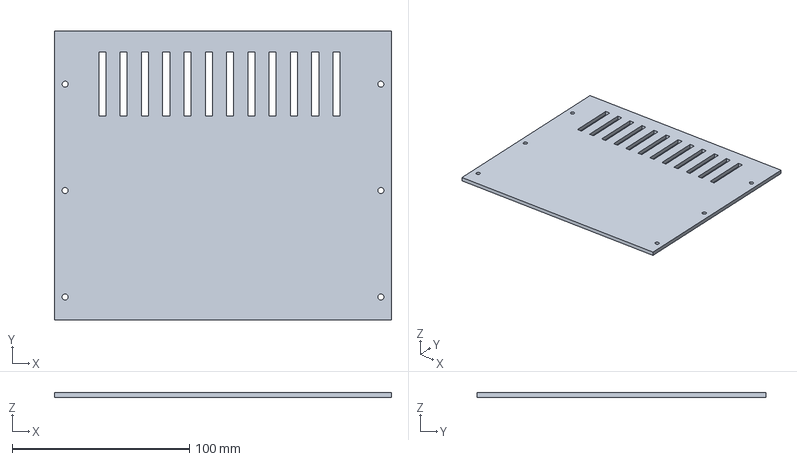
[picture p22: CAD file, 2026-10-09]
3D_Models/FilMachine_macchina_v5/step/D08_frontale_elettronica.step
190.0 x 163.0 x 3.00 mm

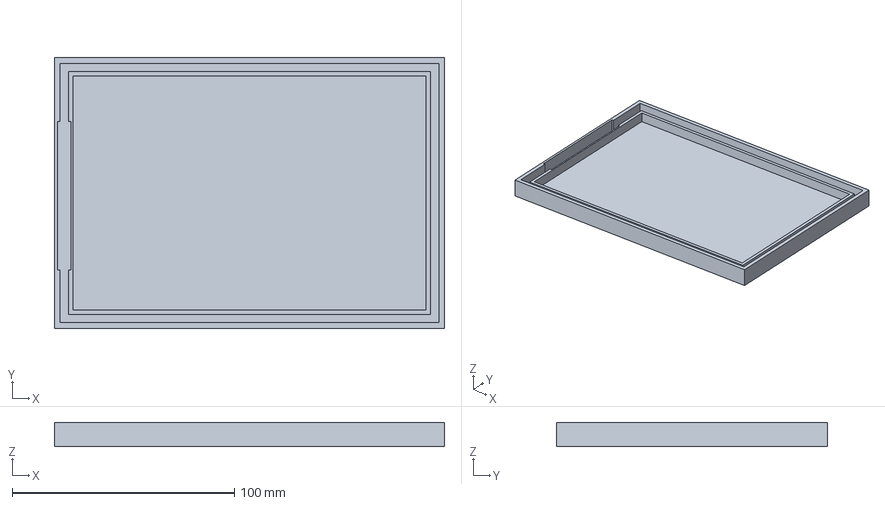
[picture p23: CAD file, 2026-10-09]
3D_Models/FilMachine_macchina_v5/step/B02_coperchio_tank.step
175.6 x 121.8 x 11.0 mm

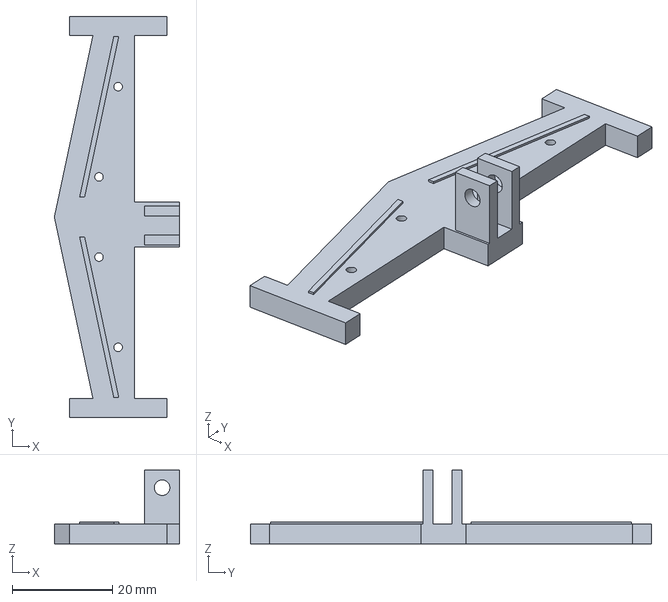
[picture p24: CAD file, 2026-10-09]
3D_Models/FilMachine_macchina_v5/step/B07_portalama.step
25.0 x 80.0 x 14.7 mm

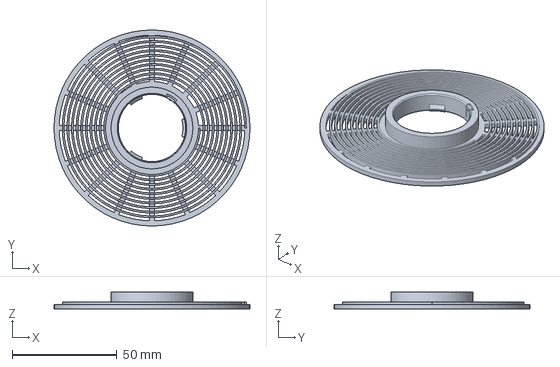
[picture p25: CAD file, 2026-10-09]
3D_Models/FilMachine_macchina_v5/step/A02_flangia_B.step
93.5 x 93.5 x 8.00 mm

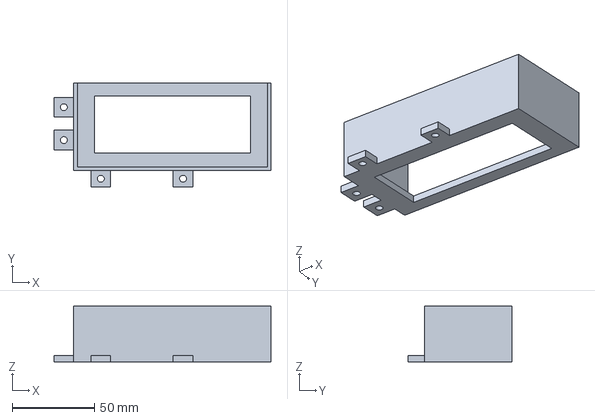
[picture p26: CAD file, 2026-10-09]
3D_Models/FilMachine_macchina_v5/step/D16_zoccolo_alimentatore.step
132.0 x 63.2 x 34.0 mm

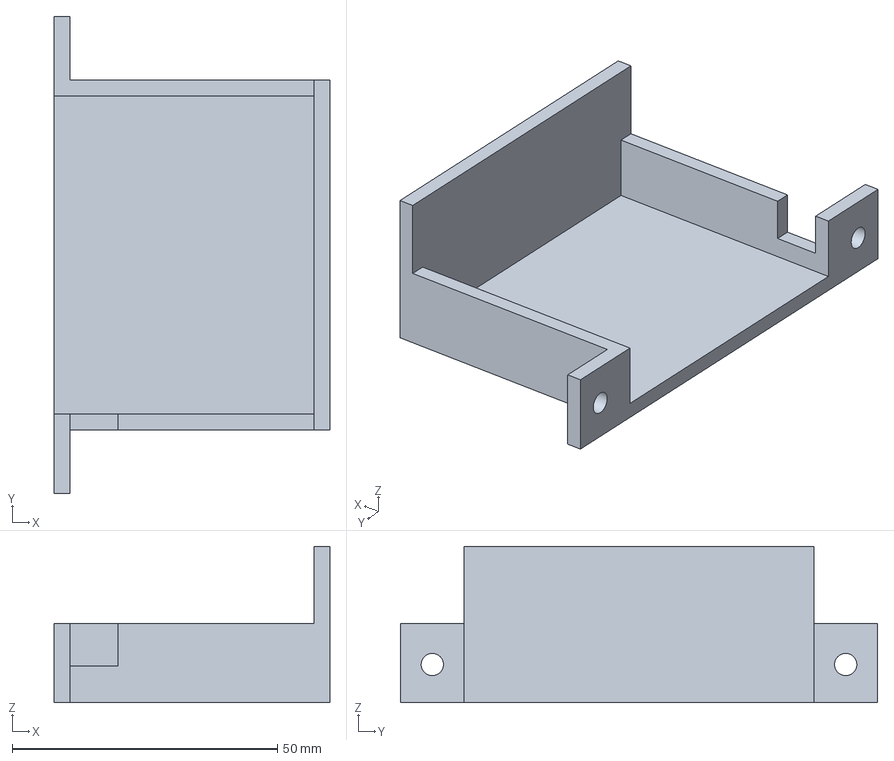
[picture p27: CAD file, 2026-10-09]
3D_Models/FilMachine_macchina_v5/step/C10_carter_riscaldatori.step
52.0 x 90.0 x 29.5 mm

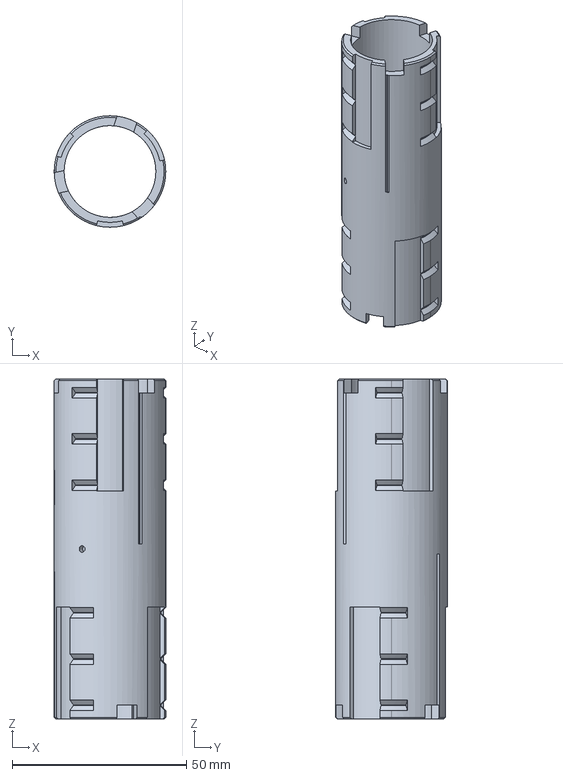
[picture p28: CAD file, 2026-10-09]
3D_Models/FilMachine_macchina_v5/step/A03_tubo_baionetta.step
32.0 x 32.0 x 97.5 mm

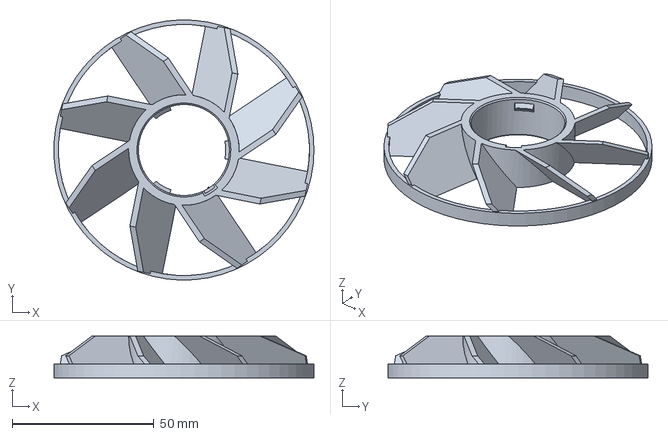
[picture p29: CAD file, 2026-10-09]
3D_Models/FilMachine_macchina_v5/step/A06_anello_alette_variante_B.step
91.7 x 91.8 x 14.8 mm

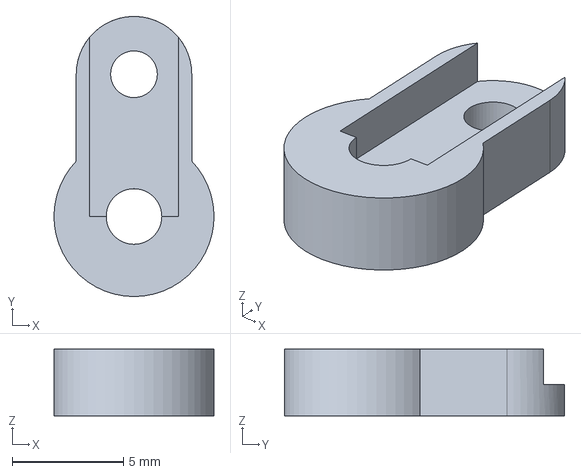
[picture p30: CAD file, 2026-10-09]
3D_Models/FilMachine_macchina_v5/step/B11_manovella.step
7.20 x 12.6 x 3.00 mm

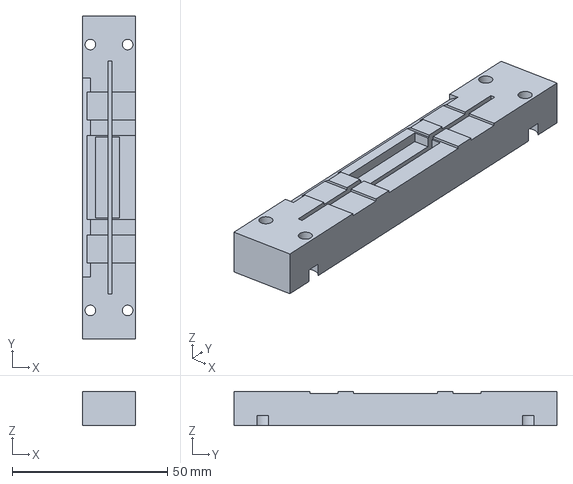
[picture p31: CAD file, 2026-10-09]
3D_Models/FilMachine_macchina_v5/step/B06_tetto_ponte.step
17.0 x 104.0 x 11.0 mm

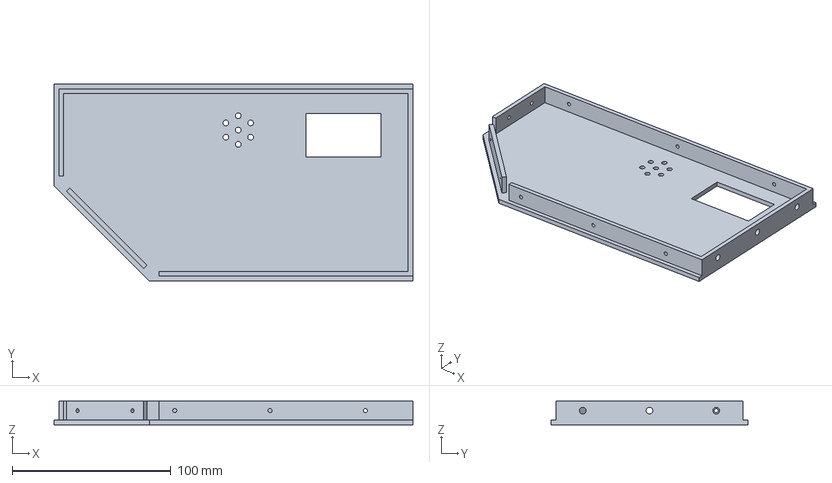
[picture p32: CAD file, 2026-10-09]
3D_Models/FilMachine_macchina_v5/step/D06_fianco_elettronica_SX.step
226.0 x 124.0 x 15.0 mm

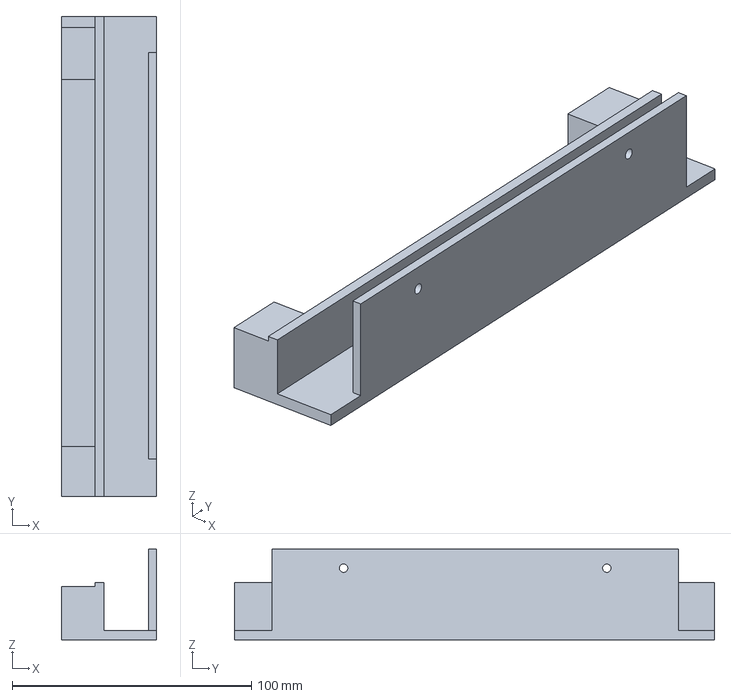
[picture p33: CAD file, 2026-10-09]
3D_Models/FilMachine_macchina_v5/step/C05_testata_telaio_DX.step
39.5 x 200.6 x 38.0 mm

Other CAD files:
3D_Models/FilMachine_macchina_v5/step/A05_anello_alette.step
3D_Models/FilMachine_macchina_v5/step/B01_corpo_tank.step
3D_Models/FilMachine_macchina_v5/step/A01_flangia_A.step
3D_Models/FilMachine_macchina_v5/step/D02_fianco_cavalletto_SX.step
3D_Models/FilMachine_macchina_v5/step/A04_tamburo.step
3D_Models/FilMachine_macchina_v5/step/A07_clip_ganascia.step
3D_Models/FilMachine_macchina_v5/step/A08_clip_cursore.step
3D_Models/FilMachine_macchina_v5/step/A09_provino_accoppiamento.step
3D_Models/FilMachine_macchina_v5/step/B03_coperchietto_vano_servo.step
3D_Models/FilMachine_macchina_v5/step/B05_blocco_ponte_SX.step
3D_Models/FilMachine_macchina_v5/step/B08_morsetto_lama_DX.step
3D_Models/FilMachine_macchina_v5/step/B09_morsetto_lama_SX.step
3D_Models/FilMachine_macchina_v5/step/B10_biella.step
3D_Models/FilMachine_macchina_v5/step/B12_culla_universale.step
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

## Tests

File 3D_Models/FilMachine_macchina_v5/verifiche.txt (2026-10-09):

== PEZZI DA STAMPARE (orientamento di stampa; ingombro in mm) ==
A01_flangia_A                    x1  solido ok  STL chiuso ( 12512 triangoli)    11.6 cm3    93.5 x   93.5 x   8.0
A02_flangia_B                    x1  solido ok  STL chiuso ( 12528 triangoli)    11.5 cm3    93.5 x   93.5 x   8.0
A03_tubo_baionetta               x1  solido ok  STL chiuso (  3200 triangoli)    22.5 cm3    32.0 x   32.0 x  97.5
A04_tamburo                      x1  solido ok  STL chiuso (  1828 triangoli)    14.3 cm3    44.0 x   44.0 x  23.0
A05_anello_alette                x2  solido ok  STL chiuso (  2406 triangoli)    13.6 cm3    91.8 x   91.8 x  14.8
A06_anello_alette_variante_B     x0  solido ok  STL chiuso (  2406 triangoli)    13.6 cm3    91.8 x   91.8 x  14.8
A07_clip_ganascia                x1  solido ok  STL chiuso (   372 triangoli)     0.9 cm3    18.4 x    4.4 x  18.0
A08_clip_cursore                 x1  solido ok  STL chiuso (    32 triangoli)     0.2 cm3    20.4 x    4.6 x   4.0
A09_provino_accoppiamento        x1  solido ok  STL chiuso (  3556 triangoli)    10.6 cm3   123.0 x   39.0 x   8.0
B01_corpo_tank                   x1  solido ok  STL chiuso ( 11578 triangoli)   570.7 cm3   182.8 x  144.3 x 109.0
B02_coperchio_tank               x1  solido ok  STL chiuso (    92 triangoli)    81.2 cm3   175.6 x  121.8 x  11.0
B03_coperchietto_vano_servo      x1  solido ok  STL chiuso (   708 triangoli)     2.7 cm3    22.3 x   63.5 x   2.0
B04_blocco_ponte_DX              x1  solido ok  STL chiuso (  1712 triangoli)    12.2 cm3    42.0 x   36.1 x  52.0
B05_blocco_ponte_SX              x1  solido ok  STL chiuso (  1712 triangoli)    12.2 cm3    42.0 x   36.1 x  52.0
B06_tetto_ponte                  x1  solido ok  STL chiuso (  2616 triangoli)    17.2 cm3    17.0 x  104.0 x  11.0
B07_portalama                    x1  solido ok  STL chiuso (  2168 triangoli)     4.7 cm3    25.0 x   80.0 x  14.7
B08_morsetto_lama_DX             x1  solido ok  STL chiuso (  1376 triangoli)     0.9 cm3    17.7 x   35.2 x   2.9
B09_morsetto_lama_SX             x1  solido ok  STL chiuso (  1376 triangoli)     0.9 cm3    17.7 x   35.2 x   2.9
B10_biella                       x1  solido ok  STL chiuso (   708 triangoli)     0.5 cm3     7.0 x   35.0 x   3.0
B11_manovella                    x1  solido ok  STL chiuso (  1124 triangoli)     0.1 cm3     7.2 x   12.6 x   3.0
B12_culla_universale             x1  solido ok  STL chiuso (  3628 triangoli)    39.4 cm3    32.0 x   72.0 x  35.5
B13_barra_guida                  x1  solido ok  STL chiuso (   844 triangoli)     6.1 cm3     8.5 x  104.0 x   8.0
B14_slitta_DX                    x1  solido ok  STL chiuso (   138 triangoli)     2.5 cm3    73.0 x   13.7 x  18.5
B15_slitta_SX                    x1  solido ok  STL chiuso (   138 triangoli)     2.5 cm3    73.0 x   13.7 x  18.5
B16_trascinatore                 x1  solido ok  STL chiuso (  2206 triangoli)     5.6 cm3    31.6 x   31.4 x  13.9
B17_cartuccia_cuscinetti         x1  solido ok  STL chiuso (  3372 triangoli)     8.3 cm3    42.0 x   42.0 x  24.5
B18_distanziale_paraolio         x1  solido ok  STL chiuso (   672 triangoli)     0.4 cm3    15.8 x   15.8 x   3.7
B19_distanziale_cuscinetti       x1  solido ok  STL chiuso (   672 triangoli)     0.6 cm3    15.8 x   15.8 x   5.0
B20_rasamento_puleggia           x1  solido ok  STL chiuso (   672 triangoli)     0.0 cm3    10.8 x   10.8 x   1.0
B21_puleggia_spirale             x1  solido ok  STL chiuso (  4210 triangoli)     8.4 cm3    34.0 x   34.0 x  19.0
B22_puleggia_motore              x1  solido ok  STL chiuso (  2398 triangoli)     6.5 cm3    31.6 x   31.6 x  19.0
B23_piastra_motore               x1  solido ok  STL chiuso (  3480 triangoli)     8.4 cm3    53.5 x   47.0 x   4.0
B24_perno_folle                  x1  solido ok  STL chiuso (  1472 triangoli)     5.1 cm3    30.0 x   30.0 x  22.0
B25_staffa_hall                  x1  solido ok  STL chiuso (   772 triangoli)     3.7 cm3    18.5 x   35.0 x  19.0
C01_sella_testina                x3  solido ok  STL chiuso (   812 triangoli)     7.9 cm3    40.0 x   23.5 x  48.5
C02_culla_sifone                 x3  solido ok  STL chiuso (  1554 triangoli)    26.6 cm3    67.6 x   41.8 x  22.0
C03_staffa_ganci                 x3  solido ok  STL chiuso (  2132 triangoli)     7.7 cm3    40.0 x   68.0 x  10.0
C04_fermo_posteriore             x3  solido ok  STL chiuso (   708 triangoli)     3.6 cm3    40.0 x   21.0 x  10.6
C05_testata_telaio_SX            x1  solido ok  STL chiuso (   780 triangoli)    69.2 cm3    39.5 x  200.6 x  38.0
C05_testata_telaio_DX            x1  solido ok  STL chiuso (   780 triangoli)    69.2 cm3    39.5 x  200.6 x  38.0
C06_portasonde                   x1  solido ok  STL chiuso (  1372 triangoli)     7.1 cm3    19.0 x   49.0 x  30.0
C07_collettore                   x1  solido ok  STL chiuso (  9554 triangoli)    80.2 cm3   190.0 x   34.5 x  22.0
C08_pettine_valvole              x1  solido ok  STL chiuso (  2268 triangoli)    60.1 cm3   178.0 x  100.0 x   9.1
C09_staffa_scarichi              x1  solido ok  STL chiuso (  1404 triangoli)    27.9 cm3    14.0 x   45.5 x 150.0
C10_carter_riscaldatori          x1  solido ok  STL chiuso (   744 triangoli)    19.8 cm3    52.0 x   90.0 x  29.5
D01_piano_cavalletto             x1  solido ok  STL chiuso (  7788 triangoli)   189.5 cm3   204.0 x  189.0 x  23.5
D02_fianco_cavalletto_SX         x1  solido ok  STL chiuso (  3800 triangoli)    98.4 cm3   113.0 x  185.0 x  18.0
D03_fianco_cavalletto_DX         x1  solido ok  STL chiuso (  2804 triangoli)   103.8 cm3   113.0 x  185.0 x  18.0
D04_frontale_cavalletto          x1  solido ok  STL chiuso (  1552 triangoli)    34.9 cm3   202.0 x   53.0 x   4.0
D05_carter_trasmissione          x1  solido ok  STL chiuso (  1504 triangoli)    68.0 cm3    42.3 x  148.0 x  89.5
D06_fianco_elettronica_SX        x1  solido ok  STL chiuso (  6892 triangoli)    96.4 cm3   226.0 x  124.0 x  15.0
D07_fianco_elettronica_DX        x1  solido ok  STL chiuso (  4832 triangoli)    99.4 cm3   226.0 x  124.0 x  15.0
D08_frontale_elettronica         x1  solido ok  STL chiuso (  2292 triangoli)    87.6 cm3   190.0 x  163.0 x   3.0
D09_plancia_display              x1  solido ok  STL chiuso (  4112 triangoli)    33.4 cm3   189.4 x   84.9 x   6.2
D10_tetto_elettronica            x1  solido ok  STL chiuso (  1552 triangoli)    29.1 cm3   190.0 x   58.0 x   3.0
D11_paratia_posteriore           x1  solido ok  STL chiuso (  2732 triangoli)   126.4 cm3   190.0 x  226.0 x   3.0
D12_ripiano_griglia              x3  solido ok  STL chiuso ( 36732 triangoli)    28.4 cm3   180.0 x   58.0 x   3.0
D13_colonnina_bassa              x4  solido ok  STL chiuso (   672 triangoli)     0.5 cm3     9.0 x    9.0 x  10.0
D14_colonnina_alta               x8  solido ok  STL chiuso (   672 triangoli)     2.8 cm3     9.0 x    9.0 x  52.0
D15_morsetto_scheda              x10 solido ok  STL chiuso (   376 triangoli)     1.3 cm3    15.5 x    8.7 x  12.0
D16_zoccolo_alimentatore         x1  solido ok  STL chiuso (  1472 triangoli)    28.9 cm3   132.0 x   63.2 x  34.0
D17_linguetta_display            x4  solido ok  STL chiuso (   352 triangoli)     0.4 cm3    17.0 x    8.0 x   3.0
totale: 62 pezzi diversi, 94 da stampare, 2490 cm3 di materiale pieno

== overhang.py ==
== sbalzi oltre 45 gradi (mm2): totale | di cui orizzontali (ponti o tetti) | quote ==
   B01_corpo_tank                       1414 |     1074 | z 6.8..85.2
   B17_cartuccia_cuscinetti             1113 |     1113 | z 14.0..23.7
   C05_testata_telaio_DX                 451 |      436 | z 19.3..31.8
   C05_testata_telaio_SX                 451 |      436 | z 19.3..31.8
   C07_collettore                        374 |      374 | z 16.6..16.6
   C01_sella_testina                     219 |      115 | z 6.8..13.6
   D01_piano_cavalletto                  148 |       25 | z 14.0..20.7
   B22_puleggia_motore                   114 |        1 | z 5.7..15.2
   B21_puleggia_spirale                  110 |        0 | z 5.7..17.2
   B14_slitta_DX                         107 |       85 | z 2.4..16.1
   B15_slitta_SX                         107 |       85 | z 2.4..16.1
   D02_fianco_cavalletto_SX               92 |        9 | z 9.0..13.1
   A03_tubo_baionetta                     92 |       87 | z 4.0..97.0
   C09_staffa_scarichi                    90 |        9 | z 100.5..144.2
   D06_fianco_elettronica_SX              87 |        9 | z 10.0..11.1
   D07_fianco_elettronica_DX              87 |        9 | z 10.0..11.1
   D15_morsetto_scheda                    83 |       63 | z 7.2..7.7
   B06_tetto_ponte                        78 |       78 | z 3.2..3.2
   D03_fianco_cavalletto_DX               77 |        8 | z 12.0..13.1
   B04_blocco_ponte_DX                    71 |       11 | z 10.2..33.5
   B05_blocco_ponte_SX                    71 |       11 | z 10.2..33.5
   C08_pettine_valvole                    68 |        7 | z 7.4..7.9
   B24_perno_folle                        67 |        4 | z 7.0..21.2
   D05_carter_trasmissione                55 |       55 | z 86.5..86.5
   B13_barra_guida                        44 |        0 | z 0.3..1.1
   C04_fermo_posteriore                   36 |        4 | z 5.9..6.4
   C06_portasonde                         20 |        2 | z 23.7..24.2
   B25_staffa_hall                        20 |       10 | z 3.0..11.2
   C10_carter_riscaldatori                19 |        2 | z 8.7..9.3
   A04_tamburo                            18 |        2 | z 12.2..20.2
   B08_morsetto_lama_DX                   18 |       18 | z 1.2..1.2
   B09_morsetto_lama_SX                   18 |       18 | z 1.2..1.2
   A02_flangia_B                           9 |        9 | z 0.4..0.4
   B07_portalama                           9 |        1 | z 12.3..12.8
   A01_flangia_A                           7 |        7 | z 0.4..0.4
   C02_culla_sifone                        7 |        7 | z 13.1..15.2
   B16_trascinatore                        5 |        1 | z 3.9..12.6
   pezzi senza sbalzi: 25 su 62

== check_reel.py ==
denti: 3 a (0.0, 120.0, 240.0) gradi, chiave 32 gradi (canale 36), gli altri 24 (canale 28)
flangia A: infilaggio lungo il canale (a -30 gradi), interferenza mm3: [0.0, 0.0, 0.0, 0.0, 0.0]
   stazione 120: rotazione di blocco -30..0: [0.0, 0.0, 0.0, 0.0, 0.0] | oltre la battuta (+3 gradi): 3.9703 | sfilamento assiale a blocco inserito (+/-1 mm): 22.3432 22.3432
   stazione 135: rotazione di blocco -30..0: [0.0, 0.0, 0.0, 0.0, 0.0] | oltre la battuta (+3 gradi): 3.9703 | sfilamento assiale a blocco inserito (+/-1 mm): 22.6443 22.3432
   rotazione a meta' canale (fuori stazione): 21.5057 (deve interferire)
   anti-errore: imbocco con la flangia sfasata di 120 e 240 gradi: [1.9646, 1.9646] (deve interferire)
   verso sbagliato: dal canale ruotando al contrario (-60 gradi) in stazione 135: 41.0803 (deve interferire)
flangia B: infilaggio lungo il canale (a +30 gradi), interferenza mm3: [0.0, 0.0, 0.0, 0.0, 0.0]
   stazione 120: rotazione di blocco +30..0: [0.0, 0.0, 0.0, 0.0, 0.0] | oltre la battuta (-3 gradi): 3.9703 | sfilamento assiale a blocco inserito (+/-1 mm): 22.3432 22.3432
   stazione 135: rotazione di blocco +30..0: [0.0, 0.0, 0.0, 0.0, 0.0] | oltre la battuta (-3 gradi): 3.9703 | sfilamento assiale a blocco inserito (+/-1 mm): 22.6443 22.3432
   rotazione a meta' canale (fuori stazione): 21.5057 (deve interferire)
   anti-errore: imbocco con la flangia sfasata di 120 e 240 gradi: [1.9646, 1.9646] (deve interferire)
   verso sbagliato: dal canale ruotando al contrario (+60 gradi) in stazione 135: 41.0803 (deve interferire)
versi di blocco: A ruota di +30 gradi, B di -30 gradi (visti dallo stesso lato) -> opposti
spirali A e B in fase: volume costola A 1694.8 mm3, differenza con B specchiata 0.000 mm3
scatto: il dentino sporge 0.40 mm nel tubo (linguetta flessa di 0.34 mm fuori dalla gola); volume di riferimento 0.207 mm3
   flange lato A: lungo l'infilaggio il dentino trova sempre tubo pieno (mancante mm3): [0.0, 0.0, 0.0, 0.0, 0.0, 0.0] | a meta' rotazione preme [0.207, 0.207] | a blocco inserito interferenza [0.0, 0.0] (0 = nella gola)
   flange lato B: lungo l'infilaggio il dentino trova sempre tubo pieno (mancante mm3): [0.0, 0.0, 0.0, 0.0, 0.0, 0.0] | a meta' rotazione preme [0.207, 0.207] | a blocco inserito interferenza [0.0, 0.0] (0 = nella gola)
   ring   lato A: lungo l'infilaggio il dentino trova sempre tubo pieno (mancante mm3): [0.0, 0.0257, 0.0, 0.0, 0.0, 0.0] | a meta' rotazione preme [0.207, 0.207] | a blocco inserito interferenza [0.0, 0.0] (0 = nella gola)
   ring   lato B: lungo l'infilaggio il dentino trova sempre tubo pieno (mancante mm3): [0.0, 0.0257, 0.0, 0.0, 0.0, 0.0] | a meta' rotazione preme [0.207, 0.207] | a blocco inserito interferenza [0.0, 0.0] (0 = nella gola)
anello alette lato A, stazione per il 135 (|z|=31.55): infilaggio [0.0, 0.0, 0.0] | rotazione [0.0, 0.0, 0.0] | oltre battuta 2.6469 | sfilamento 21.1673 21.1673
anello alette lato A, stazione per il 120 (|z|=44.80): infilaggio [0.0, 0.0, 0.0] | rotazione [0.0, 0.0, 0.0] | oltre battuta 2.6469 | sfilamento 21.1673 21.1673
anello alette lato B, stazione per il 135 (|z|=31.55): infilaggio [0.0, 0.0, 0.0] | rotazione [0.0, 0.0, 0.0] | oltre battuta 2.6469 | sfilamento 21.1673 21.1673
anello alette lato B, stazione per il 120 (|z|=44.80): infilaggio [0.0, 0.0, 0.0] | rotazione [0.0, 0.0, 0.0] | oltre battuta 2.6469 | sfilamento 21.1673 21.1673
spirale 135 montata: interferenze nessuna; gioco flangia/tubo 0.042 mm
   135 alette, stesso anello A sui due lati: interferenze con la spirale nessuna, gioco dalla flangia 0.4 mm
      rotazione orario (avvolgimento) : lato A spinge DENTRO, lato B spinge FUORI
      rotazione antiorario            : lato A spinge FUORI, lato B spinge DENTRO
   135 alette, anelli speculari A + B: interferenze con la spirale nessuna, gioco dalla flangia 0.4 mm
      rotazione orario (avvolgimento) : lato A spinge DENTRO, lato B spinge DENTRO
      rotazione antiorario            : lato A spinge FUORI, lato B spinge FUORI
spirale 120 montata: interferenze nessuna; gioco flangia/tubo 0.042 mm
   120 alette, stesso anello A sui due lati: interferenze con la spirale nessuna, gioco dalla flangia 0.4 mm
   120 alette, anelli speculari A + B: interferenze con la spirale nessuna, gioco dalla flangia 0.4 mm

== check_tank.py ==
== taglierina a Λ ==
manovella   0 gradi: alzata  0.00 mm, interferenze con parti fisse 0.0000 mm3, biella+manovella/servo 0.0000 mm3
manovella  45 gradi: alzata  1.52 mm, interferenze con parti fisse 0.0000 mm3, biella+manovella/servo 0.0000 mm3
manovella  90 gradi: alzata  5.68 mm, interferenze con parti fisse 0.0000 mm3, biella+manovella/servo 0.0000 mm3
manovella 135 gradi: alzata 10.57 mm, interferenze con parti fisse 0.0000 mm3, biella+manovella/servo 0.0000 mm3
manovella 180 gradi: alzata 12.80 mm, interferenze con parti fisse 0.0000 mm3, biella+manovella/servo 0.0000 mm3
a riposo la punta sta a z=79.0: 2.0 mm sotto il piano della fessura (z=81.0); a fine corsa punta a 91.8
   135: ai bordi della pellicola il filo arriva a z=88.08, 3.48 mm sopra il cielo della fessura (z=84.6)
   120: ai bordi della pellicola il filo arriva a z=85.26, 0.66 mm sopra il cielo della fessura (z=84.6)
   forza disponibile sul portalama a meta' corsa con un MG90S (1.8 kg*cm): circa 28 N
== guida a due slitte ==
135 raggio 22.0 (inclinazione  -8.5 gradi): interferenze spirale 0.0000, parti fisse+coperchio 0.0000, portalama alzato 0.0000 mm3; gioco slitte/flange 0.20, slitte/coperchio 16.60 mm
135 raggio 30.0 (inclinazione  -0.1 gradi): interferenze spirale 0.0000, parti fisse+coperchio 0.0000, portalama alzato 0.0000 mm3; gioco slitte/flange 0.20, slitte/coperchio 17.49 mm
135 raggio 42.0 (inclinazione +13.8 gradi): interferenze spirale 0.0000, parti fisse+coperchio 0.0000, portalama alzato 0.0000 mm3; gioco slitte/flange 0.20, slitte/coperchio 2.15 mm
120 raggio 22.0 (inclinazione  -8.5 gradi): interferenze spirale 0.0000, parti fisse+coperchio 0.0000, portalama alzato 0.0000 mm3; gioco slitte/flange 0.20, slitte/coperchio 14.76 mm
120 raggio 30.0 (inclinazione  -0.1 gradi): interferenze spirale 0.0000, parti fisse+coperchio 0.0000, portalama alzato 0.0000 mm3; gioco slitte/flange 0.20, slitte/coperchio 15.36 mm
120 raggio 42.0 (inclinazione +13.8 gradi): interferenze spirale 0.0000, parti fisse+coperchio 0.0000, portalama alzato 0.0000 mm3; gioco slitte/flange 0.20, slitte/coperchio 2.15 mm
punto di tangenza della suola sulla spirale: s = 56.0 mm (vuota), 45.7 mm (piena); la slitta e' lunga 66 mm
135: guida ribaltata all'indietro: libera fino a 90 gradi (poi appoggia sul ponte)
120: guida ribaltata all'indietro: libera fino a 90 gradi (poi appoggia sul ponte)
== montaggio della spirale ==
135: in sede interferenze 0.0000 mm3; arretrata di 5.5 mm contro la molla: spirale/corpo+trascinatore+perno 0.0000, perno/corpo 0.0000; sollevata di 30 mm: 0.0000 mm3
120: in sede interferenze 0.0000 mm3; arretrata di 5.5 mm contro la molla: spirale/corpo+trascinatore+perno 0.0000, perno/corpo 0.0000; sollevata di 30 mm: 0.0000 mm3
   gioco minimo spirale/vasca: 2.11 mm (120), 2.11 mm (135)
== liquido nella vasca ==
135: livello all'asse (z=50) = 397 ml; alla soglia del troppopieno (z=62) = 503 ml; per bagnare il giro piu' interno (z=28) = 199 ml  (pellicola, da togliere: fino a 8 ml)
   livello raggiunto da 250 / 350 / 500 / 550 ml: [34, 46, 62, None] mm dal fondo; asse albero a 50, sommita' del divisorio a 66
120: livello all'asse (z=50) = 397 ml; alla soglia del troppopieno (z=62) = 503 ml; per bagnare il giro piu' interno (z=28) = 199 ml  (pellicola, da togliere: fino a 6 ml)
   livello raggiunto da 250 / 350 / 500 / 550 ml: [34, 46, 62, None] mm dal fondo; asse albero a 50, sommita' del divisorio a 66
volume della canaletta e del pescante (resta bagnato): 3.7 ml

== check_bath.py ==
== inserimento della vaschetta: rotazione attorno al bordo posteriore (davanti in alto) ==
C1 inclinata 0.0 gradi (bordo anteriore + 0.0 mm): interferenze    0.00 mm3  | con i ganci a scatto    0.0 mm3
C1 inclinata 1.0 gradi (bordo anteriore + 3.1 mm): interferenze    0.00 mm3  | con i ganci a scatto  134.7 mm3
C1 inclinata 2.0 gradi (bordo anteriore + 6.1 mm): interferenze    0.00 mm3  | con i ganci a scatto   20.1 mm3
C1 inclinata 3.0 gradi (bordo anteriore + 9.2 mm): interferenze    0.00 mm3  | con i ganci a scatto    0.0 mm3
C1 inclinata 4.0 gradi (bordo anteriore +12.3 mm): interferenze    0.00 mm3  | con i ganci a scatto    0.0 mm3
C1 inclinata 5.0 gradi (bordo anteriore +15.3 mm): interferenze    0.00 mm3  | con i ganci a scatto    0.0 mm3
C1 inclinata 6.0 gradi (bordo anteriore +18.4 mm): interferenze    0.00 mm3  | con i ganci a scatto    0.0 mm3
C1 inclinata 8.0 gradi (bordo anteriore +24.5 mm): interferenze    0.04 mm3 ('REF_vaschetta_GN1-9_C1 / C04_fermo_posteriore_C1', 0.04) | con i ganci a scatto    0.0 mm3
   C1 estratta: 4.5 gradi, avanti 1.5 mm, su 0 mm -> interferenze 0.00 mm3 
   C1 estratta: 4.5 gradi, avanti 3.5 mm, su 0 mm -> interferenze 0.00 mm3 
   C1 estratta: 3.0 gradi, avanti 3.5 mm, su 12 mm -> interferenze 0.00 mm3 
   C1 estratta: 0.0 gradi, avanti 3.5 mm, su 30 mm -> interferenze 0.00 mm3 
   C1 estratta: 0.0 gradi, avanti 3.5 mm, su 100 mm -> interferenze 0.00 mm3 
   C1 estratta: 0.0 gradi, avanti 3.5 mm, su 200 mm -> interferenze 0.00 mm3 
C2 inclinata 0.0 gradi (bordo anteriore + 0.0 mm): interferenze    0.00 mm3  | con i ganci a scatto    0.0 mm3
C2 inclinata 1.0 gradi (bordo anteriore + 3.1 mm): interferenze    0.00 mm3  | con i ganci a scatto  134.7 mm3
C2 inclinata 2.0 gradi (bordo anteriore + 6.1 mm): interferenze    0.00 mm3  | con i ganci a scatto   20.1 mm3
C2 inclinata 3.0 gradi (bordo anteriore + 9.2 mm): interferenze    0.00 mm3  | con i ganci a scatto    0.0 mm3
C2 inclinata 4.0 gradi (bordo anteriore +12.3 mm): interferenze    0.00 mm3  | con i ganci a scatto    0.0 mm3
C2 inclinata 5.0 gradi (bordo anteriore +15.3 mm): interferenze    0.00 mm3  | con i ganci a scatto    0.0 mm3
C2 inclinata 6.0 gradi (bordo anteriore +18.4 mm): interferenze    0.00 mm3  | con i ganci a scatto    0.0 mm3
C2 inclinata 8.0 gradi (bordo anteriore +24.5 mm): interferenze    0.04 mm3 ('REF_vaschetta_GN1-9_C2 / C04_fermo_posteriore_C2', 0.04) | con i ganci a scatto    0.0 mm3
   C2 estratta: 4.5 gradi, avanti 1.5 mm, su 0 mm -> interferenze 0.00 mm3 
   C2 estratta: 4.5 gradi, avanti 3.5 mm, su 0 mm -> interferenze 0.00 mm3 
   C2 estratta: 3.0 gradi, avanti 3.5 mm, su 12 mm -> interferenze 0.00 mm3 
   C2 estratta: 0.0 gradi, avanti 3.5 mm, su 30 mm -> interferenze 0.00 mm3 
   C2 estratta: 0.0 gradi, avanti 3.5 mm, su 100 mm -> interferenze 0.00 mm3 
   C2 estratta: 0.0 gradi, avanti 3.5 mm, su 200 mm -> interferenze 0.00 mm3 
C3 inclinata 0.0 gradi (bordo anteriore + 0.0 mm): interferenze    0.00 mm3  | con i ganci a scatto    0.0 mm3
C3 inclinata 1.0 gradi (bordo anteriore + 3.1 mm): interferenze    0.00 mm3  | con i ganci a scatto  134.7 mm3
C3 inclinata 2.0 gradi (bordo anteriore + 6.1 mm): interferenze    0.00 mm3  | con i ganci a scatto   20.1 mm3
C3 inclinata 3.0 gradi (bordo anteriore + 9.2 mm): interferenze    0.00 mm3  | con i ganci a scatto    0.0 mm3
C3 inclinata 4.0 gradi (bordo anteriore +12.3 mm): interferenze    0.00 mm3  | con i ganci a scatto    0.0 mm3
C3 inclinata 5.0 gradi (bordo anteriore +15.3 mm): interferenze    0.00 mm3  | con i ganci a scatto    0.0 mm3
C3 inclinata 6.0 gradi (bordo anteriore +18.4 mm): interferenze    0.00 mm3  | con i ganci a scatto    0.0 mm3
C3 inclinata 8.0 gradi (bordo anteriore +24.5 mm): interferenze    0.04 mm3 ('REF_vaschetta_GN1-9_C3 / C04_fermo_posteriore_C3', 0.04) | con i ganci a scatto    0.0 mm3
   C3 estratta: 4.5 gradi, avanti 1.5 mm, su 0 mm -> interferenze 0.00 mm3 
   C3 estratta: 4.5 gradi, avanti 3.5 mm, su 0 mm -> interferenze 0.00 mm3 
   C3 estratta: 3.0 gradi, avanti 3.5 mm, su 12 mm -> interferenze 0.00 mm3 
   C3 estratta: 0.0 gradi, avanti 3.5 mm, su 30 mm -> interferenze 0.00 mm3 
   C3 estratta: 0.0 gradi, avanti 3.5 mm, su 100 mm -> interferenze 0.00 mm3 
   C3 estratta: 0.0 gradi, avanti 3.5 mm, su 200 mm -> interferenze 0.00 mm3 
== volumi e livelli ==
vaschetta GN 1/9 h150: capacita' al bordo 1.60 l; 1 litro arriva a 98 mm dal fondo (quota Z = 120, 52 mm sotto il bordo)
bagno: livello di lavoro Z = 113 (vaschette immerse per 90 mm) -> 7.4 l d'acqua; senza vaschette la stessa acqua arriva a Z = 82
   ogni litro prelevato per i risciacqui abbassa il livello di 16.6 mm
   riserva per i risciacqui tra livello di lavoro e sensore MIN (Z = 62): 3.2 l = 9 riempimenti da 350 ml (13 da 250 ml)
   sensore MAX a Z = 120: 7.8 l; bordo del contenitore a Z = 170
   sommita' dei riscaldatori Z = 31; bocca del pescante WB Z = 42: la pompa non puo' scoprire i riscaldatori (restano 3.0 l); sensore MIN 31 mm sopra i riscaldatori
   riscaldamento da 20 a 38 gradi di 10.4 kg (acqua + 3 l di chimica) con 200 W, senza perdite: 65 minuti
   riscaldamento da 33 a 38 gradi di 10.4 kg (acqua + 3 l di chimica) con 200 W, senza perdite: 18 minuti
== galleggiamento ==
vaschetta vuota in polipropilene: peso 1.2 N, spinta 9.7 N -> 8.5 N verso l'alto, divisi tra labbro posteriore e due ganci a scatto
vaschetta vuota in policarbonato: peso 1.6 N, spinta 9.7 N -> 8.1 N verso l'alto, divisi tra labbro posteriore e due ganci a scatto
ganci a scatto: braccio 36 x 7 x 2.5 mm, rigidezza 1.14 N/mm; per sganciare servono 4.2 mm = 4.8 N per braccio, deformazione 1.2 % (limite prudente per il PETG: 2 %)
   con la vaschetta vuota ogni dente porta circa 2.1 N: il braccio si apre di 0.26 mm su 4.2 di presa
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

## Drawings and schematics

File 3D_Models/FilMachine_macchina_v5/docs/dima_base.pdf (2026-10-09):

400

450

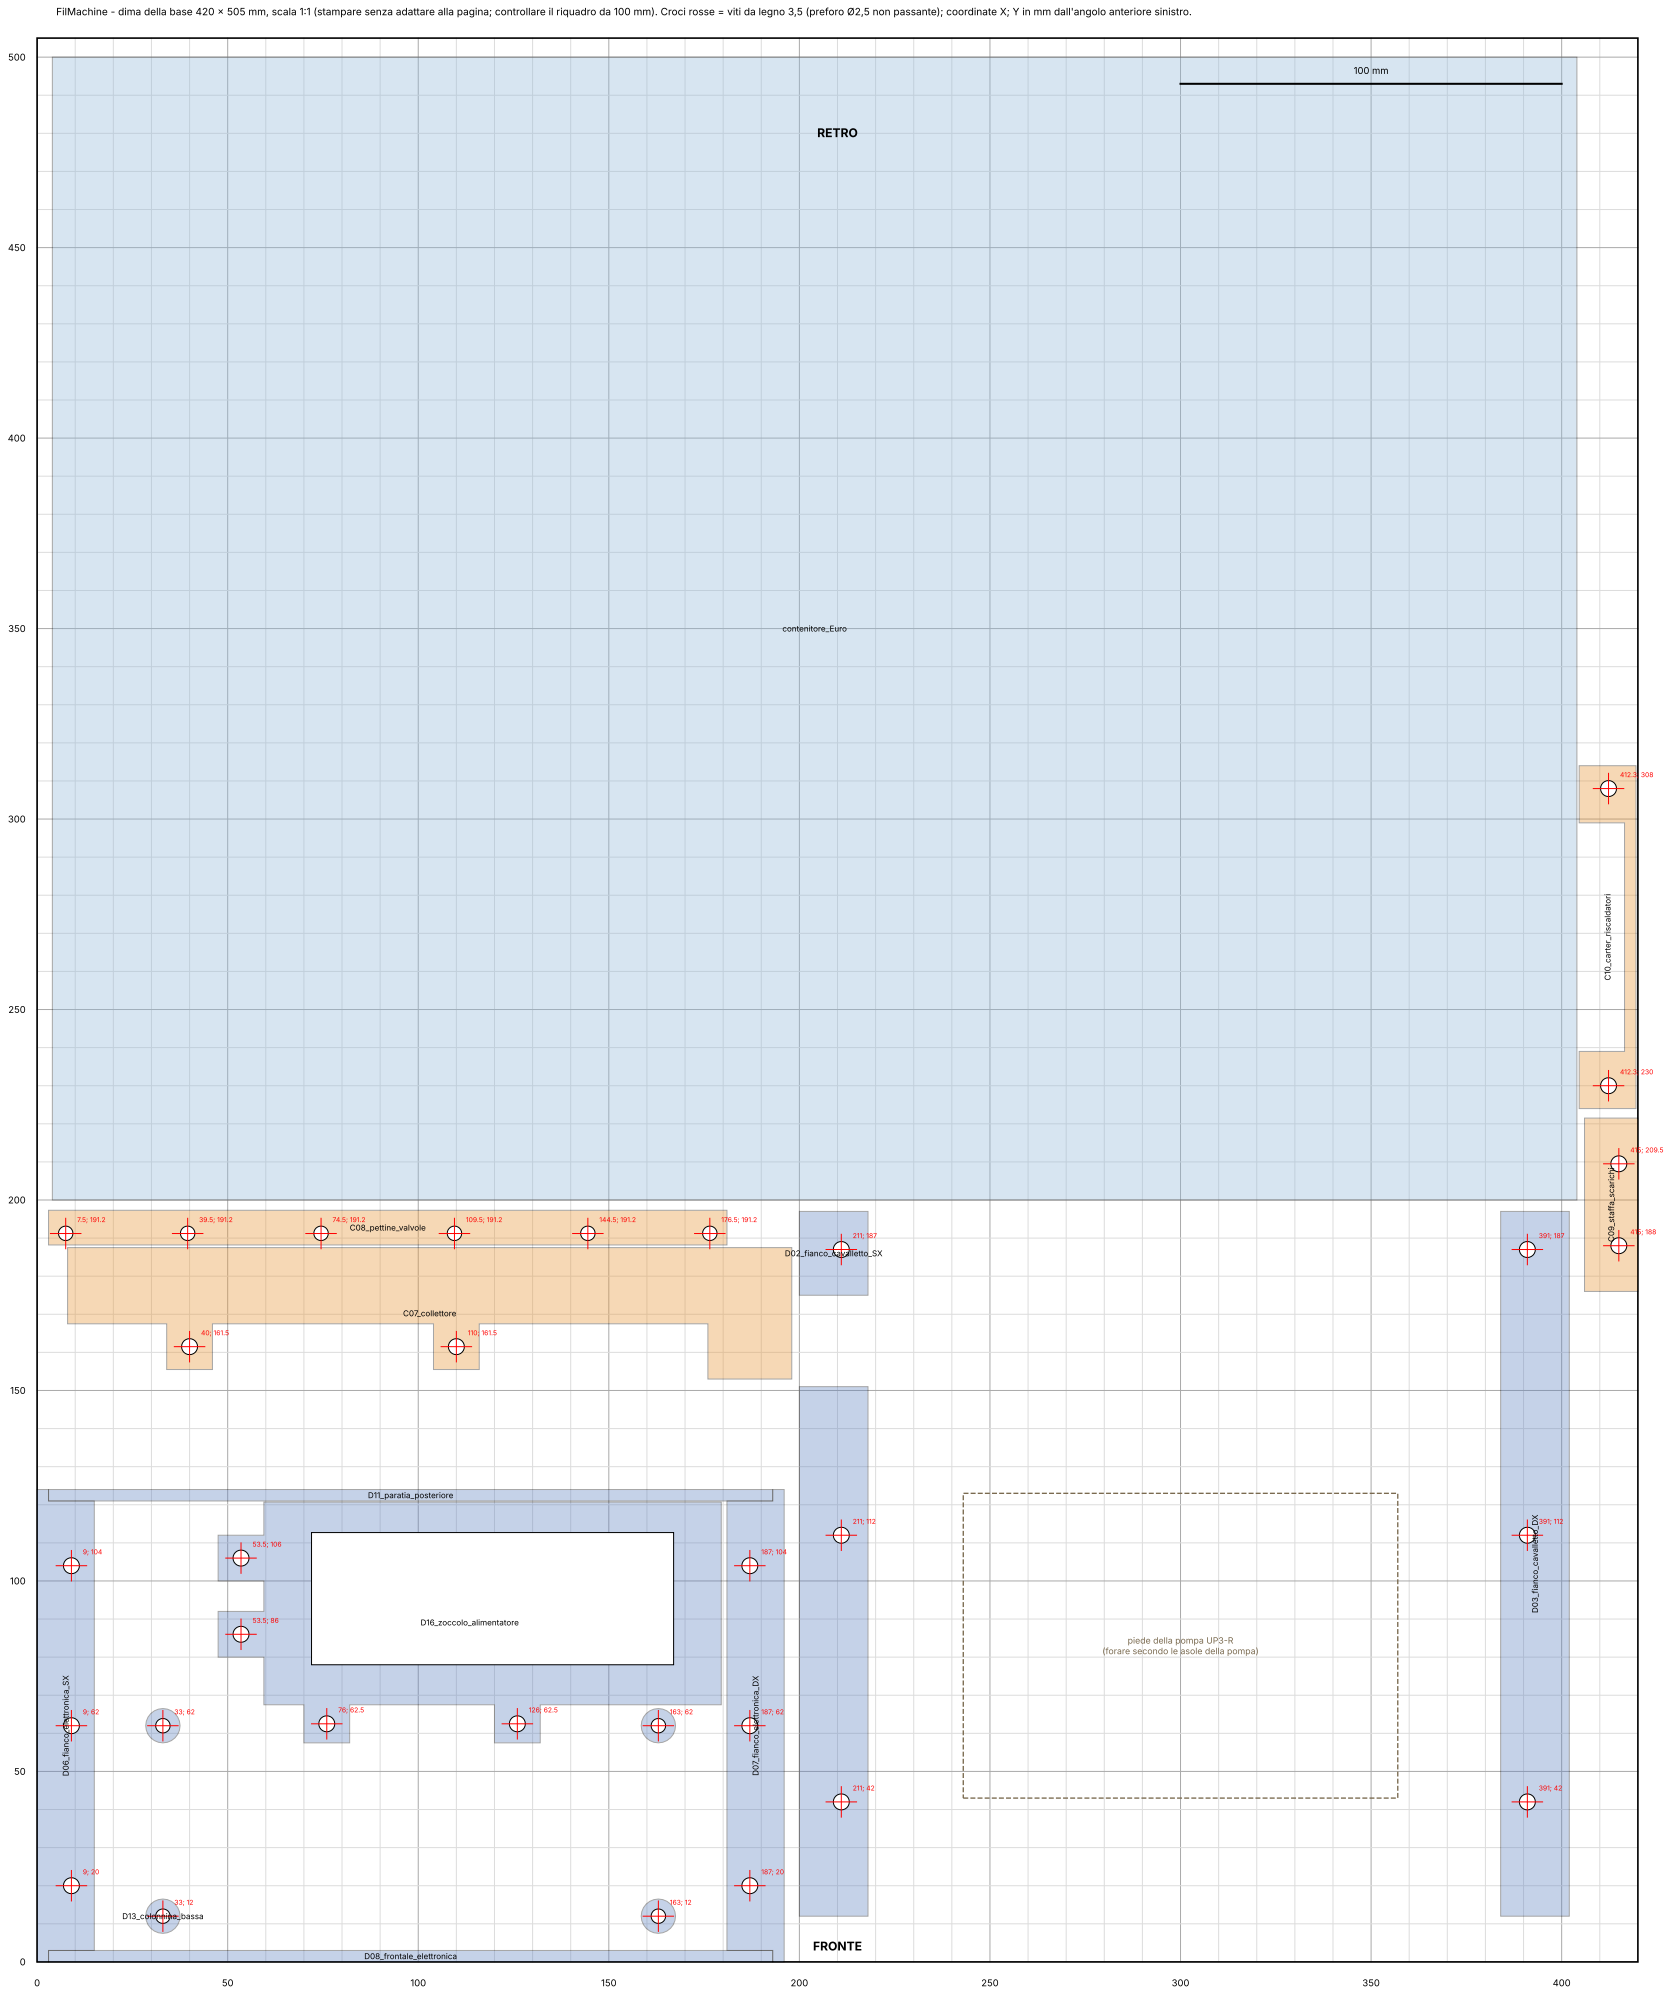
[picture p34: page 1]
contenitore_Euro; C08_pettine_valvole; C09_staffa_scarichi C10_carter_riscaldatori; D03_fianco_cavalletto_DX; D06_fianco_elettronica_SX; D07_fianco_elettronica_DX; D11_paratia_posteriore; D16_zoccolo_alimentatore; RETRO

FilMachine - dima della base 420 x 505 mm, scala 1:1 (stampare senza adattare alla pagina; controllare il riquadro da 100 mm). Croci rosse = viti da legno 3,5 (preforo Ø2,5 non passante); coordinate X; Y in mm dall'angolo anteriore sinistro.

D02_fianco_cavalletto_SX

C07_collettore

piede della pompa UP3-R
(forare secondo le asole della pompa)

D13_colonnina_bassa

FRONTE

D08_frontale_elettronica

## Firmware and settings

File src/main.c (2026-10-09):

/**
 * main.c — FilMachine PC Simulator Entry Point
 *
 * This file REPLACES FilMachine.c (the ESP32 firmware entry point).
 * It defines the same global variables and provides stubs for
 * hardware-specific functions that were in FilMachine.c.
 */

#include <stdio.h>
#include <stdlib.h>
#include <unistd.h>
#include <time.h>
#include <sys/time.h>
#include <stdbool.h>
#include <stdint.h>
#include <string.h>

#include "page_splash.h"
#include "SDL2/SDL.h"
#include "FilMachine.h"
#include "ws_server.h"
#include "src/indev/lv_indev_private.h"   /* access gesture_limit / gesture_min_velocity */

/* ═══════════════════════════════════════════════
 * Global variables (originally in FilMachine.c)
 * ═══════════════════════════════════════════════ */
struct gui_components   gui;
struct sys_components   sys;
bool                    stopMotorManTask = false;
uint8_t                 initErrors = 0;

/* ═══════════════════════════════════════════════
 * Stubs for functions defined in FilMachine.c
 * ═══════════════════════════════════════════════ */
void stopMotorTask(void) {
    stopMotorManTask = true;
    printf("[SIM] Motor task stopped\n");
}

void runMotorTask(void) {
    printf("[SIM] Motor task started (stub — not running in simulator)\n");
    stopMotorManTask = false;
}

/* ═══════════════════════════════════════════════
 * Weak stubs for hardware functions.
 * If accessories.c already defines them (even with empty #if 0 bodies),
 * the linker will prefer that version. Otherwise these are used.
 * ═══════════════════════════════════════════════ */
__attribute__((weak)) void stopMotor(uint8_t pin1, uint8_t pin2) {
    printf("[SIM] Motor stop\n");
}
__attribute__((weak)) void runMotorFW(uint8_t pin1, uint8_t pin2) {
    printf("[SIM] Motor forward\n");
}
__attribute__((weak)) void runMotorRV(uint8_t pin1, uint8_t pin2) {
    printf("[SIM] Motor reverse\n");
}
__attribute__((weak)) void setMotorSpeed(uint8_t pin, uint8_t spd) { }
__attribute__((weak)) void setMotorSpeedUp(uint8_t pin, uint8_t spd) { }
__attribute__((weak)) void setMotorSpeedDown(uint8_t pin, uint8_t spd) { }
__attribute__((weak)) void enableMotor(uint8_t pin) { }
__attribute__((weak)) void testPin(uint8_t pin) { }
__attribute__((weak)) void initializeRelayPins(void) { }
__attribute__((weak)) void initializeMotorPins(void) { }
__attribute__((weak)) void initializeTemperatureSensor(void) { }
__attribute__((weak)) void printTemperature(float temp) { }
__attribute__((weak)) void init_Pins_and_Buses(void) { }
__attribute__((weak)) void initMCP23017Pins(void) { }
__attribute__((weak)) void pwmLedTest(void) { }
__attribute__((weak)) void cleanRelayManager(uint8_t a, uint8_t b, uint8_t c, bool d) { }
__attribute__((weak)) void sendValueToRelay(uint8_t a, uint8_t b, bool c) { }
__attribute__((weak)) void rebootBoard(void) {
    printf("[SIM] Reboot requested — ignoring in simulator\n");
}

/* ═══════════════════════════════════════════════
 * Simulated temperature sensor & heater control
 * ═══════════════════════════════════════════════ */
static float sim_water_temp    = 20.0f;
static float sim_chem_temp     = 20.0f;
static bool  sim_heater_active = false;

#define SIM_HEAT_RATE   0.5f   /* °C per call when heater ON  */
#define SIM_COOL_RATE   0.1f   /* °C per call when heater OFF */
#define SIM_AMBIENT     20.0f  /* Room temperature             */

float sim_getTemperature(uint8_t sensorIndex) {
    /* Update simulation each time temperature is read */
    if (sim_heater_active) {
        sim_water_temp += SIM_HEAT_RATE;
        sim_chem_temp  += SIM_HEAT_RATE * 0.8f;  /* chemistry heats slower */
    } else {
        if (sim_water_temp > SIM_AMBIENT)
            sim_water_temp -= SIM_COOL_RATE;
        if (sim_chem_temp > SIM_AMBIENT)
            sim_chem_temp -= SIM_COOL_RATE;
    }

    /* Apply calibration offset to all temperature readings */
    extern struct gui_components gui;
    float offset = gui.page.settings.settingsParams.tempCalibOffset / 10.0f;

    if (sensorIndex == TEMPERATURE_SENSOR_BATH)
        return sim_water_temp + offset;
    else if (sensorIndex == TEMPERATURE_SENSOR_CHEMICAL)
        return sim_chem_temp + offset;
    return SIM_AMBIENT + offset;
}

void sim_setHeater(bool on) {
    sim_heater_active = on;
    printf("[SIM] Heater %s\n", on ? "ON" : "OFF");
}

void sim_resetTemperatures(void) {
    sim_water_temp    = SIM_AMBIENT;
    sim_chem_temp     = SIM_AMBIENT;
    sim_heater_active = false;
}

/* ═══════════════════════════════════════════════
 * Persistent alarm sound (SDL audio)
 * ═══════════════════════════════════════════════ */
static SDL_AudioDeviceID sim_audio_dev = 0;
static lv_timer_t *alarm_timer = NULL;

static void sim_init_audio(void) {
    if (SDL_InitSubSystem(SDL_INIT_AUDIO) < 0) {
        printf("[SIM] WARNING: SDL_INIT_AUDIO failed: %s\n", SDL_GetError());
        return;
    }
    SDL_AudioSpec spec = {0};
    spec.freq = 44100;
    spec.format = AUDIO_S16SYS;
    spec.channels = 1;
    spec.samples = 2048;
    spec.callback = NULL;
    sim_audio_dev = SDL_OpenAudioDevice(NULL, 0, &spec, NULL, 0);
    if (sim_audio_dev) {
        SDL_PauseAudioDevice(sim_audio_dev, 0);
        printf("[SIM] Audio device initialized (ID: %u)\n", sim_audio_dev);
    } else {
        printf("[SIM] WARNING: Failed to open audio device: %s\n", SDL_GetError());
    }
}

void buzzer_beep(void) {
    if (!sim_audio_dev) return;

    int samples = 44100 * 200 / 1000; /* 200ms */
    int16_t *buf = malloc(samples * sizeof(int16_t));
    if (!buf) return;

    /* Generate 880Hz square wave */
    for (int i = 0; i < samples; i++) {
        buf[i] = (i / (44100/880) % 2) ? 8000 : -8000;
    }

    SDL_ClearQueuedAudio(sim_audio_dev);
    SDL_QueueAudio(sim_audio_dev, buf, samples * sizeof(int16_t));
    free(buf);
    printf("[SIM] BEEP!\n");
}

static void alarm_timer_cb(lv_timer_t *t) {
    (void)t;
    buzzer_beep();
}

void alarm_start_persistent(void) {
    buzzer_beep(); /* immediate beep */
    if (gui.page.settings.settingsParams.isPersistentAlarm) {
        if (alarm_timer == NULL) {
            alarm_timer = lv_timer_create(alarm_timer_cb, 10000, NULL);
        } else {
            lv_timer_resume(alarm_timer);
        }
    }
}

void alarm_stop(void) {
    if (alarm_timer != NULL) {
        lv_timer_pause(alarm_timer);
    }
}

bool alarm_is_active(void) {
    return alarm_timer != NULL && lv_timer_get_paused(alarm_timer) == false;
}

/* ═══════════════════════════════════════════════
 * Demo data generator — used when no config file found
 * ═══════════════════════════════════════════════ */
static void sim_add_step(processNode *proc, const char *name,
                         uint8_t mins, uint8_t secs,
                         uint8_t type, uint8_t source, uint8_t discard)
{
    stepNode *s = (stepNode *)allocateAndInitializeNode(STEP_NODE);
    if (!s) return;
    snprintf(s->step.stepDetails->data.stepNameString, sizeof(s->step.stepDetails->data.stepNameString), "%s", name);
    s->step.stepDetails->data.timeMins = mins;
    s->step.stepDetails->data.timeSecs = secs;
    s->step.stepDetails->data.type     = type;
    s->step.stepDetails->data.source   = source;
    s->step.stepDetails->data.discardAfterProc = discard;
    s->prev = NULL;
    s->next = NULL;

    stepList *list = &proc->process.processDetails->stepElementsList;
    if (list->start == NULL) {
        list->start = s;
    } else {
        list->end->next = s;
        s->prev = list->end;
    }
    list->end = s;
    list->size++;
}

static void sim_add_process(processList *list, processNode *p)
{
    p->prev = NULL;
    p->next = NULL;
    if (list->start == NULL) {
        list->start = p;
    } else {
        list->end->next = p;
        p->prev = list->end;
    }
    list->end = p;
    list->size++;
}

static void sim_generate_demo_data(void)
{
    processList *list = &gui.page.processes.processElementsList;

    /* Process 1: "C41 Color" — temperature controlled */
    processNode *p1 = (processNode *)allocateAndInitializeNode(PROCESS_NODE);
    snprintf(p1->process.processDetails->data.processNameString, sizeof(p1->process.processDetails->data.processNameString), "%s", "C41 Color");
    p1->process.processDetails->data.temp             = 38;
    p1->process.processDetails->data.tempTolerance    = 0.3f;
    p1->process.processDetails->data.isTempControlled = true;
    p1->process.processDetails->data.isPreferred      = true;
    p1->process.processDetails->data.filmType         = COLOR_FILM;
    sim_add_step(p1, "Pre-wash",   1, 0,  1, 3, 1);
    sim_add_step(p1, "Developer",  3, 15, 0, 0, 0);
    sim_add_step(p1, "Bleach",     6, 30, 0, 1, 0);
    sim_add_step(p1, "Wash",       3, 0,  2, 3, 1);
    sim_add_step(p1, "Fix",        6, 30, 0, 2, 0);
    sim_add_step(p1, "Final Wash", 3, 0,  2, 3, 1);
    calculateTotalTime(p1);
    sim_add_process(list, p1);

    /* Process 2: "B&W Classic" — temperature controlled */
    processNode *p2 = (processNode *)allocateAndInitializeNode(PROCESS_NODE);
    snprintf(p2->process.processDetails->data.processNameString, sizeof(p2->process.processDetails->data.processNameString), "%s", "B&W Classic");
    p2->process.processDetails->data.temp             = 20;
    p2->process.processDetails->data.tempTolerance    = 0.5f;
    p2->process.processDetails->data.isTempControlled = true;
    p2->process.processDetails->data.isPreferred      = true;
    p2->process.processDetails->data.filmType         = BLACK_AND_WHITE_FILM;
    sim_add_step(p2, "Developer",  8, 0,  0, 0, 1);
    sim_add_step(p2, "Stop Bath",  1, 0,  0, 1, 0);
    sim_add_step(p2, "Fixer",      5, 0,  0, 2, 0);
    sim_add_step(p2, "Wash",       5, 0,  2, 3, 1);
    calculateTotalTime(p2);
    sim_add_process(list, p2);

    /* Process 3: "Quick Rinse" — no temp control */
    processNode *p3 = (processNode *)allocateAndInitializeNode(PROCESS_NODE);
    snprintf(p3->process.processDetails->data.processNameString, sizeof(p3->process.processDetails->data.processNameString), "%s", "Quick Rinse");
    p3->process.processDetails->data.temp             = 24;
    p3->process.processDetails->data.tempTolerance    = 1.0f;
    p3->process.processDetails->data.isTempControlled = false;
    p3->process.processDetails->data.isPreferred      = false;
    p3->process.processDetails->data.filmType         = BLACK_AND_WHITE_FILM;
    sim_add_step(p3, "Developer",  5, 0, 0, 0, 1);
    sim_add_step(p3, "Fixer",      3, 0, 0, 1, 0);
    sim_add_step(p3, "Rinse",      2, 0, 1, 3, 1);
    calculateTotalTime(p3);
    sim_add_process(list, p3);

    printf("[SIM] Generated %d demo processes\n", (int)list->size);
}

/* ═══════════════════════════════════════════════
 * System queue drain — replaces the sysMan FreeRTOS task.
 *
 * On real hardware, sysMan() runs as a separate FreeRTOS task and
 * processes messages from sys.sysActionQ in a while(1) loop.
 * In the simulator there are no real threads, so we drain the
 * queue once per main-loop iteration instead.
 * ═══════════════════════════════════════════════ */
static void sim_drain_sysActionQ(void)
{
    uint16_t msg;
    /* Process ALL pending messages (there could be more than one) */
    while (xQueueReceive(sys.sysActionQ, &msg, 0)) {
        switch (msg) {

        case SAVE_PROCESS_CONFIG:
            printf("[SIM] sysAction: saving config → %s\n", FILENAME_SAVE);
            writeConfigFile(FILENAME_SAVE, false);
            break;

        case SAVE_MACHINE_STATS:
            printf("[SIM] sysAction: saving machine stats\n");
            writeMachineStats(&gui.page.tools.machineStats);
            break;

        case EXPORT_CFG:
            printf("[SIM] sysAction: export (backup) %s → %s\n",
                   FILENAME_SAVE, FILENAME_BACKUP);
            {
                bool ok = copyAndRenameFile(FILENAME_SAVE, FILENAME_BACKUP);
                printf(ok ? "[SIM] Export/backup successful\n" : "[SIM] Export/backup FAILED\n");
                g_exportOk = ok;
                g_exportSeq++;   /* the app waits for this to change */
            }
            break;

        case RELOAD_CFG:
            printf("[SIM] sysAction: import (restore) %s → %s\n",
                   FILENAME_BACKUP, FILENAME_SAVE);
            if (copyAndRenameFile(FILENAME_BACKUP, FILENAME_SAVE)) {
                printf("[SIM] Import successful — reboot requested (ignored in sim)\n");
                rebootBoard();
            } else {
                printf("[SIM] Import FAILED — backup file missing?\n");
            }
            break;

        default:
            printf("[SIM] sysAction: unknown message 0x%04X\n", msg);
            break;
        }
    }
}

/* ═══════════════════════════════════════════════
 * Time helper
 * ═══════════════════════════════════════════════ */
static uint32_t get_time_ms(void) {
    struct timeval tv;
    gettimeofday(&tv, NULL);
    return (uint32_t)(tv.tv_sec * 1000 + tv.tv_usec / 1000);
}


/* ═══════════════════════════════════════════════
 * Simulator UI hover debug
 * F2 toggles hover debug on/off. Right mouse button dumps the pointed object.
 * ═══════════════════════════════════════════════ */
static lv_obj_t *sim_debug_hover_label = NULL;
static lv_obj_t *sim_debug_hover_box = NULL;
static lv_obj_t *sim_debug_hovered_obj = NULL;
static bool sim_debug_right_btn_prev = false;
static bool sim_debug_enabled = false;
static bool sim_debug_f2_prev = false;

static const char *sim_debug_known_name(lv_obj_t *obj)
{
    if(obj == NULL) return NULL;
#define UI_DEBUG_ENTRY(ptr_expr, name_str) do { if((ptr_expr) == obj) return (name_str); } while(0)
#include "../ui_debug_registry.inc"
#undef UI_DEBUG_ENTRY
    return NULL;
}
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
int main(int argc, char *argv[]) {

    printf("╔══════════════════════════════════════════╗\n");
    printf("║   FilMachine Simulator                   ║\n");
    printf("║   Resolution: %dx%d                    ║\n", LCD_H_RES, LCD_V_RES);
    printf("║ Mouse = Touch | F2 = UI debug | Right click ║\n");
    printf("╚══════════════════════════════════════════╝\n");

    srand((unsigned int)time(NULL));

    /* Initialize globals (zeroes out gui and sys structs) */
    initGlobals();

    /* Initialize LVGL */
    lv_init();
#if LV_USE_LOG != 0
    lv_log_register_print_cb(my_print);   /* LVGL logs -> console (sim) */
#endif

    /* Create SDL display (LVGL 9 built-in SDL driver) */
    lv_display_t *display = lv_sdl_window_create(LCD_H_RES, LCD_V_RES);
    if (!display) {
        fprintf(stderr, "ERROR: Failed to create SDL display!\n");
        return 1;
    }

    /* Initialize SDL audio for buzzer/alarm */
    sim_init_audio();

    /* Create SDL mouse input (simulates touchscreen) */
    lv_indev_t *mouse = lv_sdl_mouse_create();
    if (!mouse) {
        fprintf(stderr, "ERROR: Failed to create SDL mouse input!\n");
        return 1;
    }

    /* Lower gesture thresholds so short/slow swipes are detected more reliably.
       LVGL 9.5 renamed gesture_limit → gesture_min_distance */
    mouse->gesture_min_distance = 30;   /* was 50 — pixels of movement to trigger GESTURE */
    mouse->gesture_min_velocity = 2;    /* was 3  — min per-frame velocity to keep accumulating */

    /* Create FreeRTOS queues (stub implementation) */
    sys.sysActionQ = xQueueCreate(16, sizeof(uint16_t));
    sys.motorActionQ = xQueueCreate(16, sizeof(uint16_t));

    /* Create shared keyboard */
    create_keyboard();

    /* Pre-load settings so splash knows if random mode is enabled */
    readSettingsOnly(FILENAME_SAVE);

    /* Show splash screen — play button calls readConfigFile → menu → refreshSettingsUI */
    lv_obj_t * splash = splash_screen_create();
    lv_scr_load(splash);

    /* WS server starts after splash Play — see splash_play_event_cb() */

    printf("[SIM] GUI initialized — entering main loop\n");
    printf("[SIM] Press F2 to enable/disable UI debug overlay\n[SIM] When enabled: hover highlights widgets, right click dumps details\n");

    /* Main loop */
    uint32_t last_tick = get_time_ms();

    while (1) {
        uint32_t now = get_time_ms();
        uint32_t elapsed = now - last_tick;
        last_tick = now;

        lv_tick_inc(elapsed);
        lv_timer_handler();
        sim_debug_update_overlay(display);

        /* Process any pending system actions (save, export, import, …) */
        sim_drain_sysActionQ();

        usleep(5000); /* ~5ms */
    }

    return 0;
}

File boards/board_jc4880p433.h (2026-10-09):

/**
 * @file board_jc4880p433.h
 * @brief Pin definitions for the ESP32-P4 board — 4.3" ST7701S 480×800 → landscape 800×480
 *
 * Board: GUITION JC4880P433
 * MCU:   ESP32-P4 RISC-V dual-core @ 400 MHz, 32 MB PSRAM (HEX), 16 MB Flash
 * Display: ST7701S 4.3" IPS 480×800, MIPI-DSI 2-lane
 *          Used in landscape mode: LVGL runs at 800×480, PPA rotates 90°
 *          to fill the full 480×800 physical panel
 * Touch: GT911 capacitive, I2C
 * SD: SDMMC 4-bit (much faster than SPI)
 * Audio: ES8311 codec via I2S + PA enable
 *
 * References:
 *   https://github.com/giltal/RetroESP32-P4  (driver source)
 *   https://it.aliexpress.com/item/1005009621821443.html
 */

#ifndef BOARD_JC4880P433_H
#define BOARD_JC4880P433_H

#define BOARD_NAME                  "JC4880P433-P4"

/* ═══════════════════════════════════════════════
 * Display — ST7701S, MIPI-DSI (2-lane)
 *
 * Physical panel: 480×800 portrait (MIPI-DSI, no user-facing GPIO except BLK/RST)
 * LVGL resolution: 800×480 landscape (full panel, no scaling)
 * PPA handles rotation 90° only → fills 480×800 physical panel
 * ═══════════════════════════════════════════════ */
#define DISPLAY_DRIVER_ST7701       1
#define DISPLAY_BUS_MIPI_DSI        1

/* LVGL logical resolution — what FilMachine UI sees (landscape) */
#define LCD_H_RES                   800
#define LCD_V_RES                   480

/* Physical panel resolution — used internally by ST7701 driver & PPA */
#define LCD_PHYS_H_RES              480
#define LCD_PHYS_V_RES              800

/* PPA landscape configuration */
#define PPA_LANDSCAPE_ROTATION      90      /* degrees */
#define PPA_LANDSCAPE_SCALE         1.0f    /* no scaling — 800×480 fills 480×800 */

#define LCD_BLK                     23      /* Backlight enable (active high) */
#define LCD_RST_PIN                 5       /* LCD reset (active low), -1 if not used */

/* ═══════════════════════════════════════════════
 * Touch — GT911 capacitive, I2C
 * Uses the standard esp_lcd_touch_gt911 driver.
 * Physical touch area: 480×800 portrait.
 * Coordinate remapping to 800×480 landscape is done
 * in the custom touch callback (see FilMachine.c).
 * ═══════════════════════════════════════════════ */
#define TOUCH_DRIVER_GT911          1
#define TOUCH_DRIVER_GT911_P4       1       /* Enables P4-specific coord remapping */

#define I2C_SDA                     7       /* Touch/peripheral I2C data */
#define I2C_SCL                     8       /* Touch/peripheral I2C clock */
#define TOUCH_INT_PIN               (-1)    /* GT911 interrupt (not wired) */
#define TOUCH_RST_PIN               (-1)    /* GT911 reset (not wired) */

/* ═══════════════════════════════════════════════
 * SD Card — SDMMC 4-bit (not SPI!)
 * Much faster than SPI: up to 40 MB/s vs ~4 MB/s
 * ═══════════════════════════════════════════════ */
#define SD_BUS_SDMMC                1       /* Flag: use SDMMC driver instead of SPI */
#define SD_MMC_CLK                  43
#define SD_MMC_CMD                  44
#define SD_MMC_D0                   39
#define SD_MMC_D1                   40
#define SD_MMC_D2                   41
#define SD_MMC_D3                   42

/* ═══════════════════════════════════════════════
 * Audio — ES8311 codec via I2S + power amplifier
 * ═══════════════════════════════════════════════ */
#define HAS_SPEAKER                 1
#define HAS_AUDIO_CODEC             1       /* ES8311 — much richer than raw I2S */
#define SPEAKER_I2S                 1
#define I2S_MCLK_PIN                13
#define I2S_BCLK_PIN                12
#define I2S_WS_PIN                  10      /* Word select / LRCLK */
#define I2S_DOUT_PIN                9       /* ESP32 → ES8311 SDIN */
#define I2S_DIN_PIN                 48      /* ES8311 DOUT → ESP32 (mic/line-in) */
#define AUDIO_PA_PIN                11      /* Power Amplifier enable (active high) */

/* ═══════════════════════════════════════════════
 * Motor — DC motor with H-bridge (DBH-12V channel A)
 * All pins routed via the Expand IO header (JP1).
 * ═══════════════════════════════════════════════ */
#define MOTOR_PIN_NUMBER            3
#define MOTOR_ENA_PIN               32      /* PWM speed control — JP1 pin 19 */
#define MOTOR_IN1_PIN               33      /* H-bridge direction A — JP1 pin 8 */
#define MOTOR_IN2_PIN               34      /* H-bridge direction B — JP1 pin 17 */

/* ═══════════════════════════════════════════════
 * Temperature — DS18B20 OneWire
 * ═══════════════════════════════════════════════ */
#define TEMPERATURE_BUS_PIN         35      /* OneWire data — JP1 pin 15 */
#define TEMPERATURE_SENSOR_BATH     0
#define TEMPERATURE_SENSOR_CHEMICAL 1
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

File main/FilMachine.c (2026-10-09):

#include <stdio.h>
#include <string.h>
#include <stdbool.h>
#include <unistd.h>

#include "page_splash.h"
#include "esp_timer.h"
#include "esp_lcd_panel_dev.h"
#include "esp_lcd_panel_ops.h"
#include "esp_lcd_touch.h"
#include "esp_err.h"
#include "esp_log.h"
#include "lvgl.h"
#include "freertos/FreeRTOS.h"
#include "freertos/task.h"
#include "freertos/queue.h"

/* FilMachine.h pulls in board.h which defines DISPLAY_DRIVER_xxx
 * and TOUCH_DRIVER_xxx — must come BEFORE the conditional includes. */
#include "FilMachine.h"
#include "sd_log.h"
#include "nvs_flash.h"

/* ═══════════════════════════════════════════════
 * Board-specific display and touch driver includes
 * ═══════════════════════════════════════════════ */
#if defined(DISPLAY_DRIVER_ST7701)
    #include "st7701_lcd.h"
    #include "ppa_engine.h"
    #include "esp_cache.h"
    #include "esp_heap_caps.h"
#elif !defined(DISPLAY_DRIVER_SDL)
    #error "No display driver defined — check board.h"
#endif

#if defined(TOUCH_DRIVER_GT911)
    #include "esp_lcd_touch_gt911.h"
#elif !defined(DISPLAY_DRIVER_SDL)
    #error "No touch driver defined — check board.h"
#endif

/* Global Stuff */
struct gui_components gui;
struct sys_components sys;

static const char *TAG = "FilMachine"; /* ESP Debug Message Tag */
bool stopMotorManTask = false;
uint8_t initErrors = 0;

#if defined(DISPLAY_DRIVER_ST7701)
/* ── P4: LVGL partial rendering with double-buffered PSRAM draw buffers ── */
static uint8_t *lvgl_buf1 = NULL;
static uint8_t *lvgl_buf2 = NULL;

/* ── Dual-core async flush: core 0 renders, core 1 flushes via PPA ── */
typedef struct {
    lv_display_t *disp;
    uint16_t x1, y1, w, h;
    const uint16_t *data;
    bool is_last_flush;
} flush_job_t;

static QueueHandle_t      s_flush_queue = NULL;
static lv_display_t      *s_flush_disp  = NULL;

/* FPS tracking */
static volatile int64_t s_fps_window_start = 0;
static volatile int     s_fps_frame_count  = 0;
static volatile int     s_fps_flush_count  = 0;

static void flush_task(void *arg)
{
    flush_job_t job;
    ESP_LOGI("FLUSH", "Flush task started on core %d", xPortGetCoreID());

    while (1) {
        if (xQueueReceive(s_flush_queue, &job, portMAX_DELAY) != pdTRUE) continue;

        /* Flush CPU D-cache → PSRAM so PPA's DMA reads fresh pixels.
         * Core 0 wrote the draw buffer; Core 1 (here) triggers PPA DMA.
         * DMA bypasses CPU cache, so explicit sync is mandatory. */
        esp_cache_msync((void *)job.data, (size_t)job.w * job.h * sizeof(uint16_t),
                        ESP_CACHE_MSYNC_FLAG_DIR_C2M | ESP_CACHE_MSYNC_FLAG_UNALIGNED);

        st7701_lcd_draw_to_fb_rotated(job.x1, job.y1, job.w, job.h, job.data);

        s_fps_flush_count++;
        if (job.is_last_flush) {
            s_fps_frame_count++;
            int64_t now = esp_timer_get_time();
            if (s_fps_window_start == 0) s_fps_window_start = now;
            int64_t elapsed_us = now - s_fps_window_start;
            if (elapsed_us >= 2000000) {
                float fps = (float)s_fps_frame_count * 1000000.0f / (float)elapsed_us;
                ESP_LOGI("FPS", "%.1f FPS  (%d frames, %d flushes in %lld ms)",
                         fps, s_fps_frame_count, s_fps_flush_count, elapsed_us / 1000);
                s_fps_frame_count = 0;
                s_fps_flush_count = 0;
                s_fps_window_start = now;
            }
        }
        lv_display_flush_ready(job.disp);
    }
}
#else
/* ── S3/Simulator: static draw buffer, partial rendering ── */
static uint8_t lvgl_buf[LVGL_BUF_SIZE];
#endif

/* ═══════════════════════════════════════════════
 * LVGL integration functions — board-specific flush & tick
 * ═══════════════════════════════════════════════ */

#if defined(DISPLAY_DRIVER_ST7701)
/* ── P4: Dual-core async flush.
 * Core 0 (LVGL) posts flush jobs to a queue.
 * Core 1 (flush_task) picks them up, runs cache sync + PPA rotation,
 * and signals flush_ready.
 */
static void disp_flush(lv_display_t *disp, const lv_area_t *area, uint8_t *px_map)
{
    flush_job_t job = {
        .disp = disp,
        .x1   = area->x1,
        .y1   = area->y1,
        .w    = (uint16_t)(area->x2 - area->x1 + 1),
        .h    = (uint16_t)(area->y2 - area->y1 + 1),
        .data = (const uint16_t *)px_map,
        .is_last_flush = lv_display_flush_is_last(disp),
    };

    /* Post to core 1 — returns immediately so LVGL can render into the other buffer.
     * portMAX_DELAY is safe because core 1 processes jobs fast (~7ms). */
    xQueueSend(s_flush_queue, &job, portMAX_DELAY);
    /* NOTE: we do NOT call lv_display_flush_ready() here.
     * Core 1's flush_task calls it after PPA completes. */
}

#else
/* ── S3: standard esp_lcd_panel flush via bus (I80 / QSPI) ── */
static bool notify_lvgl_flush_ready(esp_lcd_panel_io_handle_t panel_io, esp_lcd_panel_io_event_data_t *edata, void *user_ctx) {

    lv_display_t *display = (lv_display_t *)user_ctx;
    lv_display_flush_ready(display);
    return false;
}

static void disp_flush(lv_display_t * disp, const lv_area_t * area, uint8_t * px_map) {

    esp_lcd_panel_handle_t panel_handle = lv_display_get_user_data(disp);
    int offsetx1 = area->x1;
    int offsetx2 = area->x2;
    int offsety1 = area->y1;
    int offsety2 = area->y2;
    esp_lcd_panel_draw_bitmap(panel_handle, offsetx1, offsety1, offsetx2 + 1, offsety2 + 1, px_map);
}
#endif /* DISPLAY_DRIVER_ST7701 */

static void increase_lvgl_tick(void *arg) {

    /* Tell LVGL how many milliseconds has elapsed */
    lv_tick_inc(LVGL_TICK_PERIOD_MS);
}

/* Number of simultaneous touch points last reported (for the 2-finger
 * diagnostics gesture on the splash). Updated every touch read. */
static volatile uint8_t s_active_touch_points = 0;
uint8_t ui_active_touch_points(void) { return s_active_touch_points; }
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

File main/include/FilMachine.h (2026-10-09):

/*
 * FilMachine.h
 *
 *  Created on: May 1, 2025
 *      Author: PeterB
 */

#ifndef MAIN_FILMACHINE_H_
#define MAIN_FILMACHINE_H_

#include "lang.h"

#include "freertos/FreeRTOS.h"
#include "lvgl.h"

/* ═══════════════════════════════════════════════
 * Board-specific hardware definitions
 * All pin assignments, resolution, display/touch driver selection,
 * and sensor availability come from the active board header.
 * Select board at compile time: -DBOARD_JC4880P433 or -DBOARD_SIMULATOR
 * ═══════════════════════════════════════════════ */
#include "board.h"
#include "ui_profile.h"

#ifdef BOARD_SIMULATOR
void sim_ui_debug_tag(lv_obj_t *obj, const char *name);
#else
#define sim_ui_debug_tag(obj, name) ((void)0)
#endif

#define FILM_USE_LOG				1

/* Motor speed limits (independent of board) */
#define MAX_MOTOR_SPD				200
#define MOTOR_MIN_ANALOG_VAL		90      /* Lowered from 150: widens usable slider range. Re-tune if motor stalls at low duty. */
#define MOTOR_MAX_ANALOG_VAL		255
#define MOTOR_KICK_DUTY				170                    /* breakaway kick duty (overcomes stiction on start); ~67%, above the ~145 breakaway */
#define MOTOR_KICK_MS				100                    /* breakaway kick duration in ms */

/* Boot valve self-test — opens then closes each valve in sequence at power-on. */
#define VALVE_SELFTEST_ON_BOOT		1                      /* set to 0 to disable */
#define SENSOR_SELFTEST_ON_BOOT		1                      /* live-log Hall/water-level/flow every 500ms (set 0 to disable) */
#define VALVE_SELFTEST_LAST_PIN		4                      /* valves only (0-4). Pins 5-6 unused, heater moved to Port B — skip 5-7 */
#define VALVE_SELFTEST_ON_MS		500                    /* how long each channel stays on */
#define VALVE_SELFTEST_OFF_MS		250                    /* pause between channels */

/* Pump speed (0-255, 8-bit duty cycle) */
#define PUMP_DEFAULT_SPEED          200     /* Fallback only (e.g. checkup/manual actions) */
#define PUMP_MIN_ANALOG_VAL         150     /* Duty at pumpSpeed=10%. Measured stall/start ~148 on the bench, so 10% now already moves. */
#define PUMP_MAX_ANALOG_VAL         250     /* Duty at pumpSpeed=100% (DBH-12V safe max) */

/* LCD timing (used by parallel-bus boards, ignored by QSPI/simulator) */
#ifndef LCD_PIXEL_CLOCK_HZ
#define LCD_PIXEL_CLOCK_HZ			(40000000)
#endif
#define LCD_BK_LIGHT_ON_LEVEL		1
#define LCD_BK_LIGHT_OFF_LEVEL		!LCD_BK_LIGHT_ON_LEVEL
#define LCD_CMD_BITS				8
#define LCD_PARAM_BITS				8

/* LVGL timing */
#define LVGL_TICK_PERIOD_MS			2

/* I2C instance (shared across touch, MCP23017, PCA9685) */
#define I2C_NUM						0
#if defined(BOARD_JC4880P433)
    #include "driver/i2c_master.h"
    extern i2c_master_bus_handle_t g_i2c_bus_handle;
#endif

/* System defines */
#define FILENAME_SAVE				"/FilMachine.json"
#define FILENAME_BACKUP				"/FilMachine_Backup.json"
#define MAX_STEP_ELEMENTS			30
#define MAX_PROC_ELEMENTS			50
#define CONTAINER_FILLING_TIME		10		//Need to be calibrated
#define WB_FILLING_TIME				30		//Need to be calibrated
#define ENABLE_BOOT_ERRORS			0		//Set to 1 to enable all errors (SD/I2C)
#define INIT_ERROR_SD				1
#define INIT_ERROR_WIRE				2
#define INIT_ERROR_I2C_MCP			3
#define INIT_ERROR_I2C_ADS			4
#define initSDError_text	tr(STR_initSDError_text)
#define initI2CError_text	tr(STR_initI2CError_text)
#define initWIREError_text	tr(STR_initWIREError_text)
/* ACCESSORY STRUCTS */
typedef enum{
    STEP_NODE,
    PROCESS_NODE
} NodeType_t;

typedef enum {
    BLACK_AND_WHITE_FILM,
    COLOR_FILM,
    BOTH_FILM,
    FILM_TYPE_NA
} filmType_t;

typedef enum {
    CELSIUS_TEMP,
    FAHRENHEIT_TEMP,
    TEMP_UNIT_NA
} tempUnit_t;

typedef enum {
    CHEMISTRY,
    RINSE,
    MULTI_RINSE,
    CHEMICAL_TYPE_NA
} chemicalType_t;

/* GUI Related defines */
#define TAB_PROCESSES				3
#define TAB_SETTINGS				4
#define TAB_TOOLS					5

/* UI Layout Constants — resolved from ui_profile at runtime.
   These macros keep backward compatibility with existing code while
   routing through the profile so values adapt to the active board. */
#define STEP_HEIGHT					(ui_get_profile()->step_element.card_h)
#define STEP_Y_START				(ui_get_profile()->step_element.list_start_y)
#define PROCESS_ELEMENT_HEIGHT		(ui_get_profile()->process_element.card_h)
#define PROCESS_Y_START				(ui_get_profile()->process_element.list_start_y)
#define POPUP_WIDTH					(ui_get_profile()->popups.message_w)
#define POPUP_HEIGHT				(ui_get_profile()->popups.message_h)

/* Splash screen strings */
#define splashTitle_text	tr(STR_splashTitle_text)
#define splashSubtitle_text	tr(STR_splashSubtitle_text)
#define splashVersion_text						softwareVersionValue_text
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

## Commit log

2026-03-14 fix: resolve step duplication bugs, improve swipe detection, full code audit
    - Fix double size++ bug: insertStepElementAfter already increments
    stepElementsList.size, removed redundant size++ in both
    element_messagePopup.c and element_step.c duplicate handlers
    - Fix step duplicate not appearing: move GUI creation (stepElementCreate
    + reorderStepElements) to AFTER popup modal closes, so LVGL
    invalidation actually triggers a redraw
    - Change duplicate step insertion to always append at end of list
    (addStepElement) instead of insertStepElementAfter, fixing visual
    update issues with intermediate step duplication
    - Add lv_obj_update_layout() in reorderStepElements to force scrollable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
    [FilMachine.cfg, FilMachine.json, FilMachine_Backup.cfg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]
2026-03-15 feat: add automated test framework (76 tests, 12 suites)
    Add comprehensive test framework for the FilMachine Simulator with 76 tests
    across 12 suites covering navigation, CRUD operations, settings, filters,
    tools, edge cases, and utility functions. All tests pass (76/76).
2026-03-15 feat: add temperature control simulation with live UI updates
    - Implement heater ON/OFF logic with simulated heating/cooling rates
    - Add real-time temperature display for water and chemistry sensors
    - Add safety timeout (10 min) and CONTINUE button when temp reached
    - Fix LVGL float display (snprintf workaround for builtin sprintf)
    - Add demo process generation fallback when config file is missing
    - Auto-copy sd/FilMachine.cfg into build dir during cmake configure
    [FilMachine.cfg, FilMachine.json, FilMachine_Backup.cfg]
2026-03-16 fix: drag & drop auto-scroll, save button, snprintf float display
    - Add proportional auto-scroll during step drag (speed based on distance from edge)
    - Fix Save button not activating after step reorder (prev pointer comparison)
    - Reset scroll position after dropping step to avoid stuck offset
    - Fix tolerance display showing 'f' (lv_snprintf → snprintf for float support)
    - Fix temperature display in checkup page (same snprintf workaround)
    - Move checkup UI strings to FilMachine.h defines
    [FilMachine.h]
2026-03-16 feat: add MCP23017 ESP-IDF driver, DS18B20 temperature sensors, full Arduino-to-ESP-IDF conversion
    Replace all Arduino mcp.digitalWrite/ledcWrite calls in accessories.c with
    native ESP-IDF MCP23017 driver and LEDC PWM API. Add DS18B20 OneWire
    bit-banged driver for bath (GPIO19) and chemical (GPIO17) temperature
    sensors. Remove old c_graphics/ duplicate files. Update simulator stubs.
    [FilMachine.h, ds18b20.c]
2026-05-02 Major upgrade: ESP32-P4 port, DBH-12V pump H-bridge, PCA9685 removed, new UI pages
    [FilMachine.cfg, FilMachine.json, FilMachine_Backup.cfg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]
2026-05-04 Updated pin layout
    [FontUsage.xlsx]
2026-05-04 Removed old reference to board not used
2026-06-09 Fix PumpInvert switch
    [FilMachine.cfg, FilMachine.json, FilMachine_Backup.cfg]
2026-07-04 Speed tuning popup, unified versioning, pump/motor calibration, dependency fixes
    UI
    - Replace Pump/Motor speed sliders with a TUNE button + dedicated roller popup
    (element_speedPopup.c): 10-100% in steps of 5, a live Test switch that runs
    the pump/motor at the selected speed, and SET which stops, saves and shows a
    confirmation popup. Styled to match the temperature roller.
    Hardware
    - Wire the pump-speed setting into the H-bridge duty (pumpPercentToDuty).
    - Calibrate PUMP_MIN_ANALOG_VAL=150 (bench start ~148) so the whole slider moves.
    - Widen agitation motor range (MOTOR_MIN_ANALOG_VAL 150 -> 90).
    - Apply invertPump in the simulator stub too, for parity with hardware.
    Versioning
    - Si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
    [ESP32-P4-Guition v30-backside-include.step.3mf, FilMachine.cfg, FilMachine.json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]
2026-07-04 Add ES8311 audio backend and Volume setting
    Audio backend
    - New drivers/audio.c: bring up the ES8311 codec over I2S (16-bit, 16 kHz) on the
    shared I2C bus (addr 0x18) with the power amp on GPIO 11, via the espressif
    esp_codec_dev component (pinned 1.2.*). Exposes audio_init / audio_set_volume /
    audio_play_tone; buzzer_beep() now emits a real tone and the codec is initialised
    at startup.
    Volume setting
    - New Volume row in Settings with a TUNE button + roller popup (0-100%, step 5) that
    plays a tone at the selected volume as you scroll, plus a confirmation popup on SET.
    Reuses the speed-popup styling; the "?" help is wired.
    - Store the volume in the freed legacy dimTimeout byte (s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
    [FilMachine.h, audio.c, page_settings.c]
2026-07-04 Motor breakaway kick + H-bridge safe boot state
    - Force the DBH-12V H-bridge control pins (motor + pump IN/EN) LOW as the very
    first thing in app_main (hbridge_safe_init), so the driver stays off from the
    moment the app runs instead of floating for ~2 s until the full motor/pump
    init. Greatly reduces the power-on motor/pump twitch (external pull-downs on
    the enable lines still recommended to cover the ROM-bootloader window).
    - Add a startup "kick" to overcome motor stiction: briefly drive the agitation
    motor at a higher duty to break static friction, then settle to the set speed,
    so low speeds start reliably from rest. Applied both to the Volume/Speed Test
    switch and to real a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
    [FilMachine.c, FilMachine.h]
2026-07-04 Dual temperature calibration, DS18B20 robustness, sensor bring-up
    Temperature calibration
    - New two-column calibration popup (element_calibPopup.c): Bath | Chemical, each
    with a live sensor reading and a roller to set the true temperature. SET stores
    a per-sensor offset: bath in the config, chemical in NVS (no microSD reformat).
    - TUNE now opens this popup; long-press resets both offsets.
    DS18B20 reliability + UI responsiveness
    - Reject out-of-range reads (-55..125 C), e.g. the 0x1250 -> 293 C garbage, and
    keep the last good value per sensor so glitches don't flash the UI.
    - Protect the OneWire bit-bang with short critical sections (preemption was
    corrupting reads once more tasks ra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
    [FilMachine.c, FilMachine.h, ds18b20.c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]
2026-07-04 Add Maintenance 'Fill bath' with flow-metered volume control
    New Maintenance item (after Self Check) to fill the water bath, fully
    independent of the process state machine.
    UI (element_fillPopup.c, page_tools.c, ui_profile):
    - Popup with Start -> Stop -> Close phases; no auto-start on open.
    - Level bargraph driven by metered volume, live 'x / target ml' + L/min.
    - Opens straight into 'Water bath full' if the MAX float is already wet.
    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
2026-07-04 Fill modes, chem offset in config, resilient config loading
    Fill popup:
    - Honour the Water inlet setting: with inlet ON, meter volume via the flow
    sensor and stop at target; with inlet OFF, fill by hand using the level
    floats only (no valve, no metering).
    - Don't auto-start on open — require a Start press (Start -> Stop -> Close),
    add an always-available X to leave the popup (stops the fill first), and
    open straight into 'full' if the bath is already full.
    Temperature calibration:
    - Move the chemical-sensor offset out of NVS into settingsParams
    (chemCalibOffset) so both offsets live in the config file; update the
    generator, factory/long-press resets and defaults.
    Config robus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
    [FilMachine.h, page_settings.c]
2026-07-04 Fill modes, chem offset in config, resilient config loading, sim build fix
    - Honour the Water inlet setting: inlet ON meters volume via the flow sensor
    and stops at target; inlet OFF fills by hand using the level floats only.
    - Require a Start press (Start -> Stop -> Close), add an always-available X
    to leave the popup (stops the fill first), and open straight into 'full'
    if the bath is already full.
    - Move the chemical-sensor offset from NVS into settingsParams
    Config robustness:
    - Log settingsSize + raw process count on lo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
    [ds18b20.c]
2026-07-04 Fill popup: match the Self-check X close button style/placement
2026-07-05 JSON-only config, calibration int16 fix, unified popup buttons, process edit mode
    Config
    - Replace the fragile binary .cfg with JSON-only storage (FilMachine.json).
    New dependency-free mini JSON parser (main/mini_json.c/.h) builds on both the
    board and the SDL simulator (no cJSON). readConfigFile/readSettingsOnly parse
    JSON; writeConfigFile serialises it with a crash-safe .tmp + rename.
    - genFilMachineCFG.py emits JSON only; COMMANDS.md updated for the .json copy.
    - Repurpose the old chem/wb container-ml bytes as calibrated fill times
    (chemCalibFillSecs / wbCalibFillSecs); tank capacity is now a fallback only.
    - Fix offset overflow: tempCalibOffset/chemCalibO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
    [FilMachine.c, FilMachine.h, board_jc4880p433.h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]
2026-07-05 Peripheral diagnostics page, chip temp / power-rail scaffolding, boot-error screen
    Diagnostics (new c_pages/page_debug.c)
    - Factory/bring-up page: hold 2 fingers on the splash for 3s (board) or press the
    DBG button (simulator) to open it. Grouped panels show the live state of every
    peripheral (temperatures, water + chemical levels, Hall, flow, MCP23017, SD,
    WiFi) and buttons actuate each output (valves C1/C2/C3/WB/Waste, pump FW/RV,
    motor FW/RV, heaters H1/H2, audio tone). Close turns all outputs off.
    - System panel also shows the ESP32-P4 internal chip temperature and the last
    reset reason.
    - "Power rails" panel scaffolding: reads 12V/5V/3.3V via ADC when the custom
    board provid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
    [FilMachine.c, FilMachine.h, board_jc4880p433.h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]
2026-07-05 Docs: update README — JSON config schema, MCP pin map, BOM, diagnostics page
    - Hardware: correct the MCP23017 pin map (Port B repurposed for 6 chemical-level
    sensors + 2 heater MOSFETs; Port A valves + heater relay); update board spec
    (sensors, dual heater, Wi-Fi via ESP32-C6).
    - Configuration: rewrite for the JSON-only store (FilMachine.json) with the full
    settingsParams / processes / steps / machineStats schema and field notes.
    - Add a Bill of Materials (components + quantities) for cost estimation.
    - Add a Diagnostics & Bring-up Page section (2-finger gesture, live monitor,
    output controls) and a Build-time Switches table.
    - Update the table of contents and point to COMMANDS.md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
2026-07-05 Remove calibratedTemp, wire multiRinseTime into multi-rinse steps
    Config schema:
    - Remove the obsolete calibratedTemp setting everywhere: struct,
    JSON read/write, defaults, ws_server report/set/reset, the
    generator script, sd/data/scripts JSON files, README example
    and the persistence/websocket tests (now exercise tempCalibOffset).
    Multi-rinse step execution (page_checkup.c):
    - A MULTI_RINSE step is no longer a single soak. It now repeatedly
    fills from the water bath, agitates for one multiRinseTime cycle,
    then drains to waste, until the step's total time elapses. If the
    total isn't a multiple of the cycle, the last cycle runs longer so
    the step still ends exactly on time (mat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
    [ESP32-P4-Guition v30-backside-include.step.3mf, FilMachine.json]
2026-07-05 Remove calibratedTemp, add multi-rinse cycling, Windows CI build
    the step still ends exactly on time (matc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
2026-07-05 CI: neutralise LVGL ARM asm so the Windows simulator builds
    LVGL 9.5 ships Helium/NEON .S files that its CMake compiles
    unconditionally. With LV_USE_DRAW_SW_ASM=NONE they are unused, but a
    non-ARM assembler (MinGW `as` on the Windows runner) fails on them.
    After cloning LVGL, blank any src/*.S so LVGL builds as portable C.
    Harmless on macOS/ARM, where the software blend path is already used.
2026-07-05 CI: make the simulator compile on Windows/MinGW
    - esp_stubs.h: only define the itoa() fallback on non-Windows. MinGW's
    <stdlib.h> already declares itoa(), which clashed with the static stub.
    - ws_server.c: the POSIX-socket WebSocket server isn't ported to Winsock.
    On Windows compile no-op stubs of the public API instead, so the exe
    links. The remote-control feature is simply disabled on Windows; the
    rest of the simulator runs normally. macOS/Linux keep the real server.
2026-07-06 CI: fix fatfs stubs for Windows/MinGW
    - Include <stdint.h> (uint8_t was undefined in the f_open prototype).
    - MinGW's mkdir() takes only a path: use _mkdir() from <direct.h> on
    Windows, keep POSIX mkdir(path, mode) elsewhere.
2026-07-06 CI: bundle a generated SD config with sample processes
    sd/ is gitignored, so the runner had no config to copy and the packaged
    simulator started empty. Install Python in MSYS2 and run
    scripts/genFilMachineCFG.py --realistic to emit FilMachine.json (+backup)
    with the current schema and the realistic sample processes into dist/sd/,
    so the Windows build ships with processes out of the box.
2026-07-06 Add optional line rinse between chemistry steps
    Anti-cross-contamination feature: after each CHEMISTRY step, flush the
    shared pump line with clean water from the water bath (discarded to waste)
    for a configurable time before drawing the next liquid, clearing chemistry
    residue from the common tubing.
    - New settings: lineRinseEnabled (bool, opt-in default off) + lineRinseTime
    (5-60 s). Wired through struct, JSON read/write, ws_server report/set/reset
    and the config generator.
    - Settings UI: a switch ("Rinse line after chemistry") and a duration slider
    with help popup, persistence, load-on-open and factory defaults. Both are
    registered in the event-handler whitelist so their events are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
    [FilMachine.h, page_settings.c]
2026-07-06 Expose display, pump and splash settings over WebSocket; remove legacy leftovers
    - ws_server: add invertPump, brightness, volume, chemCalibOffset and all
    splash settings (default/random/palette/shapeStyle/complexity) to the
    state JSON and set_setting, with range clamping. brightness and volume
    are applied live; reset_defaults now also restores the new fields.
    - Remove legacy chemContainerMl/wbContainerMl remnants (UI texts, roller
    lists, GUI struct pointers, popup handlers, ui_debug_registry entries)
    superseded by chemCalibFillSecs/wbCalibFillSecs.
    - Remove unused pump_brake() (both board and simulator definitions).
    - Fix stale comments (random_switch_y) and README (pca9685 removal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
    [FilMachine.h, page_settings.c]
2026-07-07 Add bilingual UI (EN/IT), SD boot/crash logging, and UI polish
    Localization:
    - All ~350 UI strings moved to a runtime EN/IT table (main/lang.c,
    lang.h) resolved via tr(); the xxx_text macros in FilMachine.h now
    expand to table lookups, call sites unchanged. Table generated and
    maintained by scripts/gen_lang.py (Italian uses ASCII apostrophes,
    fonts are 0x20-0x7F).
    - New Language setting (Settings roller, English/Italiano): saved to
    FilMachine.json, applied at boot; changing it saves synchronously,
    shows a popup and reboots automatically. Exposed over WebSocket
    (set_setting 'language') and added to genFilMachineCFG.py.
    - Previously hardcoded English translated too: drain-machine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
    [partitions.csv]
2026-07-07 Add configurable screen-off timeout setting (5/10/30 min/never, EN+IT)
    New 'Screen off timeout' row in Settings (roller with Cancel/Set, like
    the other pickers): 5 / 10 / 30 minutes or Never. One user-facing value;
    the two dim stages are derived automatically (50% at 1/10 of the time,
    20% at half). Applied immediately via st7701_lcd_set_dim_timeout — no
    reboot needed. Default 10 min matches the previous hardcoded behaviour
    (1min→50%, 5min→20%, 10min→off); dimming stays inhibited while a
    process is running.
    Persisted as 'screenOffMins' in FilMachine.json (missing key defaults
    to 10, so existing configs are unaffected), included in factory reset,
    genFilMachineCFG.py, and exposed over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
    [FilMachine.h, page_settings.c]
2026-07-09 Add files via upload
    Lista componenti utilizzate nel progetto
    [DistintaComponenti.xlsx]
2026-10-08 3D Models
    [01_flangia_A.step, 01_flangia_A.stl, 02_flangia_B.step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]
2026-10-08 Docs: bring README up to date and add the reel auto-loader section
    README corrections, each checked against the repository:
    - LVGL is 9.5.0 (CMake clone tag and idf_component.yml), not 9.2.2
    - the config files are FilMachine.json / FilMachine_Backup.json, not .cfg
    - the P4 helper script is flash_p4.sh; flash.sh and setup.sh are
    leftovers of the ESP32-S3 workflow
    - the simulator's sd/ folder is relative to the launch directory
    - version.txt (MAJOR.MINOR.PATCH.BUILD) and bump_version.sh
    - directory tree: page_debug.c, the calibration/speed/fill popups,
    scripts, hardware/, 3D_Models/, docs/, tools/, CI workflow, root files
    - the companion app lives in FilMachine_App; the state has 71 fields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
2026-10-08 WS: report the running firmware version instead of the fixed v0.0.0.1
    build_state_json() sent the softwareVersionValue_text macro ("v0.0.0.1")
    as fwVersion, so the companion app always showed that value. Use
    ota_get_running_version(), the same source as the splash and the Tools
    page (version.txt on the board, FW_VERSION_STR in the simulator).
    Checked in the simulator: fwVersion over WebSocket went from "v0.0.0.1"
    to "0.0.0.54". The 18 test suites that complete on main give the same
    162 passed / 2 failed with and without this change (the two failures
    and the Settings suite are stale tests, unrelated). Not built with
    ESP-IDF and not tested on the board.
2026-10-08 Docs: current firmware size and a note on dependencies.lock paths
    - OTA section: the firmware is about 2.5 MB (59% of a 6 MB slot free),
    measured on a clean ESP-IDF 5.5 build of v0.0.0.54; the README still
    said 1.9 MB / 68%
    - Troubleshooting: dependencies.lock stores the absolute path of the
    local esp_lcd_touch component, so configuring fails after the project
    folder is moved or on another machine; say how to fix it and what
    deleting the lock file changes
2026-10-08 App sync: fill_start/fill_stop over WebSocket, live temps in state, Wi-Fi popup layout, Save-button dirty fix, app string export
    - ws_server: fill_start {target} / fill_stop commands (open the on-screen fill
    popup and run it, so the display mirrors the app); fillTool* fields in the
    state broadcast; waterTemp/chemTemp now always carry the live compensated
    readings (were zero outside a process) for the app's temperature calibration
    - element_fillPopup: fillPopupRemoteStart/Stop sharing the Run/Stop toggle
    - element_wifiPopup: own popup size (560x420) and 200 px list — the OTA size
    (290) let the list run under the auto-connect/Connect row
    - page_processDetail: Save enabled by comparin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
    [FilMachine.h]
2026-10-08 App sync: remote Tune for pump / motor / volume (tune_test, tune_set, tune_cancel)
    The display's Tune popups (speed roller + live Test switch + SET; volume
    roller with preview tone) can now be driven by the app over WebSocket. The
    same popup opens on the display and follows the app (roller, Test switch),
    a 20 s watchdog stops a live test the app stops refreshing, and tune_set
    performs exactly the display's SET (stop, save, confirmation popup).
    set_setting filmRotationSpeed now also applies the live analog setpoint, as
    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
2026-10-08 3D models: keep only FilMachine_caricatore_v3, drop v1/v2 assemblies; firmware version 0.0.0.55
    [01_flangia_A.step, 01_flangia_A.stl, 02_flangia_B.step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]
2026-10-09 Film Load
    [01_flangia_A.step, 01_flangia_A.stl, 02_flangia_B.step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]
2026-10-09 Fixed alignent on clean machine
    [FilMachine.h]
2026-10-13 new board
2026-10-14 Fixed pcb
2026-10-17 PCB: mappa delle zone della Mainboard (moduli sostituiti)
    Aggiunge PCB/FilMachine_Mainboard_zone.png, vista dall'alto della scheda con le zone
    che sostituiscono Adafruit #6318, DBH-12V (motore/pompa), modulo IRF540 e
    convertitore 5 V, piu' le funzioni nuove; PCB/sorgenti/zones.py la rigenera dal
    render 3D di KiCad se la board cambia.
    Claude-Session: https://claude.ai/code/session_01DB89SqFcWBwuarcxKaz1vv
2026-10-22 new pcb
2026-10-23 PCB recheck Fable
